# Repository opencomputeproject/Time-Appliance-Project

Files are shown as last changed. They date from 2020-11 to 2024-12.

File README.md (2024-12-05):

To save spec as PDF - select text below (including images) -> right click -> Print -> Save as PDF
# Time Card
#### Spec revision № 1.0
Time Card is the heart of the [Open Time Server](http://www.opentimeserver.com) Project.

You can find the [IEEE publication](https://ieeexplore.ieee.org/document/9918379) for it.

In addition to the ongoing IEEE PAR (P3335: Standard for Architecture and Interfaces for Time Card) on this [link](https://standards.ieee.org/ieee/3335/11127/)

This spec can be accessed using http://www.timingcard.com or http://timecard.ch  

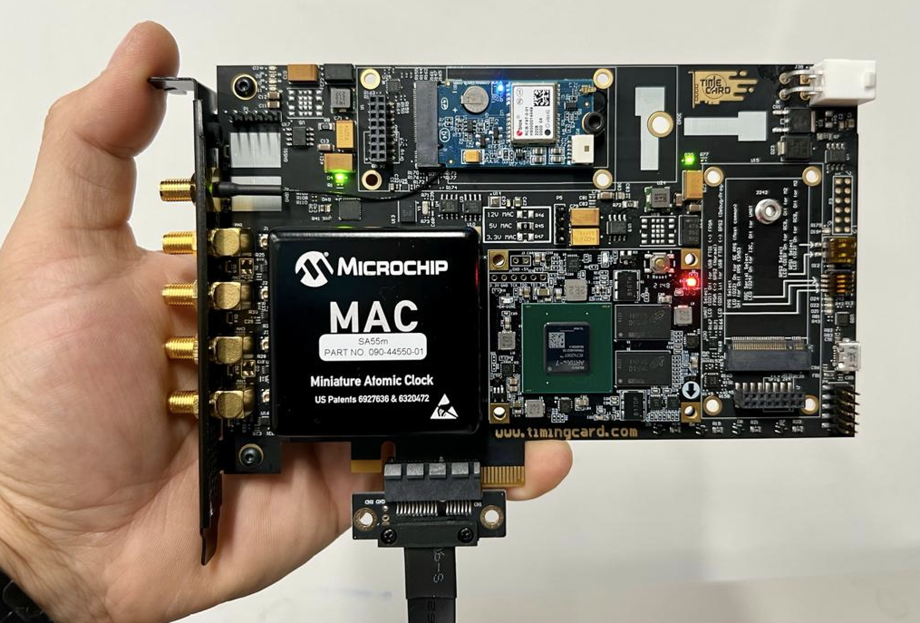
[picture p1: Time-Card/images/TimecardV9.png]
Time Card


## Table of Contents
1. [General](#General)
1. [Where can I get one](#Where-can-I-get-one)
1. [Form Factor](#Form-Factor)
1. [GNSS](#GNSS)
   1. [Receiver](#Receiver)
   1. [Security](#Security)
1. [Clock](#Clock)
1. [Bridge](#example)
   1. [Hardware Implementation](#Hardware-Implementation)
   1. [Software Implementation](#Software-Implementation)
1. [Interfaces](#Interfaces)
   1. [LED](#LED)
1. [Precision](#Precision)
1. [Repository content](#Repository-content)
1. [License](#License)

## List of images
List Of Images | Description
------------ | -------------
[Figure 1](#figure-1) | GNSS Receiver
[Figure 2](#figure-2) | Atomic Clock Example
[Figure 3](#figure-3) | Time Card Block Diagram
[Figure 4](#figure-4) | Bridge Block Diagram

## General

Time Server is a critical part of a PTP enabled network. It provides accurate time via GNSS while maintaining accuracy in case of GNSS failure via a high stability (and holdover) oscillator such as an atomic clock. Existing products in the market are often closed sourced and are far from having sufficient features. The Time Card project presents an open source solution via a PCIe card called Time Card which is called Open Time Server.

## Getting a Time Card

Here are 4 options to get your hands on this Time Card.

You can purchase the Time Card with the OCXO daughter card, the NEO-M9N RCB, fully programmed and assembled from Makerfabs. [Makerfabs Time Card](https://www.makerfabs.com/ocp-tap-time-card.html)

You have all necessary source code, BOM, Gerber files and binaries to build it yourself.
Follow these videos to Fabricate Time Cards with PCBWay, and purchase the accessories to assemble them.
* [Time Card PCBWay Fabrication and Assembly](https://www.youtube.com/watch?v=qPRaQU9TBTw)
* [Time Card Accessories](https://www.youtube.com/watch?v=4X3i5tge4S4)

The 3rd option is of course to source and produce the Time Card with the manufacturers you seek out yourself.

The 4th option is to purchase a Time Card available on the [OCP Marketplace](https://www.opencompute.org/products?refinementList%5Bhardware.categories.Cards%5D%5B0%5D=Time%20Cards) or other compatible Time Card from 3rd parties. Of course, this is the conveniet way to get your hands on a Time Card. Keep in mind, there is a cost associated with the vendors manufacturing the card and providing you all kinds of support in addition to their profit margins. It is good to know how much you are paying for parts and how much you are paying for the covenience.

## What is the price for parts of a Time Card

There are various parts that can sit on the Time Card as options and can change the total price. 
Here we have a breakdown:
* Time Card's mainboard: PCB with Assembly (Parts soldered on the PCB) should be about $200.
* Alinx SOM (AC7100B) should be about $250.
* GNSS recevier: The u-blox RCB-F9T is about $300. Other GNSS modules may vary in price based on their performance and capabilities in range of $50 to $500.
* Atomic Clock: The SA-53 is about $1995 (from microchipdirect). You can use a TCXO or OCXO board as well which can be around $100 - $200
So, in conclusion:
* A Time Card with a RCB-F9T GNSS and a TCXO costs about $200 + $250 + $300 + $100 = $850 in parts.
* A Time Card with a RCB-F9T GNSS and a MAC (SA-53) costs about $200 + $250 + $300 + $1995 = $2695 in parts.

## Time Card Derivatives
These are Time Cards made by other companies that are developed with different hardware yet compatible with the architecure and the driver of the Time Card:
* [Safran ART2](https://safran-navigation-timing.com/about-the-atomic-reference-time-card-art-card/) (fully open sourced and available on this [link](https://github.com/Orolia2s/art-card-board))
* [ADVA OSA5400](https://urldefense.com/v3/__https://www.oscilloquartz.com/en/products-and-services/embedded-timing-solutions/osa-5400-timecard__;!!Bt8RZUm9aw!74Qc6wh6_yFfgOhGUCr-rX5q6hd1NxC9HwjI7CwVO24C2SXXuzDXk4W3NjlSOZtTBWtvV11UzSicxA$)

## Form Factor
* Standard PCIe Stand-up Card
* Single Slot - Passive Cooling Solution
 
## GNSS
### Receiver
The GNSS receiver can be a product from ublock or any other vendor as long as it provides PPS output and the TOD using any suitable format.

This is the recommended module:  **u-blox RCB-F9T GNSS time module**

<a id="Figure-1">GNSS Receiver</a>
   
<p align="center">Figure 1. GNSS Receiver</p>

### Security
There are 2 main attack vectors on GNSS receiver
### Jamming
Jamming is the simplest form of attack. In order to keep operations while under attack the most reliable approach is to perform a long run holdover.  
See more about holdover in the [clock](#Clock) section.

### Spoofing
GNSS authenticity is relevant today. A mechanism to protect against over-the-air spoofing incidents is desirable.
With special equipment it is possible to simulate a GNSS constellation and spoof the receiver. Basic principals to protect against such attack:
* Use high-quality GNSS receivers which verify packet signature
* Disciplining implementations see more in [bridge](#bridge) section should protect against sudden jumps in time and space. For the datacenter use cases jump in space could be completely forbidden.

## Clock
GNSS requires "clear sky" to function properly. Moreover there were several historical events of a short term time jumps by some GNSS constallations.
Because of reliability and in combination with the security concerns an additional holdover should be performed by [high quality](https://www.meinbergglobal.com/english/specs/gpsopt.htm) XO. An example could be AC, OCXO, TCXO etc.
In order to perform sustainable operation we recommend to use an AC with a holdover ± 1us or HQ OCXO with a holdover ± 22 µs.

Atomic clock examples:
* [SA5X](https://www.microsemi.com/product-directory/embedded-clocks-frequency-references/5570-miniature-atomic-clock-mac-sa5x)
* [LN CSAC](https://www.microsemi.com/product-directory/embedded-clocks-frequency-references/4518-low-noise-csac-ln-csac)
* [mRO-50](https://www.orolia.com/products/atomic-clocks-oscillators/mro-50)
* [SA.45s](https://www.microsemi.com/product-directory/embedded-clocks-frequency-references/5207-space-csac)
* [DTA-100](https://www.taitien.com/wp-content/uploads/2021/10/XO-0191-Low-Power-Atomic-Oscillator-DTA-100-Series.pdf)

<p align="center">
microchip-mac-sa5x
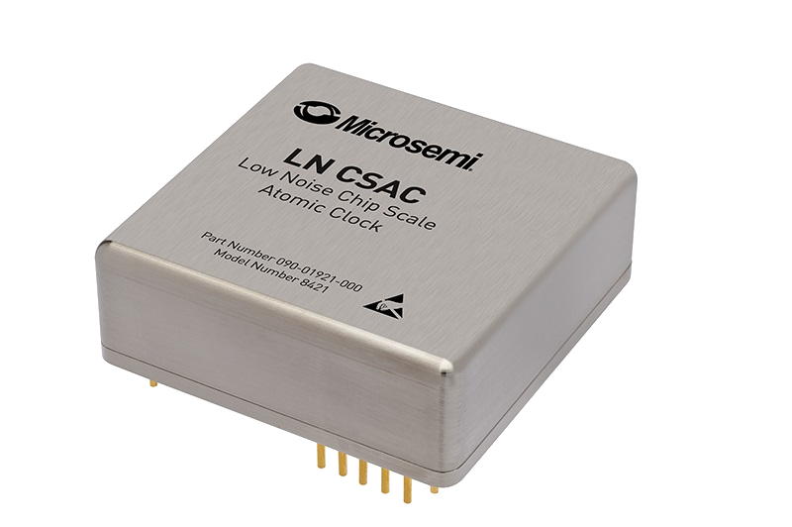
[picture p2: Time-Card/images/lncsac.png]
microchip-ln-csac

orolia-mro-50
microchip-mac-sa4x
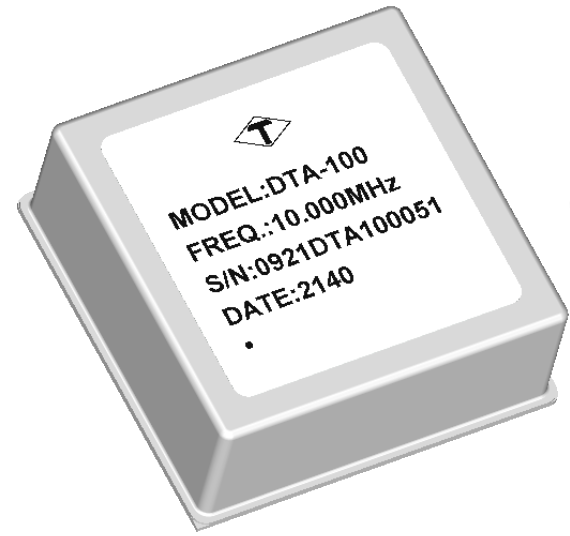
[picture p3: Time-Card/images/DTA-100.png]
taitien-dta-100

   
</p>

<p align="center">Figure 2. Atomic Clock Examples</p>

OCXO examples:
* [SiT5711](https://www.sitime.com/products/stratum-3e-ocxos/sit5711)
SiTime-SiT5711

* [DT-5151](https://www.taitien.com/ti-products/ultra-high-precision-disciplined-oscillator-dt-5151-series)
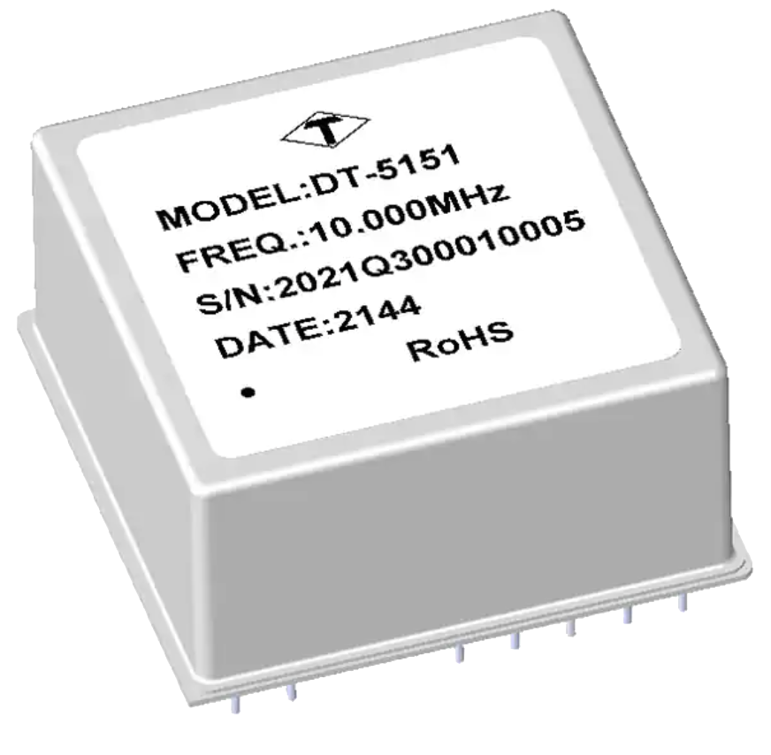
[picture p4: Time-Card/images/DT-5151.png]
taitien-dt-5151


* ROD2522S2 from Rakon, PPS disciplined oscillator

* Taitien PN: NJ-10M-075 , Stratum 3E oscillator footprint compatible with ROD2522S2

TCXO examples:
* [SiT5356](https://www.sitime.com/products/super-tcxo/sit5356)
SiT5356

* SiT5501 Super-TCXO

* Taitien PN: M0166-T-001-3 , footprint compatible with SiT5501 family

## Bridge

The bridge between the GNSS receiver and the Atomic clock can be implemented using software or hardware solutions. The hardware implementation is preferred and is our end goal.

### Hardware Implementation
Here is one of the examples of hardware implementations.
* FPGA is responsible for most of the functionality
* Exposed /dev/phc and /dev/pps are read by open source software such as ptp4l and chronyd

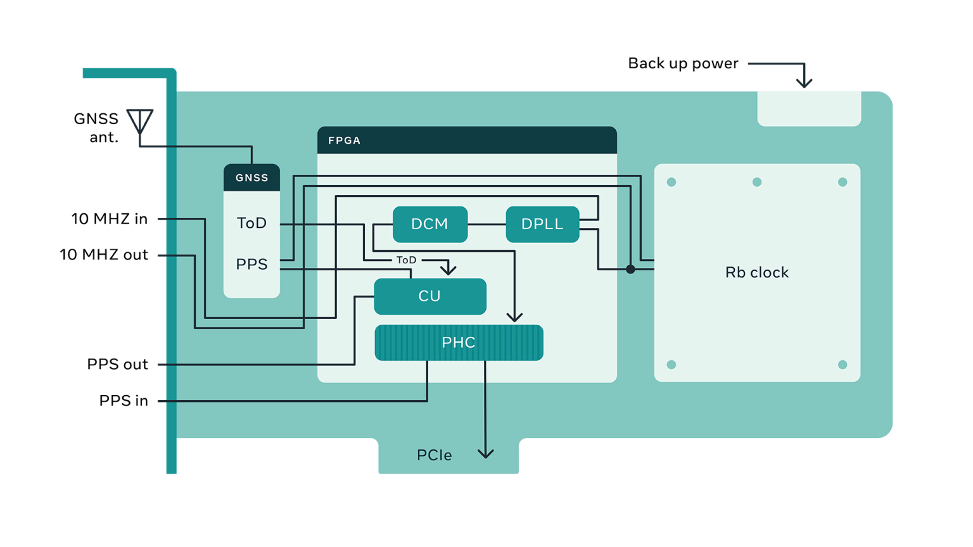
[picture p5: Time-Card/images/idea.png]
Time Card - Block Diagram


<p align="center">Figure 3. Time Card Block Diagram</p>

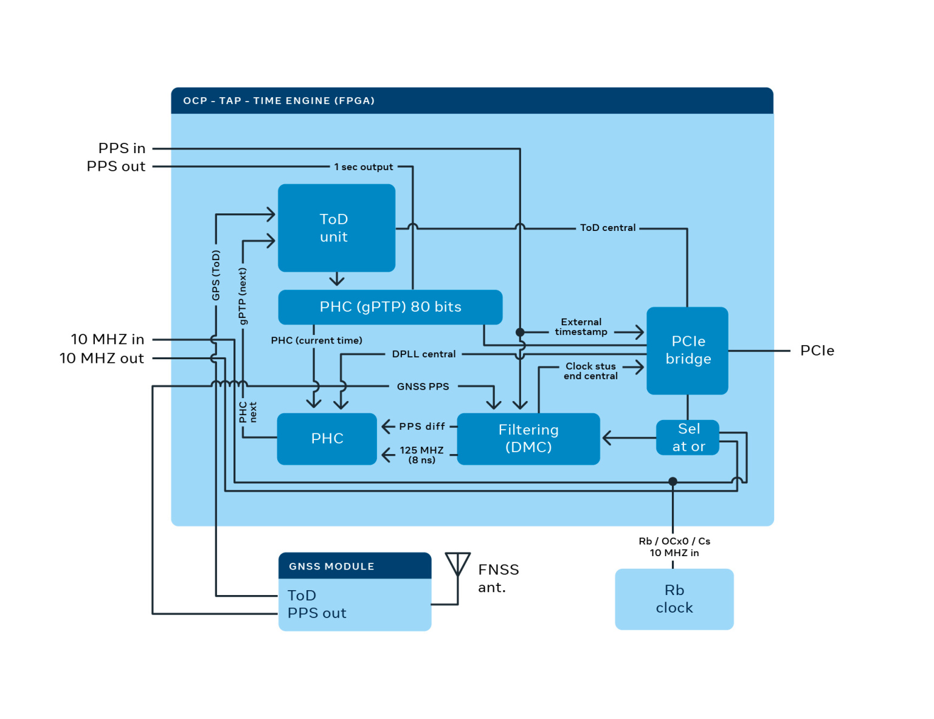
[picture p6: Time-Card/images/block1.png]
Bridge Block Diagram

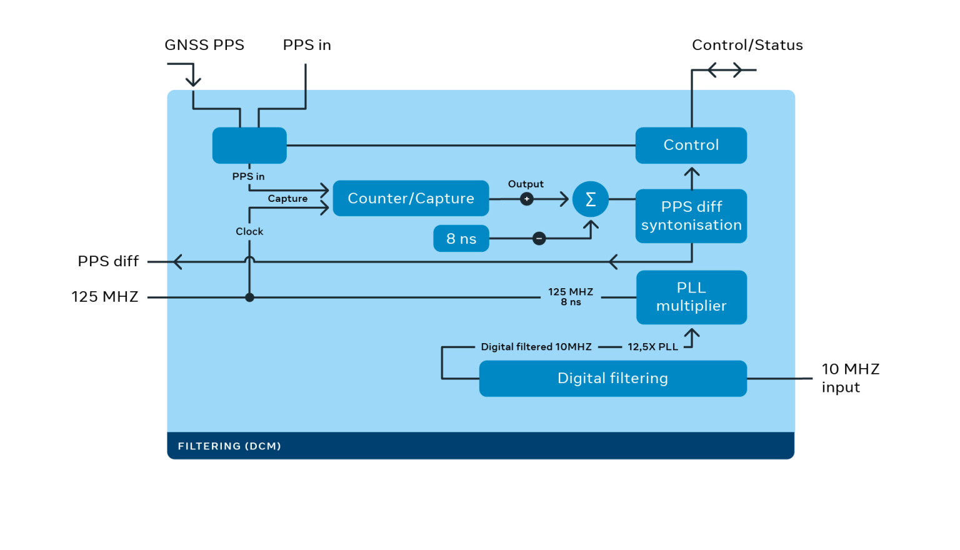
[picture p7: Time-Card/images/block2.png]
Bridge Block Diagram

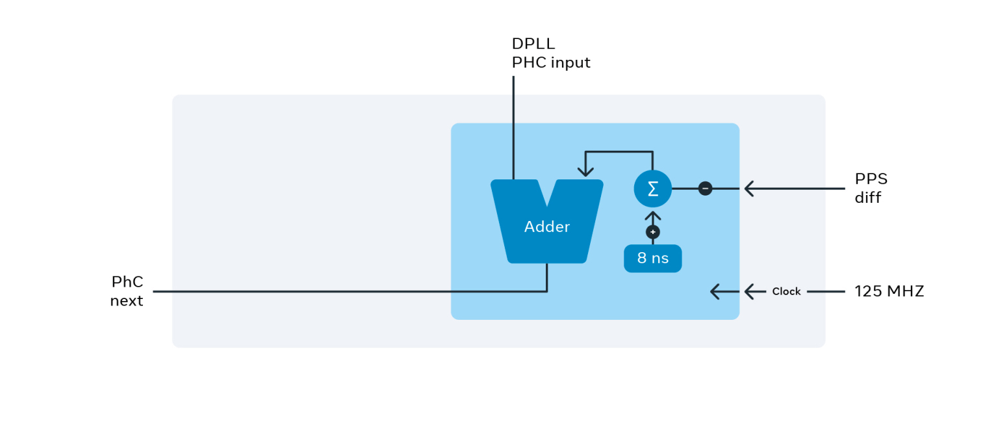
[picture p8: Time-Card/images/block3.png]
Bridge Block Diagram


<p align="center">Figure 4. Bridge Block Diagram</p>

### Software Implementation
Software implementation still requires most of the components, however the communication between components is done with user space software:
* GPSd exposing /dev/ppsY and provides TOD via SHM
* FPGA board reads 1 PPS from different sources
* Host daemon monitors the offset and steers oscillator
* phc2sys can copy data between clocks, including between GPSd and Atomic and then Atomic to PHC on the NIC

## Interfaces
* PCIe
    * PCIe x1 (18 pins) generation 1.0 or above on a x4 form-factor
    * Generic, supporting multiple OS versions
    * Exposes PHC device in Linux (/dev/ptpX) as well as PPS (/dev/ppsY)
    * Exposes leap second indicator to a shared memory segment read by chrony/ptp4l
* 1PPS / 10MHz SMA output
* 1PPS / 10MHz SMA input
* IRIG-B input output
* DCF77 input output
* GNSS Antenna SMA input

### LED

An LED should be used to provide externally visible status information of the time card. 

For example:
* Off - card is not powered or not properly fitted
* Solid green - card is powered, GNSS ok, 1PPS/10MHz output ok
* Flashing green - card is in warm-up, acquiring satellites
* Solid red - alarm / malfunction

# Precision
Time card got 4 SMA connectors that can be configured as outputs and outputs for various things such as 10Mhz, PHC, MAC, GNSS, GNSS2, IRIG, DCF for output and 10Mhz, PPS1, PPS2, TS1, TS2, IRIG, DCF for input.  
Using a Calnex Sentinel device are comparing various things. Here we are comparing the 1PPS output (Channel A) and the 10Mhz output (Channel B) from the MAC (SA.53).  
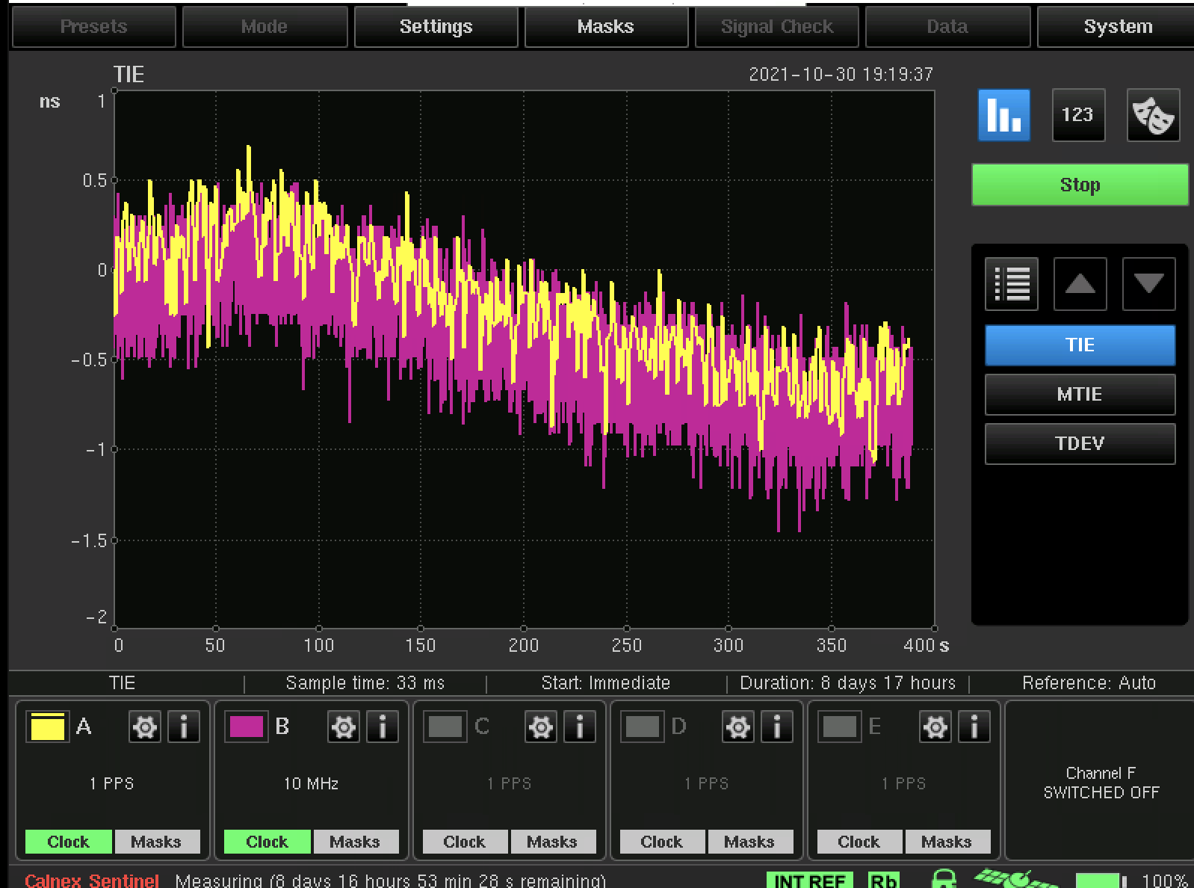
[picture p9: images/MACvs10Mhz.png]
Initial design


# Repository content

* Bill of Materials (parts from Digikey)
* Schematic and PCB of the time card
* Driver (Kernel Module) CentOS 8
* CAD files for the custom PCIe bracket 

# Credits
Hereby we would like to thank these individuals who helped with the initiative, archirecture, design, software development, hardware issue maintanance and upgrades.
Individual | Main Contribution
---------------- | -------------
[Mike Lambeta](https://github.com/AlphaBetaPhi)     | Layout and Schematic Design
[Oleg Obleukhov](https://github.com/leoleovich)   | Open Time Server Software
[Jonathan Lemon](https://github.com/jlemon)   | Inital Linux Driver
[Thomas Schaub](https://github.com/thschaub)    | FPGA Design and Code
Joyce Hsu        | Logo Design
[Armando Pinales](https://github.com/armando-jp)  | RCB Boards
[Julian St.James](https://github.com/julianstj1)  | Hardware Upgrade
[Vadim Fedorenko](https://github.com/vvfedorenko)  | Driver Upgrade
[Spencer Burns](https://github.com/spencerburns)    | PCIe Bracket Design
Collin Richardson| Placement Optimization
[Nhan Hoang](https://github.com/nhanhoang83)       | PCIe Bracket Upgrade
[Ahmad Byagowi](https://github.com/ahmadexp)    | Initial Idea and Architecture

# License
Contributions to this Specification are made under the terms and conditions set forth in Open Web Foundation Contributor License Agreement (“OWF CLA 1.0”) (“Contribution License”) by: 
 
 Facebook

You can review the signed copies of the applicable Contributor License(s) for this Specification on the OCP website at http://www.opencompute.org/products/specsanddesign 
Usage of this Specification is governed by the terms and conditions set forth in Open Web Foundation Final Specification Agreement (“OWFa 1.0”) (“Specification License”).   
 
You can review the applicable Specification License(s) executed by the above referenced contributors to this Specification on the OCP website at http://www.opencompute.org/participate/legal-documents/
 Notes: 
 
1)     The following clarifications, which distinguish technology licensed in the Contribution License and/or Specification License from those technologies merely referenced (but not licensed), were accepted by the Incubation Committee of the OCP:  
 
None

NOTWITHSTANDING THE FOREGOING LICENSES, THIS SPECIFICATION IS PROVIDED BY OCP "AS IS" AND OCP EXPRESSLY DISCLAIMS ANY WARRANTIES (EXPRESS, IMPLIED, OR OTHERWISE), INCLUDING IMPLIED WARRANTIES OF MERCHANTABILITY, NON-INFRINGEMENT, FITNESS FOR A PARTICULAR PURPOSE, OR TITLE, RELATED TO THE SPECIFICATION. NOTICE IS HEREBY GIVEN, THAT OTHER RIGHTS NOT GRANTED AS SET FORTH ABOVE, INCLUDING WITHOUT LIMITATION, RIGHTS OF THIRD PARTIES WHO DID NOT EXECUTE THE ABOVE LICENSES, MAY BE IMPLICATED BY THE IMPLEMENTATION OF OR COMPLIANCE WITH THIS SPECIFICATION. OCP IS NOT RESPONSIBLE FOR IDENTIFYING RIGHTS FOR WHICH A LICENSE MAY BE REQUIRED IN ORDER TO IMPLEMENT THIS SPECIFICATION.  THE ENTIRE RISK AS TO IMPLEMENTING OR OTHERWISE USING THE SPECIFICATION IS ASSUMED BY YOU. IN NO EVENT WILL OCP BE LIABLE TO YOU FOR ANY MONETARY DAMAGES WITH RESPECT TO ANY CLAIMS RELATED TO, OR ARISING OUT OF YOUR USE OF THIS SPECIFICATION, INCLUDING BUT NOT LIMITED TO ANY LIABILITY FOR LOST PROFITS OR ANY CONSEQUENTIAL, INCIDENTAL, INDIRECT, SPECIAL OR PUNITIVE DAMAGES OF ANY CHARACTER FROM ANY CAUSES OF ACTION OF ANY KIND WITH RESPECT TO THIS SPECIFICATION, WHETHER BASED ON BREACH OF CONTRACT, TORT (INCLUDING NEGLIGENCE), OR OTHERWISE, AND EVEN IF OCP HAS BEEN ADVISED OF THE POSSIBILITY OF SUCH DAMAGE.

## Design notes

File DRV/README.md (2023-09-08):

# Driver

Driver is based on a kernel module for CentOS and Ubunutu. 
Kernel 5.12+ is recommended

## Instruction
Make sure vt-d option is enabled in BIOS.   
Run the remake followed by modprobe ptp_ocp

## Outcome
```
$ ls -g /sys/class/timecard/ocp0/
total 0
-r--r--r--. 1 root 4096 Sep  8 18:20 available_clock_sources
-r--r--r--. 1 root 4096 Sep  8 18:20 available_sma_inputs
-r--r--r--. 1 root 4096 Sep  8 18:20 available_sma_outputs
-rw-r--r--. 1 root 4096 Sep  8 18:20 clock_source
lrwxrwxrwx. 1 root    0 Sep  8 18:20 device -> ../../../0000:02:00.0
-rw-r--r--. 1 root 4096 Sep  8 18:20 external_pps_cable_delay
-r--r--r--. 1 root 4096 Sep  8 18:20 gnss_sync
-rw-r--r--. 1 root 4096 Sep  8 18:20 internal_pps_cable_delay
-rw-r--r--. 1 root 4096 Sep  8 18:20 irig_b_mode
-rw-r--r--. 1 root 4096 Sep  8 18:20 pci_delay
drwxr-xr-x. 2 root    0 Sep  8 18:20 power
lrwxrwxrwx. 1 root    0 Sep  8 18:20 ptp -> ../../ptp/ptp4
-r--r--r--. 1 root 4096 Sep  8 18:20 serialnum
-rw-r--r--. 1 root 4096 Sep  8 18:20 sma1_in
-rw-r--r--. 1 root 4096 Sep  8 18:20 sma2_in
-rw-r--r--. 1 root 4096 Sep  8 21:04 sma3_out
-rw-r--r--. 1 root 4096 Sep  8 21:04 sma4_out
lrwxrwxrwx. 1 root    0 Sep  8 18:20 subsystem -> ../../../../../../class/timecard
lrwxrwxrwx. 1 root    0 Sep  8 18:20 ttyGNSS -> ../../tty/ttyS5
lrwxrwxrwx. 1 root    0 Sep  8 18:20 ttyMAC -> ../../tty/ttyS6
lrwxrwxrwx. 1 root    0 Sep  8 18:20 ttyNMEA -> ../../tty/ttyS7
-rw-r--r--. 1 root 4096 Sep  8 18:20 uevent
-rw-r--r--. 1 root 4096 Sep  8 18:20 utc_tai_offset
```

The main resource directory is accessed through the /sys/class/timecard/ocpN directory, which provides links to the various TimeCard resources.  The device links can easily be used in scripts:

```
  tty=$(basename $(readlink /sys/class/timecard/ocp0/ttyGNSS))
  ptp=$(basename $(readlink /sys/class/timecard/ocp0/ptp))

  echo "/dev/$tty"
  echo "/dev/$ptp"
```

After successfully loading the driver, one will see:
* PTP POSIX clock, linking to the physical hardware clock (PHC) on the Time Card (`/dev/ptp4`) 
* GNSS serial `/dev/ttyS5` 
* Atomic clock serial `/dev/ttyS6`
* NMEA Master serial `/dev/ttyS7`
* i2c (`/dev/i2c-*`) device

Now, one can use standard `linuxptp` tools such as `phc2sys` or `ts2phc` to copy, sync, tune, etc... See more in [software](/Software) section

## Driver is included in the mainstream Linux Kernel
* Initial primitive version ([5.2](https://git.kernel.org/pub/scm/linux/kernel/git/netdev/net-next.git/commit/?id=a7e1abad13f3f0366ee625831fecda2b603cdc17))
* Exposing all devices version ([5.15](https://git.kernel.org/pub/scm/linux/kernel/git/torvalds/linux.git/commit/?id=773bda96492153e11d21eb63ac814669b51fc701))

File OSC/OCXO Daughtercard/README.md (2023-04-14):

# OCXO Daughter Card
A daughter card compatible with the LOFF atomic clock footprint of the Time Card to support various OCXOs from different vendors.

Developed by Christopher Robles, David Griffin, Julian St. James, Ahmad Byagowi, Mike Lambeta for Time Card usage.

Current oscillators supported:
1. Abracon AOCJYR
2. Rakon ROD2552S2
3. SiTime SiT5711 / SiT5721
4. SiTime SiT5501
5. Rakon RFP045

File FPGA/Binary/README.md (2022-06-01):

# FPGA Binary Sources
The FPGA design based on NetTimeLogic Cores is available as binary-only (bitstream) specifically for the Timecard, which however can be used free of charge without restrictions.

The binaries are for two different hardware versions available:

- **Production** 

- **SOM** (System On Module)

More details can be found in the subfolders.

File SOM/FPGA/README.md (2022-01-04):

# System on Module

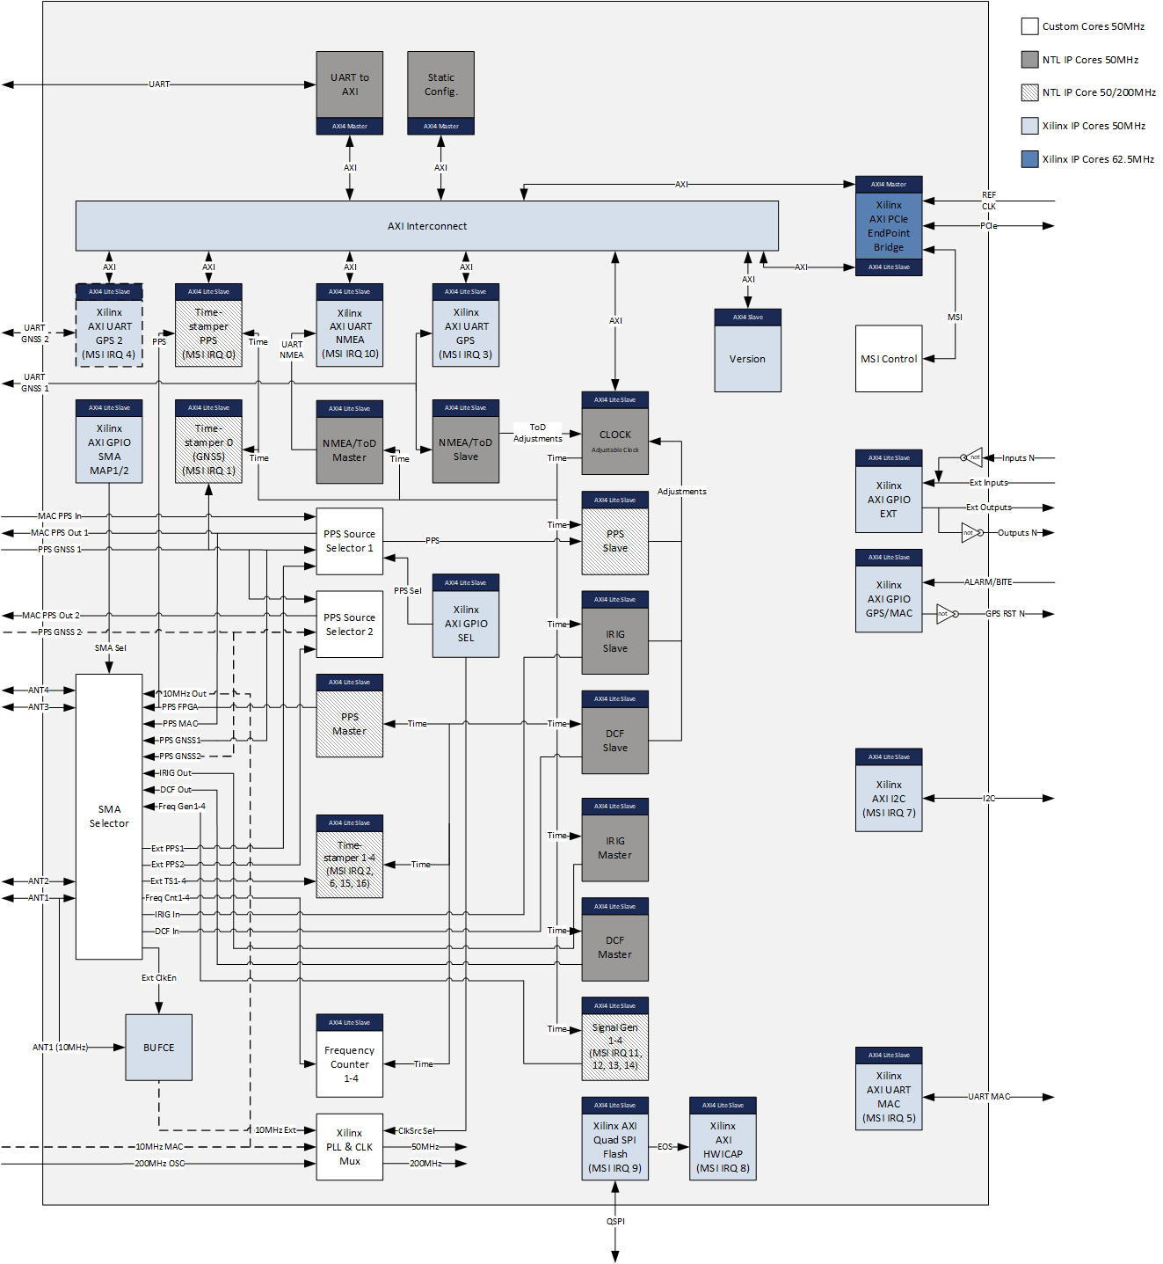
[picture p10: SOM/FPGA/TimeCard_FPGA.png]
Time Card FPGA


The FPGA bitstream can be configured to various options. Currently it is based on the [NetTimeLogic clock module](https://www.nettimelogic.com/clock-products.php).  <br />

Check the [Readme.pdf](https://github.com/opencomputeproject/Time-Appliance-Project/blob/master/Time-Card/SOM/FPGA/Readme.pdf) for more details about the implementation.  <br />

In the [Doc folder](https://github.com/opencomputeproject/Time-Appliance-Project/tree/master/Time-Card/SOM/FPGA/Doc) are all relevant documents about the integrated IP Cores (e.g. register description). <br />

## The FPGA starts with a static configuration with following settings: ##
* PPS (including TOD) is used as correction input for the clock  
* PPS Slave Pulse detection on rising edge
* PPS Slave cable delay 0
* TOD Slave UART Baudrate is 115200
* TOD Slave UART polarity default
* TOD Slave in UBX Mode, all GNSS and no messages disabled
* PPS Master polarity rising edge
* PPS Master cable delay 0
* PPS Master pulse width 100 ms
* Clock, PPS Slave, TOD Slave and PPS Master are enabled
* All Timestampers are disabled
* IRIG Slave/Master are disabled
* DCF Slave/Master are disabled
* TOD/NMEA Master is disabled

## In the Binaries folder are the bitstreams for the SOM Module. ## 
* TimeCard.bit to flash the FPGA (volatile)
* Factory_TimeCard.bin to load the SPI flash via JTAG (Golden Image + Update Image)
* TimeCard.bin to updated the SPI flash via SPI starting @ 0x00400000 (Update Image only)
    
The version for AX7103 will be not longer maintained. 

## Firmware upgrade
```
$ dmesg | grep ptp_ocp | head -1
[   21.527678] ptp_ocp 0000:11:00.0: enabling device (0140 -> 0142)
$ cp TimeCard.bin /lib/firmware
$ devlink dev flash pci/0000:11:00.0 file TimeCard.bin
```

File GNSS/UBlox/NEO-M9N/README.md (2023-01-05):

# UBX NEO-M9N GNSS module
 Module has not been tested with Time Card.

## Programming the GNSS module

To program the GNSS module you can either use the UBX provided hardware or a simple FTDI-TTL3v3 cable (please note, you have to use the 3v3 version oppose to the 5v). Here is a simple wiring digram to program the GNSS module.

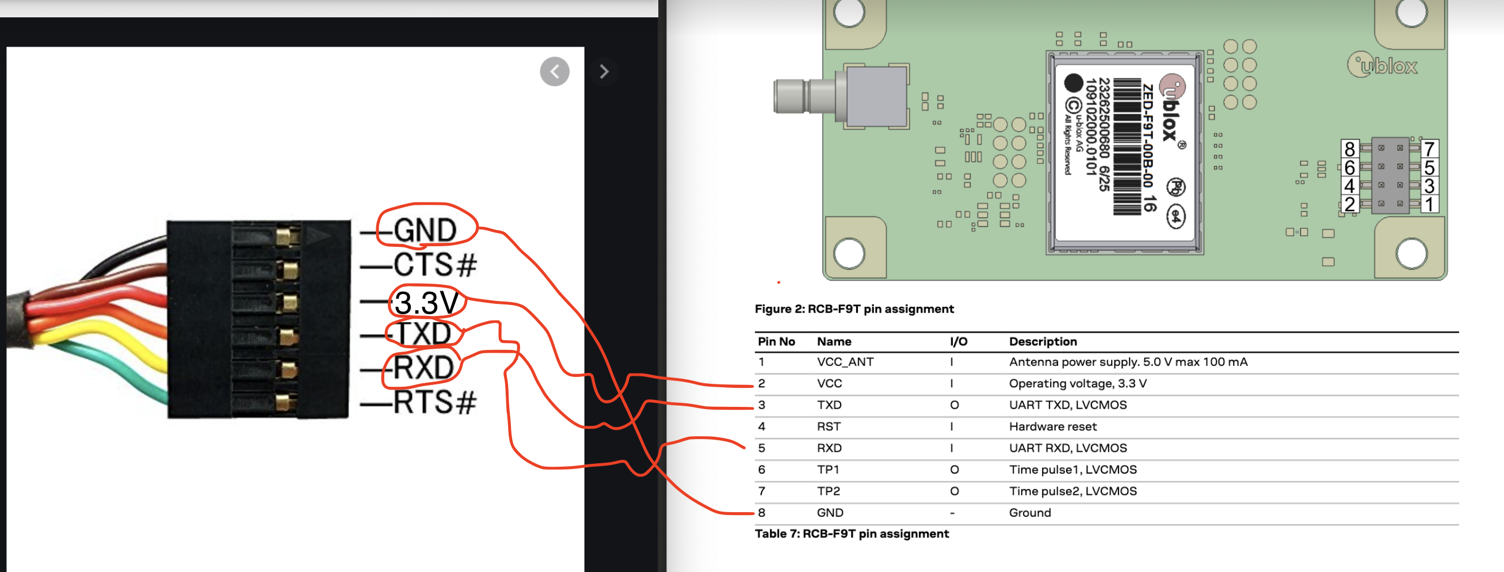
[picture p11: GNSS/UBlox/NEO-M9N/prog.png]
UBX GNSS simple programmer


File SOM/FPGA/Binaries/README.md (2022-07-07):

# SOM Module Binaries
- **200T** TimeCard FPGA binaries for the SOM with the Artix7 200T FPGA (AC7200)
- **AX7103_Baseboard** TimeCard FPGA binaries for the AX7103 base board (not maintained anymore)
- **Debug** TimeCard FPGA binaries for special debug use cases (not maintained anymore)
- **FirmwareUpdateTest** TimeCard FPGA binaries for firmware update tests

## In this folder are the bitstreams for the SOM Module. ## 
* TimeCard.bit to flash the FPGA (volatile)
* Factory_TimeCard.bin to load the SPI flash via JTAG (Golden Image + Update Image)
* TimeCard.bin to updated the SPI flash via SPI starting @ 0x00400000 (Update Image only)
* TimeCard_Gotham.bin is basically the same as TimeCard.bin but the file has additional header information ([See tft tool](https://github.com/opencomputeproject/Time-Appliance-Project/tree/master/Software/tft))
    
The version for AX7103 will be not longer maintained. 

## Firmware upgrade
```
$ dmesg | grep ptp_ocp | head -1
[   21.527678] ptp_ocp 0000:11:00.0: enabling device (0140 -> 0142)
$ cp TimeCard.bin /lib/firmware
$ devlink dev flash pci/0000:11:00.0 file TimeCard.bin
```

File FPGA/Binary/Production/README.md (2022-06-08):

***!! Important !!***

This version is **NOT** compatible with the SOM Module (e.g. AC7100B).
The binaries for the Time Card with the **System On Module (SOM)** can be found here:
[SOM Version](../../../SOM)

# FPGA for the production version of the Time Card
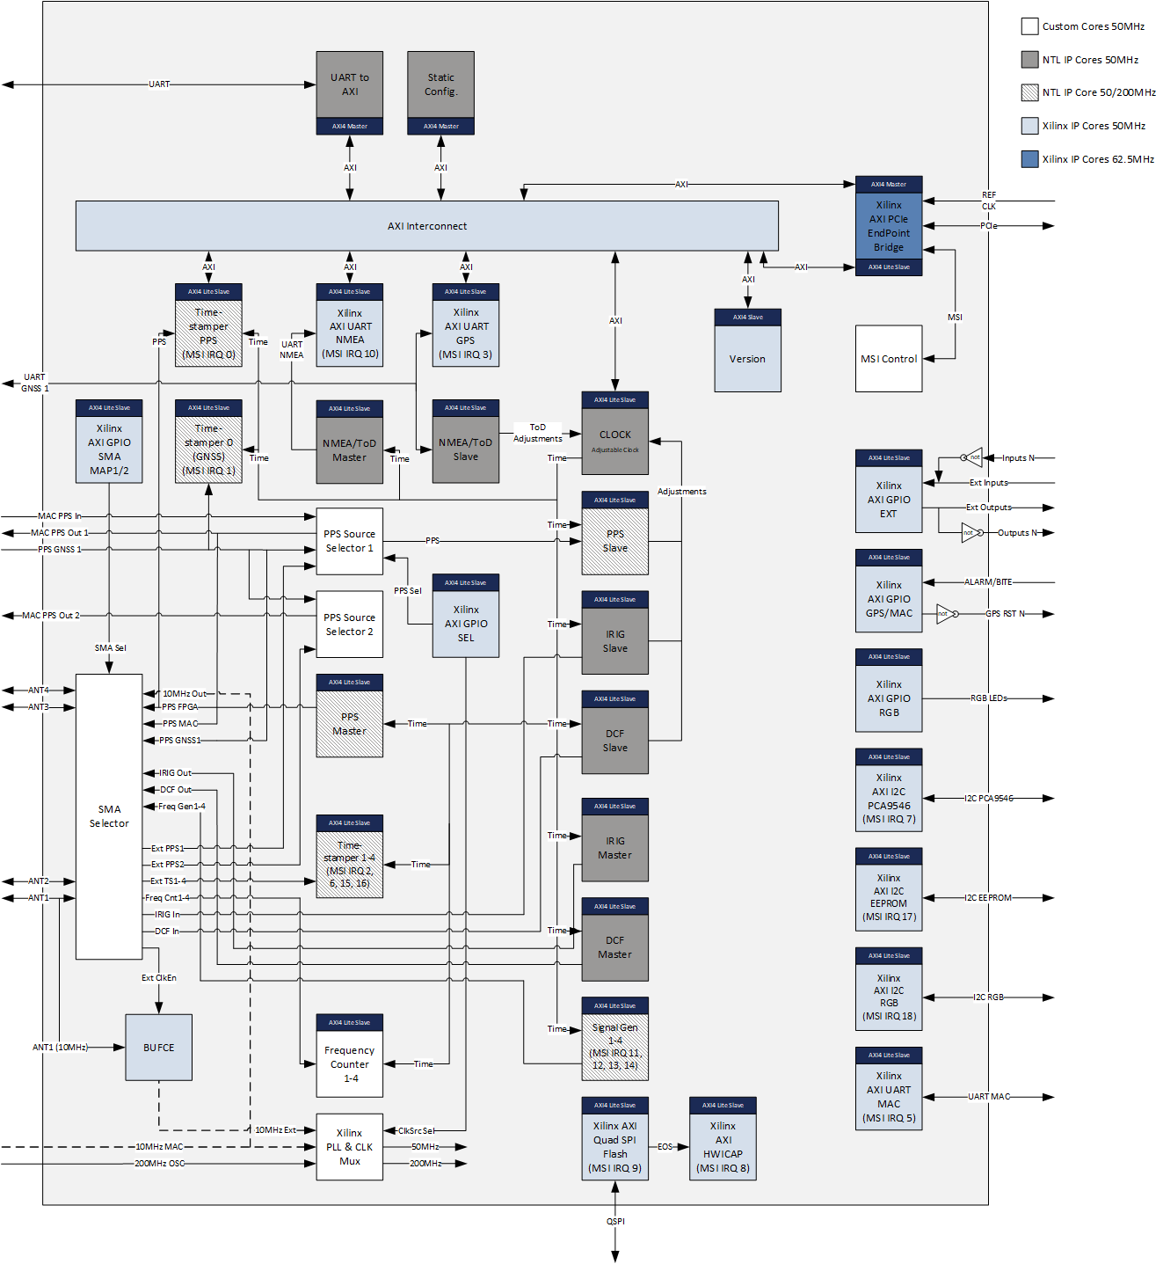
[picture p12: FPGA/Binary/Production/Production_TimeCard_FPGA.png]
Production Time Card FPGA


The FPGA bitstream can be configured to various options. Currently it is based on the [NetTimeLogic clock module](https://www.nettimelogic.com/clock-products.php). <br />

Check the [Readme_Production.pdf](Readme_Production.pdf) for more details about the implementation. <br />

In the [Doc folder](../../../SOM/FPGA/Doc) are all relevant documents about the integrated IP Cores (e.g. register description). <br />

## The FPGA starts with a static configuration with following settings: ##
* PPS (including TOD) is used as correction input for the clock  
* PPS Slave Pulse detection on rising edge
* PPS Slave cable delay 0
* TOD Slave UART Baudrate is 115200
* TOD Slave UART polarity default
* TOD Slave in UBX Mode, all GNSS and no messages disabled
* PPS Master polarity rising edge
* PPS Master cable delay 0
* PPS Master pulse width 100 ms
* Clock, PPS Slave, TOD Slave and PPS Master are enabled
* All Timestampers are disabled
* IRIG Slave/Master are disabled
* DCF Slave/Master are disabled
* TOD/NMEA Master is disabled

## In the Binaries folder are the bitstreams for the FPGA. ## 
* TimeCardProduction.bit to flash the FPGA (volatile)
* Factory_TimeCardProduction.bin to load the SPI flash via JTAG (Golden Image + Update Image)
* TimeCardProduction.bin to updated the SPI flash via SPI starting @ 0x00400000 (Update Image only)
    
## Firmware upgrade
```
$ dmesg | grep ptp_ocp | head -1
[   21.342167] ptp_ocp 0000:11:00.0: enabling device (0140 -> 0142)
$ cp TimeCardProduction.bin /lib/firmware
$ devlink dev flash pci/0000:11:00.0 file TimeCardProduction.bin
```

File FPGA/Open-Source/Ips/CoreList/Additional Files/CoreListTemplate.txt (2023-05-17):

// Core Type Nr:
// Invalid/End                          0x0
// TC Core List Core Type               0x1
// TC Adjustable Clock Core Type        0x2
// TC Signal Generator Core Type        0x3
// TC Signal Timestamper Core Type      0x4
// TC PPS Generator Core Type           0x5
// TC Frequency Counter                 0x6
// TC Clock Detector Core Type          0x7
// TC SMA Selector Core Type            0x8
// TC PPS Source Selector Core Type     0x9
// TC FPGA Version Core Type            0xA
// TC PPS Slave Core Type               0xB
// TC TOD Slave Core Type               0xC
// TC Dummy Axi Slave Core Type         0xD
// Xilinx AXI PCIe Core Type            0x10000
// Xilinx AXI GPIO Core Type            0x10001
// Xilinx AXI IIC Core Type             0x10002
// Xilinx AXI UART Core Type            0x10003
// Xilinx AXI HWICAP Core Type          0x10004
// Xilinx AXI QUAD SPI FLASH Core Type  0x10005

// Core Inst Nr range: [0 - (N-1)], where N is the number of instantiations of the core in the design

// Version Nr has the format 0xMMmmBBBB, where MM is the Major version (8 bits), mm is the Minor version (8 bits), BBBB is the Built version (16 bits)

// AddressRangeLow is the offset address of the core's AXI slave, 0xFFFFFFFF when the core does not have AXI slave

// AddressRangeHigh is the highest address of the core's AXI slave

// Interrupt Nr range: [0x0-0x1F], 0xFFFFFFFF when the core does not have Interrupt

// Interrupt Sensitivity: bit0: 0=Edge/1=Level bit1: 0=ActiveLow/1=ActiveHigh

// Magic Word: Core in ascii chars (maximum "TextWidth_Con" number of ascii chars)

// CoreTypeNr CoreInstNr VersionNr AddressRangeLow AddressRangeHigh InterruptNr Sensitivity MagicWord
00000001 00000000 00010000 01300000 0130FFFF FFFFFFFF FFFFFFFF TC Core List
00000002 00000000 00010000 01000000 0100FFFF FFFFFFFF FFFFFFFF TC Adj Clock
00000003 00000000 00010000 010D0000 010DFFFF 0000000B 00000002 TC Sig Generator 1
00000003 00000001 00010000 010E0000 010EFFFF 0000000C 00000002 TC Sig Generator 2
00000003 00000002 00010000 010F0000 010FFFFF 0000000D 00000002 TC Sig Generator 3
00000003 00000003 00010000 01100000 0110FFFF 0000000E 00000002 TC Sig Generator 4
00000004 00000000 00010000 01010000 0101FFFF 00000001 00000002 TC Sig Timestamper GNSS PPS
00000004 00000001 00010000 01020000 0102FFFF 00000002 00000002 TC Sig Timestamper 1
00000004 00000002 00010000 01060000 0106FFFF 00000006 00000002 TC Sig Timestamper 2
00000004 00000003 00010000 010C0000 010CFFFF 00000000 00000002 TC Sig Timestamper FPGA PPS
00000004 00000004 00010000 01110000 0111FFFF 0000000F 00000002 TC Sig Timestamper 3
00000004 00000005 00010000 01120000 0112FFFF 00000010 00000002 TC Sig Timestamper 4
00000005 00000000 00010000 01030000 0103FFFF FFFFFFFF FFFFFFFF TC PPS Generator
00000006 00000000 00010000 01200000 0120FFFF FFFFFFFF FFFFFFFF TC Freq Counter 1
00000006 00000001 00010000 01210000 0121FFFF FFFFFFFF FFFFFFFF TC Freq Counter 2
00000006 00000002 00010000 01220000 0122FFFF FFFFFFFF FFFFFFFF TC Freq Counter 3
00000006 00000003 00010000 01230000 0123FFFF FFFFFFFF FFFFFFFF TC Freq Counter 4
00000007 00000000 00010000 00130000 0013FFFF FFFFFFFF FFFFFFFF TC Clock Detector
00000008 00000000 00010000 00140000 0014FFFF FFFFFFFF FFFFFFFF TC SMA Selector Inst0 Slave1
00000008 00000000 00010000 00220000 0022FFFF FFFFFFFF FFFFFFFF TC SMA Selector Inst0 Slave2
00000009 00000000 00010000 FFFFFFFF FFFFFFFF FFFFFFFF FFFFFFFF TC PPS Source Selector 0
00000009 00000001 00010000 FFFFFFFF FFFFFFFF FFFFFFFF FFFFFFFF TC PPS Source Selector 1
0000000A 00000000 00010000 00020000 00020FFF FFFFFFFF FFFFFFFF TC FPGA Version
0000000B 00000000 00010000 01040000 0104FFFF FFFFFFFF FFFFFFFF TC PPS Slave
0000000C 00000000 00010000 01050000 0105FFFF FFFFFFFF FFFFFFFF TC TOD Slave
00010000 00000000 02090000 00010000 00010FFF FFFFFFFF FFFFFFFF Xilinx AXI PCIe
00010001 00000000 02000000 00100000 0010FFFF FFFFFFFF FFFFFFFF Xilinx AXI GPIO ext
00010001 00000001 02000000 00110000 0011FFFF FFFFFFFF FFFFFFFF Xilinx AXI GPIO GNSS MAC
00010002 00000000 02000000 00150000 0015FFFF 00000007 00000003 Xilinx AXI IIC
00010003 00000000 02000000 00160000 0016FFFF 00000003 00000003 Xilinx AXI UART GNSS 1
00010003 00000001 02000000 00170000 0017FFFF 00000004 00000003 Xilinx AXI UART GNSS 2
00010003 00000002 02000000 00180000 0018FFFF 00000005 00000003 Xilinx AXI UART MAC
00010003 00000003 02000000 00190000 0019FFFF 0000000A 00000003 Xilinx AXI UART reserved
00010003 00000004 02000000 001A0000 001AFFFF 00000013 00000003 Xilinx AXI UART ext
00010004 00000000 03000000 00300000 0030FFFF 00000008 00000003 Xilinx AXI HWICAP
00010005 00000000 03020000 00310000 0031FFFF 00000009 00000002 Xilinx AXI Quad SPI flash

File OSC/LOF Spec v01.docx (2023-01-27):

# OCP-TAP

# Large Oscillator Form-Factor

# (LOF)

Version 0.1

Hardware Specification

Author: OCP-TAP Group

Table of Contents

# 1. Overview

The Large Oscillator Form-Factor (LOF) module is a source of stable output frequency to the Time Card.

This stable frequency also provides Time Cards a holdover reference when GNSS is denied.

The OCP-TAP LOF standardizes the dimensions, layout and connectivity of modular LOF for OCP-TAP Time Cards.

A standard modular LOF allows Time Card customers to interchange and upgrade Oscillators with ease, and lets manufacturers an easier path to release new and improved holdover and stability mechanism compatible with OCP-TAP Time Cards.

The LOF can lead to a faster pace of innovation and development as manufacturers can focus on creating new components rather than iterating on the Time Servers, Time Cards and NICs for each new product or revision.

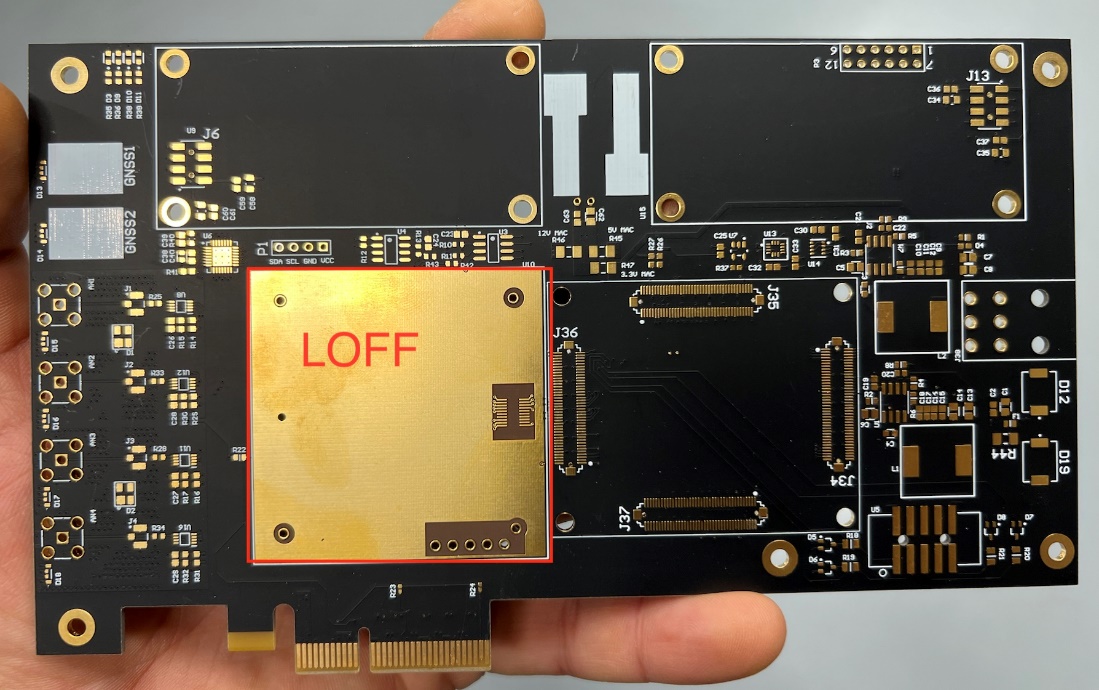
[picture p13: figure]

Figure 1 - Time-Card with LOF

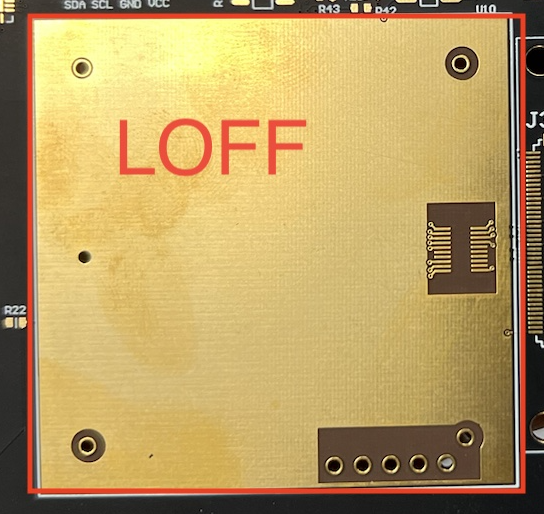
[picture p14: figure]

Figure 2 – Zoom-In View of LOF

## 1.1. Acronyms

Abbreviation | Definition
LOF | Large Oscillator Form-Factor
NIC | Network Interface Card
PPS | Pulse Per Second
PTP | Precision Time Protocol
RCB | Receiver Carrier Board
TAP | Time Appliance Project

# 1. Scope

This document defines the technical details for base specification for Large Oscillator Form-Factor (LOF).

Any supplier seeking OCP recognition for a hardware product based on this Specification must be 100% compliant with all features or requirements described

# 2. License

## 2.1. Open Web Foundation (OWF) CLA

Contributions to this Specification are made under the terms and conditions set forth in Open Web Foundation Modified Contributor License Agreement (“OWF CLA 1.0”) (“Contribution License”) by:

Meta, NVIDIA

Usage of this Specification is governed by the terms and conditions set forth in Open Web Foundation Modified Final Specification Agreement (“OWFa 1.0”) (“Specification License”).

You can review the applicable OWFa1.0 Specification License(s) referenced above by the contributors to this Specification on the OCP website at http://www.opencompute.org/participate/legal-documents/. For actual executed copies of either agreement, please contact OCP directly.

Notes:

1. The above license does not apply to the Appendix or Appendices. The information in the Appendix or Appendices is for reference only and non-normative in nature.

NOTWITHSTANDING THE FOREGOING LICENSES, THIS SPECIFICATION IS PROVIDED BY OCP "AS IS" AND OCP EXPRESSLY DISCLAIMS ANY WARRANTIES (EXPRESS, IMPLIED, OR OTHERWISE), INCLUDING IMPLIED WARRANTIES OF MERCHANTABILITY, NON-INFRINGEMENT, FITNESS FOR A PARTICULAR PURPOSE, OR TITLE, RELATED TO THE SPECIFICATION. NOTICE IS HEREBY GIVEN, THAT OTHER RIGHTS NOT GRANTED AS SET FORTH ABOVE, INCLUDING WITHOUT LIMITATION, RIGHTS OF THIRD PARTIES WHO DID NOT EXECUTE THE ABOVE LICENSES, MAY BE IMPLICATED BY THE IMPLEMENTATION OF OR COMPLIANCE WITH THIS SPECIFICATION. OCP IS NOT RESPONSIBLE FOR IDENTIFYING RIGHTS FOR WHICH A LICENSE MAY BE REQUIRED IN ORDER TO IMPLEMENT THIS SPECIFICATION. THE ENTIRE RISK AS TO IMPLEMENTING OR OTHERWISE USING THE SPECIFICATION IS ASSUMED BY YOU. IN NO EVENT WILL OCP BE LIABLE TO YOU FOR ANY MONETARY DAMAGES WITH RESPECT TO ANY CLAIMS RELATED TO, OR ARISING OUT OF YOUR USE OF THIS SPECIFICATION, INCLUDING BUT NOT LIMITED TO ANY LIABILITY FOR LOST PROFITS OR ANY CONSEQUENTIAL, INCIDENTAL, INDIRECT, SPECIAL OR PUNITIVE DAMAGES OF ANY CHARACTER FROM ANY CAUSES OF ACTION OF ANY KIND WITH RESPECT TO THIS SPECIFICATION, WHETHER BASED ON BREACH OF CONTRACT, TORT (INCLUDING NEGLIGENCE), OR OTHERWISE, AND EVEN IF OCP HAS BEEN ADVISED OF THE POSSIBILITY OF SUCH DAMAGE.

## 2.2. Acknowledgements

The OCP-TAP LOF specification is the outcome of a collaborative effort of OCP-TAP members and contributors.

OCP-TAP would like to acknowledge the following members and companies for their contributions

- Kory Stone, Taitien
- Ahmad Byagowi, Meta
- Armando Julies Pinales, Meta
- Julian St. James, Meta
- Elad Wind, NVIDIA

# 3. Compliance with OCP Tenets

The LOF complies to the following OCP (4 out of 5) tenets.

The ideals behind open sourcing stipulate that everyone benefits when we share and work together. Any open-source project is designed to promote sharing of design elements with peers and to help them understand and adopt those contributions.

## 3.1. Openness

The LOF takes a step into modularity of the OCP-TAP Time Card, by allowing a modular interchangeable Oscillators for holdover and precision to be easily provisioned into Time Cards.

This standard modular form-factor allows for more vendors to drive their innovation and make time-aware data centers ubiquitous

## 3.2. Efficiency

With this modularity Time-Cards functionality can be designed and qualified separately from the holdover and precision and allow for parallel technological cycles to happen simultaneously. Technical improvements in the LOF do not mandate a change in the Time Card.

## 3.3. Impact

The LOF improves the time-to-market advantage of Oscillator such as the ability to introduce atomic clocks and more.

## 3.4. Scale

With the interest generated around Time Card standard, we expect multiple vendors to design and obtain product recognition (OCP Accepted™ or OCP Inspired™) for a thriving marketplace of Time-Cards, RCBs and LOFs at scale.

# 4. Physical Specifications

LOF module footprint, I/O and mechanical requirements are defined for interoperability with the OCP-TAP Time Card specification.

The LOF consists of a 2 inch (50.8 mm) x 2 inch (50.8 mm) x 0.98 inch (25 mm) PCB.

## 4.1. Labeling

Labels will contain information about the part number and the serial number. The serial number indicates the initial time of manufacture.

## 4.2. I/O

The LOF contains the following I/O interfaces:

PPS connection is a calibrating and disciplining feature that helps correct frequency and phase drifts (aging rate) from the primary clock to an externally applied PPS reference signal.

Pin # | Name | Type | Description
1 | NC/Tune | Input | Not connected or used for analog steering (tune)
2 | GND | Power | Power Return
3 | RF OUT | Output | Clock output, usually 10Mhz
4 | GND | Power | Power Return
5 | VCC | Power | Power Supply, 3v3, 5v or 12v (important to check)
6 | Lock | Output | Indicator of lock, goes high on lock, LVCMOS
7 | TXD | Output | UART TXD, LVCMOS
8 | RXD | Input | UART RXD, LVCMOS
9 | PPS In | Input | OPTIONAL 3.3v
10 | PPS Out | Output | OPTIONAL 3.3v

## 4.3. Foot Print and Layout

The LOF baseplate consists of 10 (of which 2 are optional) pins

The screw holes (to be depicted) are optional as long as the locations are kept.

Apply grounded keep-out areas for the screw holes

## 4.3.1. Bottom View

23mm

40.64mm

40.64mm

6.07mmmmh

3.0mm x 4

1

2

3

4

5

10 9 8 7 6

50.8mm

50.8mm

## 4.3.2. Side View

25mm

# 5. Hardware Management

We intentionally leave the hardware management of the LOF for the vendors to define and implement. This will cover programming of the ICs, diagnostics, etc.

# 6. Version Table

Date | Version # | Author | Description
January 23, 2023 | 0.1 | OCP-TAP | First draft

# 7. References

[1] OCP-TAP Time Card specification and all other related OCP-TAP specs can be found here https://github.com/opencomputeproject/Time-Appliance-Project

# Appendix A - Checklist for IC approval of this Specification (to be completed by contributor(s) of this Spec)

Complete all the checklist items in the table with links to the section where it is described in this spec or an external document .

Item | Status or Details | Link to detailed explanation
Is this contribution entered into the OCP Contribution Portal? | Yes or No | If no, please state reason.
Was it approved in the OCP Contribution Portal? | Yes or No | If no, please state reason.
Is there a Supplier(s) that is building a product based on this Spec? (Supplier must be an OCP Solution Provider) | Yes or No | List Supplier Name(s)
Will Supplier(s) have the product available for GENERAL AVAILABILITY within 120 days? | Yes or No | If more time is required, please state the timeline and reason for extension request. Please have each Supplier fill out Appendix B.

# Appendix B-__ <supplier name> - OCP Supplier Information and Hardware Product Recognition Checklist

(to be provided by each supplier seeking OCP recognition for a Hardware Product based on this specification)

Company:

Contact Info:

Product Name:

Product SKU#:

Link to Product Landing Page:

The following is needed for OCP hardware product recognition:

For OCP Inspired™

- All Suppliers must be a Silver, Gold or Platinum Member.
- Declare product is 100% compliant with specification
- Complete the OCP (https://docs.google.com/spreadsheets/d/1p7g_bPWzgXDDTkxbOEOkLrbvfKmqVWspKOi7J20yJcE/copy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)Inspired™ (https://docs.google.com/spreadsheets/d/1p7g_bPWzgXDDTkxbOEOkLrbvfKmqVWspKOi7J20yJcE/copy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) Product Recognition Checklist (https://docs.google.com/spreadsheets/d/1p7g_bPWzgXDDTkxbOEOkLrbvfKmqVWspKOi7J20yJcE/copy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), which includes hardware management conformance checks and security profile.

For OCP Accepted™

- All Suppliers must be an OCP Member. All corporate membership levels are eligible.
- Complete the OCP Accepted™ Product Recognition Checklist (https://docs.google.com/spreadsheets/d/1SNqQYCta4CVsZsZcRRVR5A779YyCHxA2gLSINlFtnTs/copy), which includes hardware management conformance checks, security profile and open system firmware conformance checks.
- Submit a design package meeting OCP Hardware Design Guideline Contribution Checklist (https://docs.google.com/document/u/0/d/1SdLlXxn_jz__t8I33ATraYvHDYX3go3w_rR4LJ1PNTE/edit) (if not already submitted by the contributor). If already submitted, declare the product is 100% compliant with the design package.
- Submit a firmware package including a firmware image, build scripts, documentation, test results and a tool that verifies modifications

Please complete the OCP Inspired™ Product Recognition Submission Checklist or OCP Accepted™ Product Recognition Checklist and the following table.

Item | Details | Links
Which product recognition? | OCP Accepted™ or OCP Inspired™ | Provide link for the appropriate Product Checklist
If OCP Accepted™, who provided the Design Package? | | Link to OCP Contribution Database
Where can a potential adopter purchase the product? | | Link to OCP Marketplace

# Appendix C - Contribution Process FAQs

As a contributor to a hardware specification, here are some questions that often come up.

Q1. What type of hardware specification am I contributing to OCP? Is it any of the below?
  a. base specification for a de-facto standard (new standard with no hardware product on the horizon)
  b. base specification for an intended physical <hardware product type> (product may be coming but within the next 1-2 years)
  c. modification of an existing specification (state which existing spec is being modified)
    i. either a complete revision update or
    ii. a minor version update
  d. design spec (based on an existing base specification) with more refined design details (product coming in 12-15months)
  e. a detailed specification for a <hardware product type> for a very specific product being available in 3-6months of approval of this Spec
  f. If none of the above, please contact OCP Staff for better direction.
Q2. How do I know if what I am contributing will be accepted by OCP?
  a. Before contributing any specifications, please contact either OCP Staff (Archna Haylock or Michael Schill) or the Project Lead for the Project that best represents your contribution. For example, if you are contributing a Server Specification, please contact one of the Server Project Leads. You can see all the Projects here (https://www.opencompute.org/projects).
  b. They will help you with your contribution and help you navigate the process.
Q3. What is the contribution process for my hardware spec?
  a. Follow the flow for your spec type here (https://docs.google.com/presentation/d/1PlXGLhCdgVEGWQ0hLYdAQEH5qCScwYij/edit).
  b. This flow is subject to change so please check with the OCP Staff for more information or any questions.
Q4. What if my spec is not developed yet and I want to collaborate with other companies?
  a. Please contact either OCP Staff (Archna Haylock or Michael Schill) or the Project Lead for the Project that best represents your contribution.
  b. They will help you find other collaborators and help you with the contribution process for a multi-party contribution.
Q5. I have a question on the Contribution License Agreement.
  a. Please contact OCP Staff and we can help you with questions.
Q6. Do I need to have a product in order to contribute a spec?
  a. Please see Q1. Some types of specs do not require an immediate product. Some do. Please work with the OCP Staff on better direction on your specification type.

Date: January 2023 Page 2

Open Compute Project • TAP Large Oscillator Form-Factor (LOF)

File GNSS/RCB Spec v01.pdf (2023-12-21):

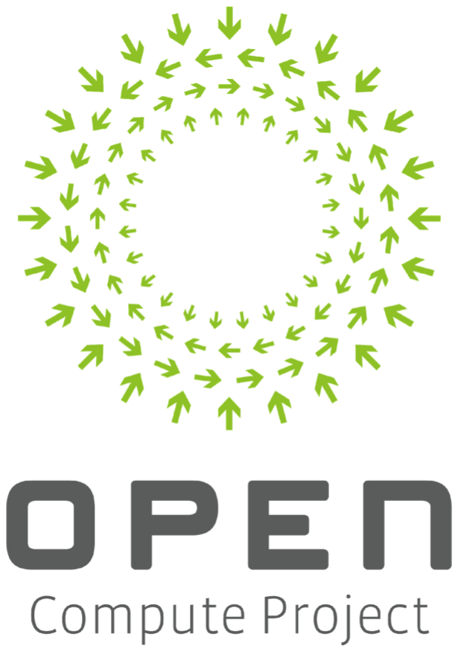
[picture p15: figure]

# OCP-TAP

# Receiver Carrier Board (RCB)

# Form-Factor

Version 0.1

Hardware Specification

Author: OCP-TAP Group

Open Compute Project • TAP Receiver Carrier Board (RCB)

Date: January 2023 | Page 2

Table of Contents

Appendix A - Checklist for IC approval of this Specification (to be completed by contributor(s)

Appendix B-__ <supplier name> - OCP Supplier Information and Hardware Product

Open Compute Project • TAP Receiver Carrier Board (RCB)

## 1. Overview

The Receiver Carrier Board (RCB) is a GNSS receiver module that provides PPS output and the TOD to the Time Card.

The OCP-TAP RCB form factor standardizes the dimensions, layout and connectivity of modular GNSS receivers for OCP-TAP Time Cards.

A standard modular RCB Form Factor allows Time Card customers to interchange and upgrade GNSS receivers with ease, and lets manufacturers an easier path to release new and improved GNSS receiver that are compatible with OCP-TAP Time Cards.

The RCB Form Factor can lead to a faster pace of innovation and development as manufacturers can focus on creating new components rather than iterating on the Time Servers, Time Cards and NICs for each new product or revision.

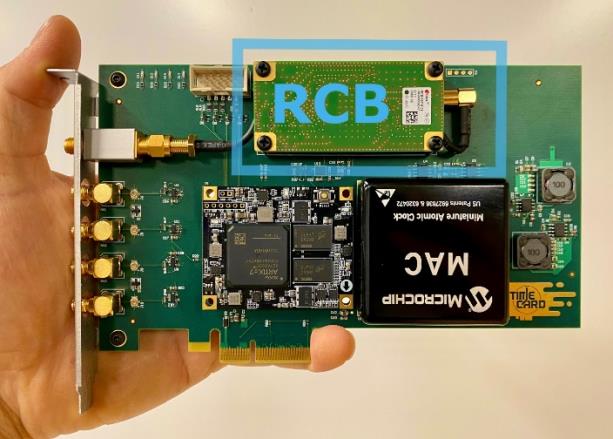
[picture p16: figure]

Figure 1 - Time-Card with RCB

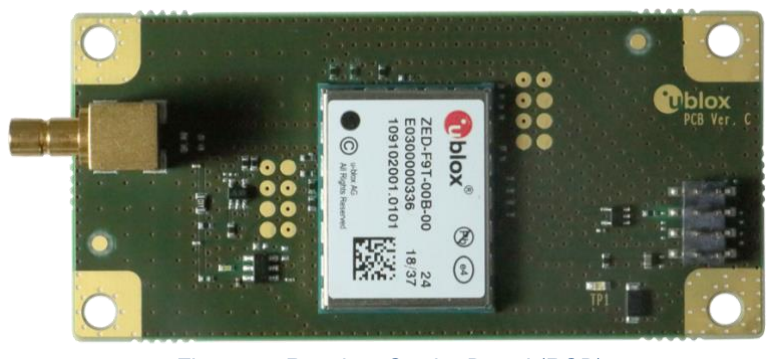
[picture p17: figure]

Figure 2 - Receiver Carrier Board (RCB)

Open Compute Project • TAP Receiver Carrier Board (RCB)

1.1.Acronyms

Abbreviation | Definition
GNSS | Global Navigation Satellite System
RCB | Receiver Carrier Board
TAP | Time Appliance Project
PPS | Pulse Per Second
ToD | Time of Day
NIC | Network Interface Card
PTP | Precision Time Protocol

## 2. Scope

This document defines the technical details for base specification for Receiver Carrier Board (RCB).
Any supplier seeking OCP recognition for a hardware product based on this Specification must be 100% compliant with all features or requirements described

## 3. License

3.1.Open Web Foundation (OWF) CLA

Contributions to this Specification are made under the terms and conditions set forth in Open Web Foundation Modified Contributor License Agreement (“OWF CLA 1.0”) (“Contribution License”) by:
Meta, NVIDIA

Usage of this Specification is governed by the terms and conditions set forth in Open Web Foundation Modified Final Specification Agreement (“OWFa 1.0”) (“Specification License”).

You can review the applicable OWFa1.0 Specification License(s) referenced above by the contributors to this Specification on the OCP website at http://www.opencompute.org/participate/legal-documents/. For actual executed copies of either agreement, please contact OCP directly.

Notes:

1. The above license does not apply to the Appendix or Appendices. The information in the Appendix or Appendices is for reference only and non-normative in nature.

NOTWITHSTANDING THE FOREGOING LICENSES, THIS SPECIFICATION IS PROVIDED BY OCP "AS IS" AND OCP EXPRESSLY DISCLAIMS ANY WARRANTIES (EXPRESS, IMPLIED, OR OTHERWISE), INCLUDING IMPLIED WARRANTIES OF MERCHANTABILITY, NON-INFRINGEMENT, FITNESS FOR A PARTICULAR PURPOSE, OR TITLE, RELATED TO THE SPECIFICATION. NOTICE IS HEREBY GIVEN, THAT OTHER RIGHTS NOT GRANTED

Open Compute Project • TAP Receiver Carrier Board (RCB)

AS SET FORTH ABOVE, INCLUDING WITHOUT LIMITATION, RIGHTS OF THIRD PARTIES WHO DID NOT EXECUTE THE ABOVE LICENSES, MAY BE IMPLICATED BY THE IMPLEMENTATION OF OR COMPLIANCE WITH THIS SPECIFICATION. OCP IS NOT RESPONSIBLE FOR IDENTIFYING RIGHTS FOR WHICH A LICENSE MAY BE REQUIRED IN ORDER TO IMPLEMENT THIS SPECIFICATION. THE ENTIRE RISK AS TO IMPLEMENTING OR OTHERWISE USING THE SPECIFICATION IS ASSUMED BY YOU. IN NO EVENT WILL OCP BE LIABLE TO YOU FOR ANY MONETARY DAMAGES WITH RESPECT TO ANY CLAIMS RELATED TO, OR ARISING OUT OF YOUR USE OF THIS SPECIFICATION, INCLUDING BUT NOT LIMITED TO ANY LIABILITY FOR LOST PROFITS OR ANY CONSEQUENTIAL, INCIDENTAL, INDIRECT, SPECIAL OR PUNITIVE DAMAGES OF ANY CHARACTER FROM ANY CAUSES OF ACTION OF ANY KIND WITH RESPECT TO THIS SPECIFICATION, WHETHER BASED ON BREACH OF CONTRACT, TORT (INCLUDING NEGLIGENCE), OR OTHERWISE, AND EVEN IF OCP HAS BEEN ADVISED OF THE POSSIBILITY OF SUCH DAMAGE.

3.2.Acknowledgements

The OCP-TAP RCB specification is the outcome of a collaborative effort of OCP-TAP members and contributors.

OCP-TAP would like to acknowledge the following members and companies for their contributions

- Charlie Ferreira, Furuno Electric
- Tomasz Widomski, Elproma
- Wim Rouwet, NXP
- Jos Prakash Arakkaparambil Vacko, u-blox
- Samuli Pietilä, u-blox
- Nobuyasu Shiga, Individual Contributor
- Ahmad Byagowi, Meta
- Armando Julies Pinales, Meta
- Julian St. James, Meta
- Elad Wind, NVIDIA

Open Compute Project • TAP Receiver Carrier Board (RCB)

## 4. Compliance with OCP Tenets

The RCB Form Factor complies to the following OCP (4 out of 5) tenets.
The ideals behind open sourcing stipulate that everyone benefits when we share and work together. Any open-source project is designed to promote sharing of design elements with peers and to help them understand and adopt those contributions.

4.1.Openness

The RCB takes one step into modularity of the OCP-TAP Time-Card, by allowing a modular interchangeable GNSS receivers to be easily provisioned into Time Cards.
This standard modular form factor allows for more vendors to drive their innovation and make time-aware data centers ubiquitous

4.2.Efficiency

With this modularity Time-Cards functionality such as hold-over and precision can be designed and qualified separately from the GNSS receiver, and allow for parallel technological cycles to happen simultaneously. Technical improvements in the RCB do not mandate a change in the Time Card.

4.3.Impact

The RCB improves the time-to-market advantage of GNSS innovations, such as the ability to add support for new constellations, for dual-band constellation receivers, and more.

4.4.Scale

With the interest generated around Time Card standard, we expect multiple vendors to design and obtain product recognition (OCP Accepted™ or OCP Inspired™) for a thriving marketplace of Time-Cards and RCBs at scale.

Open Compute Project • TAP Receiver Carrier Board (RCB)

### 5. Physical Specifications

The RCB module footprint, I/O and mechanical requirements are defined for interoperability with the OCP-TAP Time-Card specification.

The RCB consists of a 67.25 mm x 31.75 mm PCB.

5.1.Labeling

Labels will contain information about the part number and the serial number. The serial number indicates the initial time of manufacture.

5.2.I/O

The RCB contains the following I/O interfaces:
1. Time-Card Board Connector
2. Antenna Coax SMA or SMB Connector
3. LED indicators are optional and per vendor’s implementation

5.3.Board Connector – Pinout

The Time-Card Board Connector is a standard 8-pin header which holds the main functions of the RCB
1. UART – ToD from the GNSS communication
2. PPS Out
Pin # | Name | Type | Description
1 | VCC_ANT | Power | Antenna Power Supply, 3v3 to 5v with Max 100mA
2 | VCC | Power | Receiver Power, 3v3 with Max 200mA
3 | TXD | Output | UART TDX, LVCMOS
4 | RST | Input | Hardware Reset
5 | RXD | Input | UART RXD, LVCMOS
6 | TP1 | Output | Time Pulse (1-PPS recommended), LVCMOS
7 | TP2 | Output / Input | Time Pulse (output, input, unused or specific), LVCMOS
8 | GND | Power | Power Return, Ground

5.4.Foot Print and Layout

This defines the mechanical form factor and layout of the RCB. Specifically, we call out the placement of
1. Antenna connector [ ]
2. Time-Card Board Connector [J1]
3. Time-Card mounting holes

We call out 4 screw holes, their locations and dimensions are mandatory. Apply grounded keep-out areas for the screw holes

Open Compute Project • TAP Receiver Carrier Board (RCB)

### 5.4.1. Bottom View

he grayed (to be sketched) zone defines a height-limit that shall not exceed TBD mm, and is meant to allow usability of the real estate on the mating Time Card

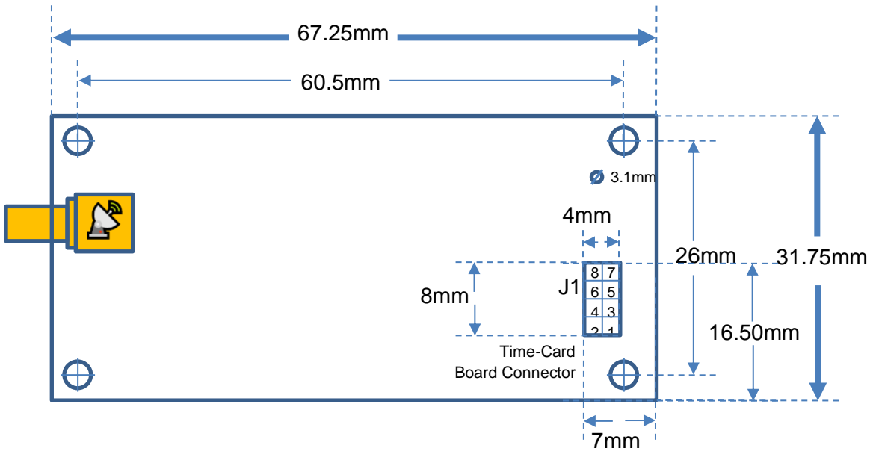
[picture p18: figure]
Time-Card Board Connector

### 5.4.2. Side View

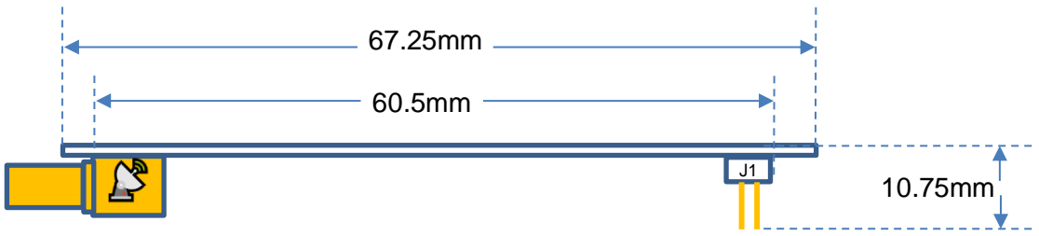
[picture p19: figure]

### 6. Hardware Management

We intentionally leave the hardware management of the RCB for the vendors to define and implement. This will cover programming of the ICs, diagnostics, etc.

### 7. Version Table

Open Compute Project • TAP Receiver Carrier Board (RCB)

Date | Version # | Author | Description
January 23, 2023 | 0.1 | OCP-TAP | First draft

### 8. References

[1] OCP-TAP Time Card specification and all other related OCP-TAP specs can be found here https://github.com/opencomputeproject/Time-Appliance-Project

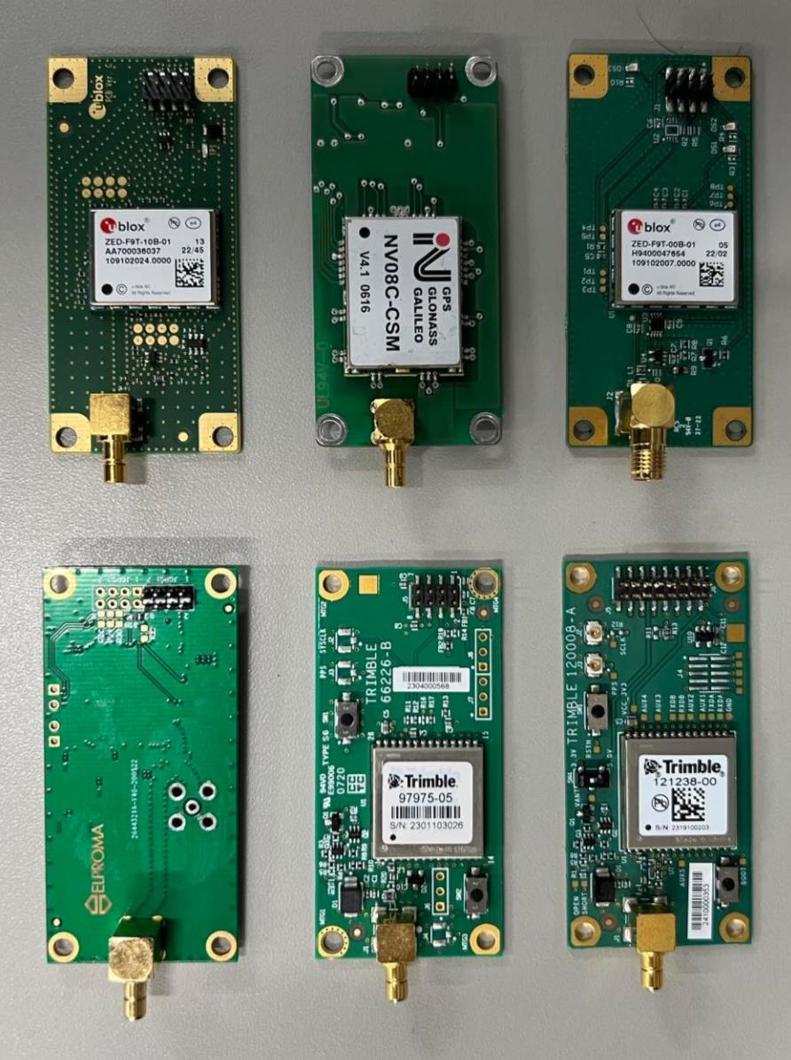
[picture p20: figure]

[2] Assortments of RCBs

Open Compute Project • TAP Receiver Carrier Board (RCB)

Open Compute Project • TAP Receiver Carrier Board (RCB)

## Appendix A - Checklist for IC approval of this Specification (to be completed by contributor(s) of this Spec)

Complete all the checklist items in the table with links to the section where it is described in this spec or an external document .

Item | Status or Details | Link to detailed explanation
Is this contribution entered into the OCP Contribution Portal? | Yes or No | If no, please state reason.
Was it approved in the OCP Contribution Portal? | Yes or No | If no, please state reason.
Is there a Supplier(s) that is building a product based on this Spec? (Supplier must be an OCP Solution Provider) | Yes or No | List Supplier Name(s)
Will Supplier(s) have the product available for GENERAL AVAILABILITY within 120 days? | Yes or No | If more time is required, please state the timeline and reason for extension request. Please have each Supplier fill out Appendix B.

Open Compute Project • TAP Receiver Carrier Board (RCB)

## Appendix B-__ <supplier name> - OCP Supplier Information and Hardware Product Recognition Checklist

(to be provided by each supplier seeking OCP recognition for a Hardware Product based on this specification)

Company:
Contact Info:

Product Name:
Product SKU#:
Link to Product Landing Page:

The following is needed for OCP hardware product recognition:

For OCP Inspired™
- All Suppliers must be a Silver, Gold or Platinum Member.
- Declare product is 100% compliant with specification
- Complete the OCP I (https://docs.google.com/spreadsheets/d/1p7g_bPWzgXDDTkxbOEOkLrbvfKmqVWspKOi7J20yJcE/copy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)nspired™ (https://docs.google.com/spreadsheets/d/1p7g_bPWzgXDDTkxbOEOkLrbvfKmqVWspKOi7J20yJcE/copy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) Product Recognition Checklist, (https://docs.google.com/spreadsheets/d/1p7g_bPWzgXDDTkxbOEOkLrbvfKmqVWspKOi7J20yJcE/copy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) which includes hardware management conformance checks and security profile.

For OCP Accepted™
- All Suppliers must be an OCP Member. All corporate membership levels are eligible.
- Complete the OCP Accepted™ Product Recognition Checklist, (https://docs.google.com/spreadsheets/d/1SNqQYCta4CVsZsZcRRVR5A779YyCHxA2gLSINlFtnTs/copy) which includes hardware management conformance checks, security profile and open system firmware conformance checks.
- Submit a design package meeting OCP Hardware Design Guideline Contribution Checklist (https://docs.google.com/document/u/0/d/1SdLlXxn_jz__t8I33ATraYvHDYX3go3w_rR4LJ1PNTE/edit) (if not already submitted by the contributor). If already submitted, declare the product is 100% compliant with the design package.
- Submit a firmware package including a firmware image, build scripts, documentation, test results and a tool that verifies modifications
- Submit the BMC source code, if applicable to product type

Please complete the OCP Inspired™ Product Recognition Submission Checklist or OCP Accepted™ Product Recognition Checklist and the following table.

Item | Details | Links
Which product recognition? | OCP Accepted™ or OCP Inspired™ | Provide link for the appropriate Product Checklist

Open Compute Project • TAP Receiver Carrier Board (RCB)

If OCP Accepted™, who provided the Design Package? | Link to OCP Contribution Database
Where can a potential adopter purchase the product? | Link to OCP Marketplace

Open Compute Project • TAP Receiver Carrier Board (RCB)

## Appendix C - Contribution Process FAQs

As a contributor to a hardware specification, here are some questions that often come up.

Q1. What type of hardware specification am I contributing to OCP? Is it any of the below?
a. base specification for a de-facto standard (new standard with no hardware product on the horizon)
b. base specification for an intended physical <hardware product type> (product may be coming but within the next 1-2 years)
c. modification of an existing specification (state which existing spec is being modified)
i. either a complete revision update or
ii. a minor version update
d. design spec (based on an existing base specification) with more refined design details (product coming in 12-15months)
e. a detailed specification for a <hardware product type> for a very specific product being available in 3-6months of approval of this Spec
f. If none of the above, please contact OCP Staff for better direction.
Q2. How do I know if what I am contributing will be accepted by OCP?
a. Before contributing any specifications, please contact either OCP Staff (Archna Haylock or Michael Schill) or the Project Lead for the Project that best represents your contribution. For example, if you are contributing a Server Specification, please contact one of the Server Project Leads. You can see all the Projects here. (https://www.opencompute.org/projects)
b. They will help you with your contribution and help you navigate the process. Q3. What is the contribution process for my hardware spec?
a. Follow the flow for your spec type here. (https://docs.google.com/presentation/d/1PlXGLhCdgVEGWQ0hLYdAQEH5qCScwYij/edit)
b. This flow is subject to change so please check with the OCP Staff for more information or any questions.
Q4.What if my spec is not developed yet and I want to collaborate with other companies?
a. Please contact either OCP Staff (Archna Haylock or Michael Schill) or the Project Lead for the Project that best represents your contribution.
b. They will help you find other collaborators and help you with the contribution process for a multi-party contribution.
Q5.I have a question on the Contribution License Agreement.
a. Please contact OCP Staff and we can help you with questions.
Q6.Do I need to have a product in order to contribute a spec?
a. Please see Q1. Some types of specs do not require an immediate product. Some do. Please work with the OCP Staff on better direction on your specification type.

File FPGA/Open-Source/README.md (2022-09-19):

# FPGA Open Source Time Card structure

The FPGA Open Source TimeCard repository is structured as shown below

```bash
    │
    │   Readme.md
    │   
    ├───Implementation
    │   └───Xilinx
    │       └───TimeCard
    │           │   CoreListFile.txt
    │           │   DefaultConfigFile.txt
    │           │   CreateBinaries.tcl
    │           │   CreateBinariesAll.tcl
    │           │   CreateBinariesGolden.tcl
    │           │   CreateProject.tcl
    │           │   Readme.md
    │           │   
    │           ├───Additional Files
    │           │       
    │           ├───Bd
    │           │       
    │           ├───Binaries
    │           │
    │           ├───Constraints
    │           │
    │           ├───(TimeCard)
    │           │
    │           └───Top
    │                   
    ├───Ips
    │   │   TC_ClockAdjustment.xml
    │   │   TC_ClockAdjustment_rtl.xml
    │   │   TC_Servo.xml
    │   │   TC_Servo_rtl.xml
    │   │   TC_Time.xml
    │   │   TC_Time_rtl.xml
    │   │   
    │   ├───AdjustableClock
    │   │               
    │   ├───ClockDetector
    │   │               
    │   ├───ConfMaster
    │   │               
    │   ├───CoreList
    │   │               
    │   ├───DummyAxiSlave
    │   │               
    │   ├───FPGA Version
    │   │               
    │   ├───FrequencyCounter
    │   │               
    │   ├───MsiIrq
    │   │               
    │   ├───PpsGenerator
    │   │               
    │   ├───PpsSlave
    │   │               
    │   ├───PpsSourceSelector
    │   │               
    │   ├───SignalGenerator
    │   │               
    │   ├───SignalTimestamper
    │   │               
    │   ├───SmaSelector
    │   │               
    │   └───TodSlave
    │                   
    ├───Modules
    │   └───BufgMux
    │           
    └───Package
```

## Implementation
The FPGA implementations of the TimeCard are separated depending on the vendor/version. Currently, only a Xilinx implementation of the Open Source Timecard is available. 
The top folder of the project is under the name [*/[YOUR_PATH]/Implementation/Xilinx/TimeCard*](implementation/Xilinx/TimeCard/).

Under this folder there are the vendor and implementation dependent files:
- File **Readme.md** describes the design of the implementation and instructs how to create/implement the project and generate the binaries.
- File **DefaultConfigFile.txt** is the default configuration of the FPGA cores
- File **CoreListFile.txt** lists the configurable cores of the FPGA
- 4 **.tcl** files for creating/implementing the project and generating the binaries
- Folder **Additional Files** contains files (e.g. images) for the documentation of the project 
- Folder **Bd** contains the **.tcl** files for the project's Block Design creation (called by the CreateProject.tcl)
- Folder **Binaries** contains the generated binaries of the project after each implementation run 
- Folder **Constraints** contains all the constraint files of the project 
- Folder **TimeCard**  contains the project files generated during creation, synthesis and implementation of the project. 
The folder is created when the **CreateProject.tcl** is executed. The folder is not added to the repository and it shall be deleted, in order to call successfully the CreateProject.tcl
- Folder **Top** contains the top .vhd file of the project

## Ips
The [**Ips** folder](Ips) contains all the user-defined open source IP cores. Each folder of an IP core has similar structure 
- File **Readme.md** describes the FPGA core (design overview, register set description, etc.)     
- File(s) **.vhd** of the core
- Folder **Xilinx** contains the vendor specific IPI files to integrate the cores in the Vivado tool
- Folder **Additional Files** contains files (e.g. images) for the documentation of the core

Additionally, the **Ips** folder contains .xml files of the custom type definitions for the IP core interfaces.

## Modules
The [**Modules**  folder](Modules) contains all the user-defined open source .vhd files which are not instantiated as IPI.
## Package
The [**Package** folder ](Package) contains the library file of the project which contains different constants and common used procedures.

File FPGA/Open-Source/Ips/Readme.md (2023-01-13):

# FPGA Open Source Time Card IP Cores

The folder contains the files for the custom IP cores which are used at the Time Card project. 

```bash
   │
   │   Readme.md
   │
   │   TC_ClockAdjustment.xml
   │   TC_ClockAdjustment_rtl.xml
   │   TC_Servo.xml
   │   TC_Servo_rtl.xml
   │   TC_Time.xml
   │   TC_Time_rtl.xml
   │   
   ├───AdjustableClock
   │               
   ├───ClockDetector
   │               
   ├───CommunicationSelecor
   │               
   ├───ConfMaster
   │               
   ├───CoreList
   │               
   ├───DummyAxiSlave
   │               
   ├───FPGA Version
   │               
   ├───FrequencyCounter
   │               
   ├───MsiIrq
   │               
   ├───PpsGenerator
   │               
   ├───PpsSlave
   │               
   ├───PpsSourceSelector
   │               
   ├───SignalGenerator
   │               
   ├───SignalTimestamper
   │               
   ├───SmaSelector
   │               
   └───TodSlave
```

## Readme.md
The current file.

## User-defined interfaces
The .xml files in the folder define user-defined interfaces which are used by the IP cores of the project. 
Currently, there are 3 user-defined interfaces.

| Interface Name | Interface Description |
|---|---|
| [Time](TC_Time_rtl.xml) | It contains the actual time counter in seconds and nanoseconds and also a validity bit and a flag that notifies a hard time-set. |
| [ClockAdjustment](TC_ClockAdjustment_rtl.xml) | It contains the time adjustment in terms of seconds, nanoseconds, direction, interval over which the adjustment should be applied and validity |
| [Servo](TC_Servo_rtl.xml) | It contains the coefficients of a PI servo loop |

## IP cores
Each user-defined open source IP cores is defined in a seperate folder. Each IP folder has similar structure 
- The **Readme.md** file which describes the FPGA core (context overview, register set description, design description, etc.)     
- The **.vhd** files of the core
- The **Xilinx** folder contains the vendor specific IPI files to integrate the cores in the Vivado tool
- The **Additional Files** folder contains files (e.g. images) for the documentation of the core and -for some cores- file templates

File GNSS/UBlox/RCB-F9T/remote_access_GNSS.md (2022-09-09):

# Accessing the GNSS TTY port remotely

Time Card driver (ptp_ocp) exposes direct access to the GNSS module using the TTY port in the Linux system. Unfortunately, U-Blox only provides its u-center software for Windows. As a result, there is no direct way to monitor or reconfigure the module "on-the-fly".

To enable u-center control, the ser2net package can be used to expose the TTY port over the ethernet. This guide will describe basic steps to enable that use case and enable rover configuration on the ZED-F9T module.

# Installing and configuring ser2net

Ser2net package is available in most of the distribution via standard package. For RH-based distribution, run

```bash
sudo dnf install ser2net
```

For debian-based distibutions

```bash
sudo apt-get ser2net
```

This will install the ser2net package and create necessary config files. 

## Finding GNSS TTY port

To find the port that's associated with the GNSS port run:

```bash
dmesg | grep ocp
```

> ```
> [    4.627215] ptp_ocp 0000:02:00.0: enabling device (0100 -> 0102)
> [    4.628143] ptp_ocp 0000:02:00.0: irq 16 out of range, skipping ts4
> [    4.631062] ptp_ocp 0000:02:00.0: Version 1.2.0, clock PPS, device ptp0
> [    4.631078] ptp_ocp 0000:02:00.0: Time: 1659170219.993081800, UNSYNCED
> [    4.631081] ptp_ocp 0000:02:00.0: version 8
> [    4.631083] ptp_ocp 0000:02:00.0: regular image, version 8
> [    4.631084] ptp_ocp 0000:02:00.0:  GNSS: /dev/ttyS5  @ 115200
> [    4.631087] ptp_ocp 0000:02:00.0: GNSS2: /dev/ttyS6  @ 115200
> [    4.631089] ptp_ocp 0000:02:00.0:   MAC: /dev/ttyS7  @  57600
> [    4.631094] ptp_ocp 0000:02:00.0:  NMEA: /dev/ttyS8  @     -1
> ```

Alternatively,

```bash
ls -ls /sys/class/timecard/ocp*/ttyGNSS
```

> ```
> 0 lrwxrwxrwx. 1 root root 0 Jul 30 11:07 /sys/class/timecard/ocp0/ttyGNSS -> ../../tty/ttyS5
> ```

In both cases `/dev/ttyS5` is our device. Now we can expose it over the ethernet.

## Configuring  ser2net

Now, we need to edit the config file and expose Time Card's GNSS serial port. The default config file for ser2net tries to expose a lot of ports by default, so we we backup it and create the new one with just the port we try to expose.

```bash
sudo mv /etc/ser2net.conf /etc/ser2net.conf.bak
sudo sh -c "echo -e 2006:raw:5:/dev/ttyS5:115200 > /etc/ser2net.conf"
```

Now we can run the ser2net

```bash
ser2net
```

And open port on the firewall

```
sudo firewall-cmd --add-port=2006/tcp
```

Now we can connect to the GNSS module directly using the u-center network connection feature.

## U-center network connection

To access the GNSS remotely use the built-in Network connection feature in the u-center, select New... option and enter the remote platform address: `tcp://192.168.1.20:2006`



The u-center should connect to the remote module and enable you to configure it, read module status and use the RTK rover feature.

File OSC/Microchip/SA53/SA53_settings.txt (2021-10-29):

Minimum necessary instructions
Default baudrate is 57600

\{set,Disciplining,1}
\{set,PpsWidth,80000000}
\{set,TauPps0,10000}
\{set,PpsOffset,-30}
\{set,DisciplineThresholdPps0,20}
\{store}

A handful of other commands

\{get,PpsOffset}

\{set,PpsOffset,0}

\{get,DisciplineLocked}

\{set,PpsWidth,80000000}

\{get,Locked}

\{get,Disciplining}

\{set,Disciplining,1}

\{get,Disciplining}

\{get,Phase}

\{set,TauPps0,10000}

\{set,TauPps0,1000}

\{set,TauPps0,500}

\{set,TauPps0,100}

\{set,TauPps0,10}

\{get,TauPps0}

\{get,DigitalTuning}

\{get,JamSyncing}

\{get,PhaseLimit}

\{set,PhaseLimit,1000}

\{get,DisciplineThresholdPps0}

\{get,PpsInDetected}

\{get,LockProgress}

\{get,PpsSource}

\{get,LastCorrection}

\{get,DisciplineLocked}

\{get,Locked}

\{set,PpsOffset,-10}

\{store}

For more info refer to the SA53 datasheet
http://ww1.microchip.com/downloads/en/DeviceDoc/Miniature-Atomic-Clock-MAC-SA5X-Users-Guide-DS50002938A.pdf

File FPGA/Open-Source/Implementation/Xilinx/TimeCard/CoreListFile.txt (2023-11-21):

// Core Type Nr:
// Invalid/End                          0x0
// TC Core List Core Type               0x1
// TC Adjustable Clock Core Type        0x2
// TC Signal Generator Core Type        0x3
// TC Signal Timestamper Core Type      0x4
// TC PPS Generator Core Type           0x5
// TC Frequency Counter                 0x6
// TC Clock Detector Core Type          0x7
// TC SMA Selector Core Type            0x8
// TC PPS Source Selector Core Type     0x9
// TC FPGA Version Core Type            0xA
// TC PPS Slave Core Type               0xB
// TC ToD Slave Core Type               0xC
// TC Dummy Axi Slave Core Type         0xD
// Xilinx AXI PCIe Core Type            0x10000
// Xilinx AXI GPIO Core Type            0x10001
// Xilinx AXI IIC Core Type             0x10002
// Xilinx AXI UART Core Type            0x10003
// Xilinx AXI HWICAP Core Type          0x10004
// Xilinx AXI QUAD SPI FLASH Core Type  0x10005

// Core Inst Nr range: [0 - (N-1)], where N is the number of instantiations of the core in the design

// Version Nr has the format 0xMMmmBBBB, where MM is the Major version (8 bits), mm is the Minor version (8 bits), BBBB is the Built version (16 bits)

// AddressRangeLow is the offset address of the core's AXI slave, 0xFFFFFFFF when the core does not have AXI slave

// AddressRangeHigh is the highest address of the core's AXI slave

// Interrupt Nr range: [0x0-0x1F], 0xFFFFFFFF when the core does not have Interrupt

// Interrupt Sensitivity: bit0: 0=Edge/1=Level bit1: 0=ActiveLow/1=ActiveHigh

// Magic Word: Core in ascii chars (maximum "TextWidth_Con" number of ascii chars)

// CoreTypeNr CoreInstNr VersionNr AddressRangeLow AddressRangeHigh InterruptNr Sensitivity MagicWord
00000001 00000000 00010000 01300000 0130FFFF FFFFFFFF FFFFFFFF TC Core List
00000002 00000000 00010000 01000000 0100FFFF FFFFFFFF FFFFFFFF TC Adj Clock
00000003 00000000 00010000 010D0000 010DFFFF 0000000B 00000002 TC Sig Generator 1
00000003 00000001 00010000 010E0000 010EFFFF 0000000C 00000002 TC Sig Generator 2
00000003 00000002 00010000 010F0000 010FFFFF 0000000D 00000002 TC Sig Generator 3
00000003 00000003 00010000 01100000 0110FFFF 0000000E 00000002 TC Sig Generator 4
00000004 00000000 00010000 01010000 0101FFFF 00000001 00000002 TC Sig Timestamper GNSS PPS
00000004 00000001 00010000 01020000 0102FFFF 00000002 00000002 TC Sig Timestamper 1
00000004 00000002 00010000 01060000 0106FFFF 00000006 00000002 TC Sig Timestamper 2
00000004 00000003 00010000 010C0000 010CFFFF 00000000 00000002 TC Sig Timestamper FPGA PPS
00000004 00000004 00010000 01110000 0111FFFF 0000000F 00000002 TC Sig Timestamper 3
00000004 00000005 00010000 01120000 0112FFFF 00000010 00000002 TC Sig Timestamper 4
00000005 00000000 00010000 01030000 0103FFFF FFFFFFFF FFFFFFFF TC PPS Generator
00000006 00000000 00010000 01200000 0120FFFF FFFFFFFF FFFFFFFF TC Freq Counter 1
00000006 00000001 00010000 01210000 0121FFFF FFFFFFFF FFFFFFFF TC Freq Counter 2
00000006 00000002 00010000 01220000 0122FFFF FFFFFFFF FFFFFFFF TC Freq Counter 3
00000006 00000003 00010000 01230000 0123FFFF FFFFFFFF FFFFFFFF TC Freq Counter 4
00000007 00000000 00010000 00130000 00130FFF FFFFFFFF FFFFFFFF TC Clock Detector
00000008 00000000 00010000 00140000 00143FFF FFFFFFFF FFFFFFFF TC SMA Selector Inst0 Slave1
00000008 00000000 00010000 00220000 00223FFF FFFFFFFF FFFFFFFF TC SMA Selector Inst0 Slave2
00000009 00000000 00010000 FFFFFFFF FFFFFFFF FFFFFFFF FFFFFFFF TC PPS Source Selector 0
00000009 00000001 00010000 FFFFFFFF FFFFFFFF FFFFFFFF FFFFFFFF TC PPS Source Selector 1
0000000A 00000000 00010000 00020000 00020FFF FFFFFFFF FFFFFFFF TC FPGA Version
0000000B 00000000 00010000 01040000 0104FFFF FFFFFFFF FFFFFFFF TC PPS Slave
0000000C 00000000 00020003 01050000 0105FFFF FFFFFFFF FFFFFFFF TC ToD Slave
0000000D 00000000 00010000 01070000 0107FFFF FFFFFFFF FFFFFFFF TC Dummy Axi Slave 0 (placeholder)
0000000D 00000001 00010000 01080000 0108FFFF FFFFFFFF FFFFFFFF TC Dummy Axi Slave 1 (placeholder)
0000000D 00000002 00010000 01090000 0109FFFF FFFFFFFF FFFFFFFF TC Dummy Axi Slave 2 (placeholder)
0000000D 00000003 00010000 010A0000 010AFFFF FFFFFFFF FFFFFFFF TC Dummy Axi Slave 3 (placeholder)
0000000D 00000004 00010000 010B0000 010BFFFF FFFFFFFF FFFFFFFF TC Dummy Axi Slave 4 (placeholder)
00010000 00000000 02090000 00010000 00010FFF FFFFFFFF FFFFFFFF Xilinx AXI PCIe
00010001 00000000 02000000 00100000 00100FFF FFFFFFFF FFFFFFFF Xilinx AXI GPIO ext
00010001 00000001 02000000 00110000 00110FFF FFFFFFFF FFFFFFFF Xilinx AXI GPIO GNSS MAC
00010002 00000000 02000000 00150000 0015FFFF 00000007 00000003 Xilinx AXI IIC
00010002 00000001 02000000 00200000 00200FFF 00000005 00000003 Xilinx AXI IIC CLOCK
00010003 00000000 02000000 00160000 0016FFFF 00000003 00000003 Xilinx AXI UART GNSS 1
00010003 00000001 02000000 00170000 0017FFFF 00000004 00000003 Xilinx AXI UART GNSS 2
00010003 00000002 02000000 00180000 0018FFFF 00000005 00000003 Xilinx AXI UART MAC
00010003 00000003 02000000 00190000 0019FFFF 0000000A 00000003 Xilinx AXI UART reserved
00010003 00000004 02000000 001A0000 001AFFFF 00000013 00000003 Xilinx AXI UART ext
00010004 00000000 03000000 00300000 0030FFFF 00000008 00000003 Xilinx AXI HWICAP
00010005 00000000 03020000 00310000 0031FFFF 00000009 00000002 Xilinx AXI Quad SPI flash

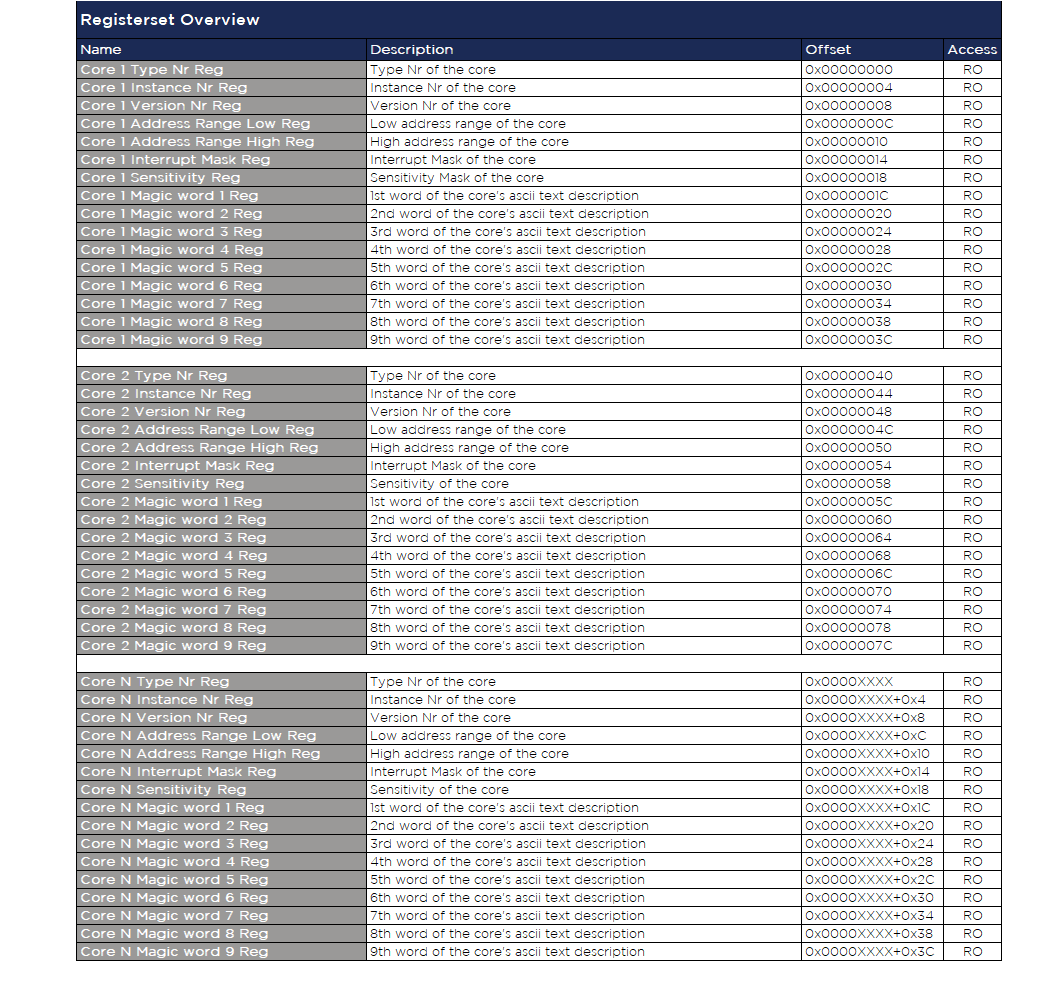
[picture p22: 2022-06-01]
FPGA/Open-Source/Ips/CoreList/Additional Files/CoreListRegsetOverview.png

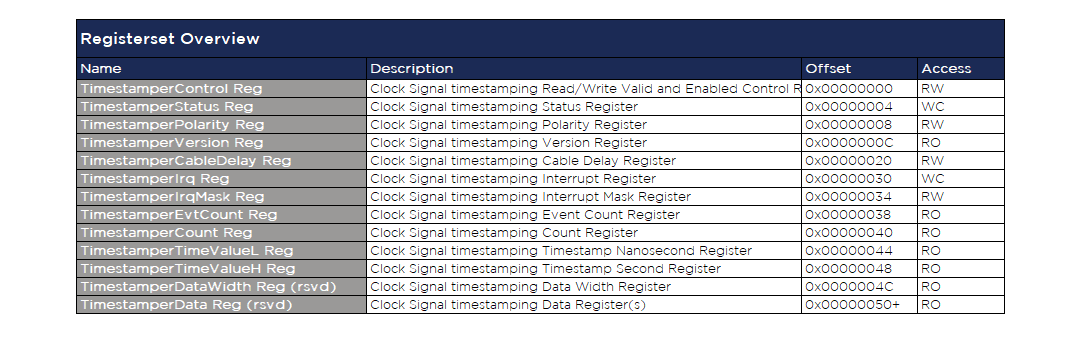
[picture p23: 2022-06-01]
FPGA/Open-Source/Ips/SignalTimestamper/Additional Files/RegsetOverview.png

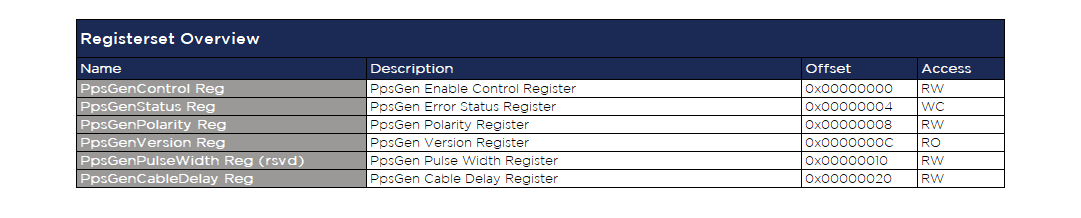
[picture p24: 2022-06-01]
FPGA/Open-Source/Ips/PpsGenerator/Additional Files/RegsetOverview.png

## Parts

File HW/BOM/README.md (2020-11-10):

# Bill of Materials for Time Card

The BOM is based on a digikey cart
https://www.digikey.com/short/zddqh4

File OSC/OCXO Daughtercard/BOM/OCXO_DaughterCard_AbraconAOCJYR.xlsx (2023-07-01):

Comment | Description | Designator | Footprint | LibRef | Quantity
0_1%_0402 |  | R11, R12, R17, R18, R19, R24, R25, R26, R30, R32 | RESC1005X40X25NL05T10 | CMP-1011-00001-2 | 10
0_5%_0603 | Chip Resistor, 0 Ohm, +/- 5%, 0.1 W, -55 to 155 degC, 0603 (1608 Metric), RoHS, Tape and Reel | R16, R23 | RESC1608X55X25ML10T15 | CMP-2100-03667-1 | 2
4.7K_1%_0402 | Chip Resistor, 4.7 KOhm, +/- 1%, 0.1 W, -55 to 155 degC, 0402 (1005 Metric), RoHS, Tape and Reel | R27, R28, R35, R36 | RESC1005X40X25LL05T05 | CMP-2002-01154-4 | 4
4871 | Round Standoff Threaded #2-56 Steel 0.063" (1.60mm) 1/16" | P13, P14, P15, P16 | Keystone_4871 | Keystone_4871 | 4
Abracon_AOCJYR-10.000MHZ-M5625LF | OSC, OCXO, 10.000MHZ, 25PPB STAB, LVCMOS, 3.3V, 9.7X7.5X4.3MM, SMT | Y3 | OSC004_600_970x750x410_AOCJYR | COR-CMP-00013-2 | 1
Kemet_T491B476K010AT | CAP TANT 47UF 10% 10V 1411 | C5, C15, C16 | CAPMP3528X210N_T520 | CAP-CMP-00042-1 | 3
LMS1587IS-3.3/NOPB | 3A Low Dropout Fast Response Regulators, 3-pin TO-263, Pb-Free | U1 | KTT0003B_L | CMP-0062-00189-5 | 1
Microchip_AT24MAC602-XHM-B | IC, EEPROM, AT24MAC602, 2K-BIT (256 X 8), 1MHZ, I2C, 1.7V - 5.5V, TSSOP-8 | U2 | TSSOP65P640X120-8N | MEM-CMP-00010-1 | 1
Mill-Max_8600-0-05-80-00-00-03-0 | CONN, PC PIN, PRESS-FIT, 10.16MM LENGTH, TIN, TH | P1, P2, P3, P4, P5, P6, P7, P8, P11, P12 | TH001V_109DIA_000mt_8600-0 | CON-CMP-00162-1 | 10
Molex_539160208 | CONN, B2B/FPC, HEADER, 20-POS, 0.5MM PITCH, 4.0MM H, VERT, GOLD, SMT | P10 | SM020V_50_730x310x337_000mt_53916 | CON-CMP-00163-2 | 1
Murata_GRM21BR61A226ME51L | CAP, CER, X5R, 22UF, 20%, 10V, 0805, 1.40MM T | C2, C3, C4 | CAPC2013X140N | CAP-CMP-00519-3 | 3
Murata_GRM188D71A106MA73D | CAP, CER, X7T, 10UF, 20%, 10V, 0603, 1.00MM T | C8, C10, C18, C20 | CAPC1608X100N | CAP-CMP-00449-3 | 4
Murata_GRM188R61A106ME69D | CAP, CER, X5R, 10UF, 20%, 10V, 0603, 0.80MM T | C22 | CAPC1608X090N | CMP-CAP-00380-1 | 1
NXP_PCT2075TP,147 | SENSOR DIGITAL -55C-125C 8HWSON | U5 | SON50P300X200X80-HS-9N_EP160x160_IPC | SNS-CMP-00004-1 | 1
Panasonic_ERJ-2RKF1003X | RES, 100K OHM, 1%, 1/10W, 100PPM/C, 0402 | R4 | RESC1005X040N | RES-CMP-00289-3 | 1
Samsung Electro-Mechanics_CL05B104JO5NNNC | CAP, CER, X7R, 0.1UF, 5%, 16V, 0402, 0.55MM T | C1, C6, C7, C9, C11, C13, C17, C19, C21, C23 | CAPC1005X055N | CAP-CMP-00271-3, CMP-CAP-00082-2 | 10
Samtec_HTSW-102-07-T-S | CONN, PIN, HEADER, 2POS, 2.54MM PITCH, 8.38MM H, VERT, TIN, TH | P9 | TH002_254_508x254x838_000mt_HTSW | CON-CMP-00061-3 | 1
Stackpole Electronics, Inc._HCJ0402ZT0R00 | RES, 0.0 OHM, 1/8W, 6.5A, 0402 | R6, R7, R8 | RESC1005X045N | RES-CMP-00382-3 | 3
Stackpole Electronics, Inc._RMCF1210ZT0R00 | RES, 0.0 OHM, 3A, 1/2W, 1210 | R1 | RESC3225X070N | RES-CMP-00829-3 | 1
TDK_MPZ1608S601ATA00 | FERRITE BEAD, 600 OHM @100MHZ, 25%, 1A, 0.150 OHM DCR, 0603, 0.95MM T | FL1, FL2 | INDC1608X095N | FER-CMP-00057-5 | 2
TI_DS90LV027AQMA/NOPB | IC, DRIVER, DS90LV027AQ, DUAL, DIFF, LVDS, 600MBPS, SOIC-8 | U3 | SOP127P600X175_8N | INT-CMP-00018-2 | 1
TI_DS90LV028AQMA/NOPB | IC, RVCR, DS90LV028AQ-Q1, DUAL, DIFF, LVDS, 400MBPS, SOIC-8 | U4 | SOP127P600X175_8N | INT-CMP-00017-4 | 1
Wurth_9774040243R | STANDOFF, ROUND, M2X0.4 STEEL 4MM, 9774040243R | J1, J2 | TH000V_300DIAx400_001mt_9774040243R | CON-CMP-00164-1 | 2
Yageo_CC0402KRX7R7BB103 | CAP, CER, X7R, 0.01UF, 10%, 16V, 0402, 0.55MM T | C12, C14 | CAPC1005X055N | CAP-CMP-00257-3 | 2
Yageo_RC0201FR-0710KL | RES, 10K OHM, 1%, 1/20W, 200PPM/C, 0201 | R34 | RESC0603X026N | CMP-RES-00602-1 | 1
Yageo_RC0201JR-070RL | RES, 0.0 OHM, 0.5A, 1/20W, 0201 | R33 | RESC0603X026N | CMP-RES-00843-1 | 1
Yageo_RC0402FR-07100RL | RES SMD 100 OHM 1% 1/16W 0402 | R5 | RESC1005X040N | RES-CMP-00538-3 | 1

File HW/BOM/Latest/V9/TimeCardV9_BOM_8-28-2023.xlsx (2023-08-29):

Line # | DNP | Name | Description | Designator | Revision ID | Revision State | Revision Status | Quantity | Manufacturer 1 | Manufacturer Part Number 1 | Manufacturer Lifecycle 1 | Supplier 1 | Supplier Part Number 1 | Supplier Unit Price 1 | Supplier Subtotal 1
 |  | 39-30-0040 | CONN HEADER R/A 4POS 4.2MM | J38 | CMP-2000-05600-2 | New From Design | Up to date | 1 | Molex | 39-30-0040 | Volume Production | Newark | 26AC7279 | 0.906 | 0.906
 |  | 219-2LPST | Surface Mount DIP Switch Auto Placeable, -55 to 85 degC, 4-Pin SMD, RoHS, Tube | SW2 | CMP-2000-05532-1 | Released | Up to date | 1 | CTS | 219-2LPST | Volume Production | Future Electronics | 2400042 | 0.395 | 0.395
 |  | 0332-0-43-80-18-27-10-0 | Solder socket for pin headers | SKT1, SKT2, SKT3, SKT4, SKT5, SKT6, SKT7, SKT8, SKT9, SKT10 |  | Not managed |  | 10
 |  | 901-143-6RFX | Coaxial connector, 50 Ohm, -65 to 165 degC, 5-Pin THD, RoHS, Bulk | AN1, AN2, AN3, AN4 | CMP-2000-05705-1 | Released | Up to date | 4 | Adam Equipment | RF2-49B-T-00-50-G-HDW | Unknown | Arrow Electronics | RF2-49B-T-00-50-G-HDW | 2.5 | 9.99
 |  | 04023C104KAT2A | General Purpose Ceramic Capacitor, 0402, 100nF, 10%, X7R, 15%, 25V | C18, C26, C27, C28, C29, C33, C69, C70, C74, C83, C89, C92, C93, C94, C95, C96, C97, C98, C99, C100, C101, C102, C103, C104, C105, C106, C107, C108, C109, C110, C112, C113, C115 | CMP-2008-02519-2 | Released | Up to date | 33 | Kyocera AVX | 04023C104KAT2A | Volume Production | Newark | 95W1317 | 0.007 | 0.231
 |  | 04023D104KAT2A |  | C19, C21, C66, C67, C84 | CMP-1034-02072-2 | Released | Up to date | 5 | Kyocera AVX | 04023C104KAT2A | Volume Production | Newark | 95W1317 | 0.007 | 0.035
 |  | 47589-0001 | Right Angle Female Type AB Micro USB Connector, 30 V, 1.8 A, -30 to 85 degC, RoHS, Tape and Reel | J43 | CMP-2000-05610-1 | Released | Up to date | 1 | Molex | 47589-0001 | Volume Production | Newark | 40P3749 | 0.323 | 0.323
 |  | 155124M173200 | LED (Multiple) | D13, D14, D15, D16, D17, D18 |  | Not managed |  | 6 | Wurth Electronics | 155124M173200 | Unknown | Digi-Key | 732-11414-1-ND | 0.53 | 3.18
 |  | 1571983-4 | SWITCH SLIDE DIP SPST 25MA 24V | SW1 | CMP-03400-000014-1 | New From Design | Up to date | 1 | TE Connectivity | 1571983-4 | Volume Production | Future Electronics | 9787847 | 1.15 | 1.15
 |  | 1909763-1 | Ultra Miniature Coaxial Connector Jack, 60 V, 50 Ohm, -40 to 90 degC, RoHS, Tape and Reel | J1, J2, J3, J4 | CMP-2000-07505-1 | Released | Out of date | 4 | TE Connectivity AMP | 1909763-1 | Volume Production | Newark | 24AC1644 | 0.256 | 1.02
 |  | 2199119-3 | CONN M.2 FEMALE 67POS 0.020 GOLD | J44, J45 | CMP-03365-000004-1 | New From Design | Up to date | 2 | TE Connectivity | 2199119-3 | Volume Production | Newark | 28AC8045 | 1.03 | 2.06
 |  | 8240136 | TVS Diode WE-TVS-HS, VRWM=3.3V | D1, D2 | CMP-1486-00002-1 | Released | Out of date | 2 | Wurth Electronics | 8240136 | Volume Production | Digi-Key | 732-4472-1-ND | 1.28 | 2.56
 |  | 61300411121 | THT Vertical Pin Header WR-PHD, Pitch 2.54 mm, Single Row, 4 pins | P5 | CMP-1502-01064-1 | Released | Out of date | 1 | Wurth Electronics | 61300411121 | Volume Production | Digi-Key | 732-5317-ND | 0.19 | 0.19
 |  | ABS07-32.768KHZ-T | Crystal 32.768kHz ±20ppm (Tol) 12.5pF FUND 70kΩ 2-Pin CSMD T/R | Y1 | CMP-0447-00001-4 | Released | Up to date | 1 | Abracon | ABS07-32.768KHZ-T | Volume Production | Mouser | 815-ABS07-32.768KHZT | 0.62 | 0.62
 |  | AT24MAC402-STUM-T | IC EEPROM 2K I2C 1MHZ SOT23-5 | U7 | CMP-06313-000011-1 | New From Design | Up to date | 1 | Microchip | AT24MAC402-STUM-T | Volume Production
 |  | BAT54SW | DIO, SCHOTTKY, BAT54S, DUAL SERIES, 30V, 200MA, SC-70 | D5, D6, D7, D8 |  | Not managed |  | 4 | Diodes | BAT54SWQ-7-F | Volume Production | Digi-Key | BAT54SWQ-7-FDICT-ND | 0.33 | 1.32
 |  | BLM18KG601SN1D | Chip Ferrite Bead, 0603, 600Ω @ 100MHz, 0.15Ω, 25%, 1.3A | FB1 | CMP-0686-00581-3 | Released | Up to date | 1 | Murata | BLM18KG601SN1D | Volume Production | Arrow Electronics | BLM18KG601SN1D | 0.0809 | 0.0809
 |  | BME280 | SENSOR PRESSURE HUMIDITY TEMP | U14 | CMP-2000-05073-3 | New From Design | Up to date | 1 | Bosch | BME280 | Volume Production | Future Electronics | 2053946 | 4.57 | 4.57
 |  | BNO055 | IMU ACCEL/GYRO/MAG I2C 28LGA | U13 | CMP-2000-05075-4 | New From Design | Up to date | 1 | Bosch | BNO055 | Volume Production
 |  | C0603C105K3PACTU | CAP CER 1UF 25V X5R 0603 | C38 | CMP-2006-02216-3 | Released | Up to date | 1 | KEMET | C0603C105K3PACTU | Volume Production | Newark | 93K5996 | 0.004 | 0.004
 |  | C0603X104K5RACAUTO |  | C2, C23, C24, C25, C30, C31, C36, C37, C40, C43, C54, C57, C59, C61, C63, C64 | CMP-2006-00003-1 | Released | Out of date | 16 | KEMET | C0603X104K5RACAUTO | Volume Production | Newark | 91Y8329 | 0.038 | 0.608
 |  | C1005X5R1C225K050BC | Multilayer Ceramic Capacitors 2.2μF ±10% 16V X5R SMD 0402 | C3, C5, C7, C9, C16, C81 | CMP-2000-05998-2 | Released | Up to date | 6 | TDK | C1005X5R1C225K050BC | Volume Production | Mouser | 810-C1005X5R1C225K | 0.119 | 1.19
 |  | C3216X5R1C476M160AB | Multilayer Ceramic Capacitors 47uF ±20% 16V X5R SMD 1206 | C13, C78 | CMP-2000-07442-2 | Released | Up to date | 2 | TDK | C3216X5R1C476M160AB | Volume Production | Newark | 12T1951 | 0.11 | 0.22
 |  | CAP_0402_0.1UF_50V | CAP, CER, 0.1UF, 50V, 10%, X7R, AEC-Q200, 0402 | C44, C45, C46, C47, C48, C49, C50, C51, C52, C53 |  | Not managed |  | 10 |  |  |  | Digi-Key | 445-6899-1-ND
 |  | CAP_0805_10UF_25V | CAP, CER, 10.UF, 25V, 10%, X5R, 0805 | C1, C62 |  | Not managed |  | 2 | Taiyo | TMK212BBJ106KG-T | Unknown | MOUSER | 963-TMK212BBJ106KG-T
 |  | CC0402JRNPO9BN220 | Chip Capacitor, 22 pF, +/- 5%, 50 V, -55 to 125 degC, 0402 (1005 Metric), RoHS, Tape and Reel | C39, C68 | CMP-2100-03590-1 | Released | Up to date | 2 | Yageo | CC0402JRNPO9BN220 | Volume Production | Newark | 69C9585 | 0.011 | 0.11
 |  | CC0402KRX7R9BB103 | CAP CER 10000PF 50V X7R 0402 | C86, C91 | CMP-2100-03592-2 | New From Design | Up to date | 2 | Yageo | CC0402KRX7R9BB103 | Volume Production | Newark | 69AH7183 | 0.003 | 0.006
 |  | CL05A475MO5NUNC | Cap Ceramic 4.7uF 16V X5R ±20% SMD 0402 +85°C Paper T/R | C90 | CMP-13271-001468-1 | New From Design | Up to date | 1 | Samsung | CL05A475MO5NUNC | Volume Production | Mouser | 187-CL05A475MO5NUNC | 0.41 | 0.41
 |  | CR0402-FX-1002GLF |  | R59, R60, R184, R185 | CMP-2002-04694-1 | Released | Up to date | 4 | Bourns | CR0402-FX-1002GLF | Volume Production | Arrow Electronics | CR0402-FX-1002GLF | 0.0044 | 0.044
 |  | CR0402-FX-4701GLF |  | R5, R14, R15, R16, R17, R29, R30, R31, R32, R70, R113, R114, R115, R116, R117, R118, R119, R120, R123, R124, R132, R133, R134, R135, R136, R137 | CMP-2002-05217-1 | Released | Up to date | 26 | Bourns | CR0402-FX-4701GLF | Volume Production | Newark | 34AK1324 | 0.001 | 0.026
 |  | CRCW040227R0FKED |  | R13, R42, R43, R76, R81, R84, R85, R86, R87, R90, R91, R92, R93, R94, R95, R111, R121, R126, R127, R128 | CMP-2002-08434-1 | Released | Up to date | 20 | Vishay | CRCW040227R0FKED | Volume Production | Newark | 72M6769 | 0.005 | 0.1
 |  | CRCW080533R0FKEA | RES, 33 OHM, 1%, 1/8W, TF, 0805 | R18, R19, R20, R21 |  | Not managed |  | 4 | Vishay | CRCW080533R0FKEA | Volume Production | Digi-Key | 541-33.0CCT-ND | 0.1 | 0.4
 |  | CRCW0402200RFKTD |  | R112, R122, R125, R178, R179 | CMP-2002-08352-1 | Released | Up to date | 5 | Vishay Dale | CRCW0402200RFKTD | Volume Production | Digi-Key | 541-CRCW0402200RFKTDCT-ND | 0.13 | 0.65
 |  | CRCW0603110RFKEA |  | R12 | CMP-2000-03854-1 | Released | Up to date | 1 | Vishay | CRCW0603110RFKEA | Volume Production | Newark | 52K8095 | 0.005 | 0.005
 |  | CRCW12060000Z0EAHP |  | R45 | CMP-2003-04873-1 | Released | Up to date | 1 | Vishay Dale | CRCW12060000Z0EAHP | Volume Production | Mouser | 71-CRCW12060000Z0EAH | 0.26 | 0.26
 |  | DS90LV027AQMA | Automotive LVDS Dual Differential Driver, 8-pin Narrow SOIC | U3 | CMP-0058-01000-2 | Released | Up to date | 1 | TI National Semiconductor | DS90LV027AQMA | Unknown
 |  | DS90LV028AQMA | Automotive LVDS Dual Differential Line Receiver, 8-pin Narrow SOIC | U4 | CMP-0058-01010-2 | Released | Up to date | 1 | TI National Semiconductor | DS90LV028AQMA | Volume Production
 |  | EMK105BJ105KV-F | None | C17, C32, C82, C111, C114 | CMP-14477-000104-2 | New From Design | Up to date | 5 | Taiyo Yuden | EMK105BJ105KV-F | Volume Production | Newark | 84R9109 | 0.006 | 0.03
 |  | EMK105BJ105MV-F | None | C65 | CMP-14477-003537-2 | New From Design | Up to date | 1 | Taiyo Yuden | EMK105BJ105MV-F | Volume Production | Newark | 02AH5329 | 0.006 | 0.006
 |  | EMK107BBJ106MA-T | Multilayer Ceramic Capacitor 10uF 16V X5R 20% SMD 0603 T/R | C6, C8, C15, C20, C22, C80, C85 | CMP-2000-06226-4 | Released | Up to date | 7 | Taiyo Yuden | EMK107BBJ106MA-T | Volume Production | Mouser | 963-EMK107BBJ106MA-T | 0.151 | 1.51
 |  | ERA-2AED122X |  | R26 | CMP-2002-05839-1 | Released | Up to date | 1 | Panasonic | ERA-2AED122X | Volume Production | Arrow Electronics | ERA-2AED122X | 0.0889 | 0.0889
 |  | ERA-2AED222X |  | R61 | CMP-2002-05848-1 | Released | Up to date | 1 | Panasonic | ERA-2AED222X | Volume Production | Digi-Key | P2.2KDECT-ND | 0.19 | 0.19
 |  | ERJ2GE0R00X | Chip Resistor, 0 Ohm, 0.1 W, -55 to 155 degC, 0402 (1005 Metric), RoHS, Tape and Reel | R3, R4, R54, R62, R64, R65, R66, R69, R79, R80, R138, R139 | CMP-2000-07451-1 | Released | Up to date | 12 | Panasonic | ERJ-2GE0R00X | Volume Production | Newark | 63W0591 | 0.005 | 0.06
 |  | ERJ-2GE0R00X | RES, 0. OHM, 1%, 1/16W, TF, AEC-Q200, 0402 | R23, R24 |  | Not managed |  | 2 | Panasonic | ERJ-2GE0R00X | Volume Production | Digi-Key | P0.0JCT-ND | 0.1 | 0.2
 |  | ERJ-2GEJ103X |  | R49, R180, R181, R182 | CMP-2002-00433-1 | Released | Up to date | 4 | Panasonic | ERJ-2GEJ103X | Volume Production | Newark | 12AC0920 | 0.004 | 0.016
 |  | ERJ-2RKF1502X | RES SMD 15K OHM 1% 1/10W 0402 | R83 | CMP-2002-00694-4 | New From Design | Up to date | 1 | Panasonic | ERJ-2RKF1502X | Volume Production | Newark | 64R5259 | 0.007 | 0.007
 |  | ERJ-2RKF2000X | RES SMD 200 OHM 1% 1/10W 0402 | R1, R77 | CMP-2002-00757-2 | Released | Up to date | 2 | Panasonic | ERJ-2RKF2000X | Volume Production | Newark | 73T6485 | 0.004 | 0.008
 |  | ERJ-2RKF4701X | Chip Resistor, 4.7 KOhm, +/- 1%, 0.1 W, -55 to 155 degC, 0402 (1005 Metric), RoHS, Tape and Reel | R50, R51, R52, R53, R55, R57, R58, R108, R109 | CMP-2002-01154-4 | Released | Up to date | 9 | Panasonic | ERJ-2RKF4701X | Volume Production | Newark | 85Y8345 | 0.004 | 0.036
 |  | ERJ-3EKF2000V |  | R35, R36, R38, R39 | CMP-2000-00316-1 | Released | Out of date | 4 | Panasonic | ERJ-3EKF2000V | Volume Production | Newark | 63W0785 | 0.006 | 0.06
 |  | ERJ-3EKF4701V | Precision Thick Film Chip Resistor, 4.7 KOhm, +/- 1%, -55 to 155 degC, 0603 (1608 Metric), RoHS, Tape and Reel | R41 | CMP-1012-00586-3 | Released | Up to date | 1 | Yageo | RC0603FR-074K7L | Volume Production | Newark | 75X0151 | 0.003 | 0.003
 |  | ERJ-3EKF4701V | RES, 4.7K, 1%, 1/10W, TF, 0603 | R22 |  | Not managed |  | 1 | Panasonic | ERJ-3EKF4701V | Volume Production | Digi-Key | P4.70KHCT-ND | 0.1 | 0.1
 | DNP | EXT GPIO | Header, 6-Pin, Dual row | P3 |  | Not managed |  | 1
 |  | FT234XD-R | IC USB SERIAL BASIC UART 12DFN | U20 | CMP-0248-00027-3 | New From Design | Up to date | 1 | FTDI | FT234XD-R | Volume Production | Arrow Electronics | FT234XD-R | 2.21 | 2.21
 |  | FUSE_0603_5.00A | FUSE SLOW 5.00A 32V M 0603 | F1 |  | Not managed |  | 1 | Bourns | SF-0603S500-2 | Volume Production | Digi-Key | SF-0603S500-2CT-ND | 0.6 | 0.6
 |  | GNSS Header 16-pin |  | J6, J13 |  | Not managed |  | 2 | Samtec | SQW-108-01-F-D-VS | Volume Production | Digi-Key | SAM11878-ND | 3.61 | 7.22
 |  | GNSS Standoff |  | J5, J7, J8, J9, J10, J11, J12, J14 |  | Not managed |  | 8 | Keystone Electronics | 24393 | Volume Production | Digi-Key | 36-24393-ND | 0.72 | 5.76
 |  | GRM31CR71H475KA12L | Chip Multilayer Ceramic Capacitors for General Purpose, 1206, 4.7uF, X7R, 15%, 10%, 50V | C11, C12, C76, C77 | CMP-1037-04923-3 | New From Design | Up to date | 4 | Murata | GRM31CR71H475KA12L | Volume Production | Newark | 08AC2721 | 0.102 | 0.408
 |  | GRM1555C1H470JA01D |  | C87, C88 | CMP-2008-04368-1 | Released | Up to date | 2 | Murata | GRM1555C1H470JA01D | Not Recommended for New Design | Mouser | 81-GRM1555C1H470JA1D | 0.018 | 0.18
 |  | INA219BIDR | IC MONITOR PWR/CURR BIDIR 8-SOIC | U2, U17, U19 | CMP-0704-00005-3 | Released | Up to date | 3 | Texas Instruments | INA219BIDR | Volume Production | Arrow Electronics | INA219BIDR | 1.77 | 5.32
 |  | IS32FL3207 |  | U6 |  | Not managed |  | 1 | ISSI | IS32FL3207-QWLA3-TR | Unknown | Digi-Key | 2521-IS32FL3207-QWLA3-TRCT-ND | 2.09 | 2.09
 |  | LTST-C191KGKT | LED GREEN CLEAR SMD | D3, D4, D9, D10, D11, D12, D19, D20, D21, D22, D24 | CMP-2000-05198-2 | New From Design | Up to date | 11 | Vishay Lite-On | LTST-C191KGKT | Volume Production | Mouser | 859-LTST-C191KGKT | 0.142 | 1.56
 |  | M3 screw |  | J15, J16, J17, J18, J19, J20, J21, J22, J23, J24, J25, J26, J27, J28, J29, J30, J32, J33 |  | Not managed |  | 18 | APM Hexseal | RM3X6MM2701 | Volume Production | Digi-Key | 335-1156-ND | 0.46 | 8.28
 | DNP | MAC-SA5X | MOD, MAC, MAC-SA5X, ATOMIC CLOCK | U10 |  | Not managed |  | 1
 |  | MBRD10200CT-13 | No Description Available | CR1 |  | Not managed |  | 1
 |  | MC00625W0402120K |  | R6, R9, R129, R183 | CMP-2002-06039-1 | Released | Up to date | 4 | Multicomp | MC00625W0402120K | Volume Production
 |  | MUN12AD06-SM | No Description Available | U1, U24 |  | Not managed |  | 2
 |  | NC7WV125K8X | Integrated Circuit | U8, U11, U12, U16 |  | Not managed |  | 4 | ON Semiconductor / Fairchild | NC7WV125K8X | Volume Production | Farnell | 2824987 | 0.42948 | 1.72
 |  | NCP176AMX330TCG | IC REG LINEAR 3.3V 500MA 6XDFN | U25, U33 | CMP-07128-000022-1 | New From Design | Up to date | 2 | ON Semiconductor | NCP176AMX330TCG | Volume Production | Farnell | 2507589 | 0.36881 | 0.73763
 |  | PCA9546ARGVR | 4-Channel I2C and SMBus Multiplexer with Reset Functions, 2.3 to 5.5 V, -40 to 85 degC, 16-pin VQFN (RGV), Green (RoHS & no Sb/Br) | U27 | CMP-0314-00065-2 | Released | Up to date | 1 | Texas Instruments | PCA9546ARGVR | Volume Production | Arrow Electronics | PCA9546ARGVR | 1.1 | 1.1
 | DNP | PCIex4 | PCIE x4 Edge Connector,OrCAD Symbol,NC | P2 |  | Not managed |  | 1
 |  | PI3A412ZHE | No Description Available | U28, U29 |  | Not managed |  | 2
 |  | RC0402FR-0710KL |  | R78, R82, R88, R89, R140, R141, R186 | CMP-2002-07353-1 | Released | Up to date | 7 | Yageo | RC0402FR-0710KL | Volume Production
 |  | RC0402FR-0749R9L |  | R96, R97, R98, R99, R142, R143, R144, R145, R146, R147, R150, R152, R171, R175, R176, R177 | CMP-2002-07709-1 | Released | Up to date | 16 | Yageo | RC0402FR-0749R9L | Volume Production | Mouser | 603-RC0402FR-0749R9L | 0.009 | 0.144
 |  | RC0402FR-07147KL |  | R2 | CMP-2002-07394-1 | Released | Up to date | 1 | Yageo | RC0402FR-07147KL | Volume Production | Newark | 68AK6527 | 0.002 | 0.002
 |  | RC0603FR-074K7L | Chip Resistor, 4.7 KOhm, +/- 1%, 0.1 W, -55 to 155 degC, 0603 (1608 Metric), RoHS, Tape and Reel | R10, R11 | CMP-2000-06942-1 | Released | Up to date | 2 | Yageo | RC0603FR-074K7L | Volume Production | Newark | 75X0151 | 0.003 | 0.006
 |  | RC0603FR-0749R9L | General Purpose Chip Resistor, 49.9 Ohm, +/- 1%, -55 to 155 degC, 0603 (1608 Metric), RoHS, Tape and Reel | R25, R28, R33, R34 | CMP-1659-00036-1 | Released | Up to date | 4 | Yageo | RC0603FR-0749R9L | Volume Production | Mouser | 603-RC0603FR-0749R9L | 0.011 | 0.11
 | DNP | RCB-F9T | MOD, GPS | U9 |  | Not managed |  | 1 |  |  |  | Digi-Key | 672-RCB-F9T-ND
 | DNP | RCB-F9T-1 | MOD, GPS | U15 |  | Not managed |  | 1 |  |  |  | Digi-Key | 672-RCB-F9T-ND
 |  | RG1005R-220-D-T10 | Automotive Metal Thin Film Chip Resistor, 0402, 22Ω, 0.5%, 100ppm/°C, 0.0625W, 75V | R63 | CMP-2002-01415-2 | Released | Up to date | 1 | Susumu | RG1005R-220-D-T10 | Volume Production | Mouser | 754-RG1005R-220DT10 | 0.14 | 0.14
 |  | RMCF0603FT10K0 | Chip Resistor, 10 KOhm, +/- 1%, 0.1 W, -55 to 155 degC, 0603 (1608 Metric), RoHS, Tape and Reel | R37 | CMP-2000-06990-1 | Released | Out of date | 1 | Stackpole Electronics | RMCF0603FT10K0 | Volume Production | Digi-Key | RMCF0603FT10K0CT-ND | 0.1 | 0.1
 |  | RT0402DRD072KL |  | R68 | CMP-2002-02670-1 | Released | Up to date | 1 | Yageo | RT0402DRD072KL | Volume Production | Arrow Electronics | RT0402DRD072KL | 0.1579 | 0.1579
 |  | RT0402DRE0788K7L | RES SMD 88.7K OHM 0.5% 1/16W | R67 | CMP-2002-03021-2 | New From Design | Up to date | 1 | Yageo | RT0402DRE0788K7L | Volume Production | Digi-Key | 311-2330-1-ND | 0.17 | 0.17
 |  | RT0402DRE07160RL | RES SMD 160 OHM 0.5% 1/16W 0402 | R27 | CMP-03412-035461-1 | New From Design | Up to date | 1 | Yageo | RT0402DRE07160RL | Volume Production
 |  | SA53 Screw |  | J39, J40, J41, J42 |  | Not managed |  | 4 | B&F Fastener | PMSSS2560025PH | Volume Production | Digi-Key | H700-ND
 |  | SA53_Header |  | J31 |  | Not managed |  | 1 | Molex | 52991-0208 | Volume Production | Digi-Key | WM24007CT-ND | 1.46 | 1.46
 |  | Single FPGA Conn |  | J34, J35, J36, J37 |  | Not managed |  | 4 | Panasonic | AXK680347YG | Volume Production | Digi-Key | 255-3246-1-ND | 2.99 | 11.96
 |  | SMDJ12A | TVS DIODE 12V 19.9V DO214AB | D23 | CMP-08607-000111-1 | New From Design | Up to date | 1 | Littelfuse | SMDJ12A | Not Recommended for New Design | Arrow Electronics | SMDJ12A | 0.5402 | 0.5402
 |  | T495D107K016ATE125 | CAP TANT 100UF 10% 16V 2917 | C10, C14, C75, C79 | CMP-2000-07207-2 | Released | Up to date | 4 | KEMET | T495D107K016ATE125 | Volume Production | Newark | 95W0168 | 1.34 | 5.36
 |  | T521X476M035ATE030 | CAP TANT POLY 47UF 35V 2917 | C72, C73 | CMP-03016-000019-1 | New From Design | Up to date | 2 | KEMET | T521X476M035ATE030 | Volume Production | Avnet | 96Y7534 | 3.62 | 7.24
 |  | TAJE477K010RNJ | 470uF 10V ±10% 500mΩ 2917 SMD Tantalum Capacitor | C4, C71 | CMP-04424-000243-1 | New From Design | Up to date | 2 | Kyocera AVX | TAJE477K010RNJ | Volume Production | Arrow Electronics | TAJE477K010RNJ | 1.29 | 2.57
 |  | TMK212BBJ106KG-T | None | C34, C35, C41, C42, C55, C56, C58, C60 | CMP-14477-000079-2 | New From Design | Out of date | 8 | Taiyo Yuden | TMK212BBJ106KG-T | Volume Production | Newark | 79T3103 | 0.018 | 0.144
 |  | TMUX1072RUTR | IC SWITCH SPDT DUAL 12UQFN | U21, U22, U23, U26, U30, U31 | CMP-04892-000114-1 | New From Design | Up to date | 6 | Texas Instruments | TMUX1072RUTR | Volume Production | Arrow Electronics | TMUX1072RUTR | 0.8256 | 4.95
 |  | TPS2116DRLR | 1.6-V to 5.5-V, 40-mΩ, 2.5-A, low-IQ, priority power multiplexer 8-SOT-5X3 -40 to 125 | U32, U34 |  | Not managed |  | 2 | Texas Instruments | TPS2116DRLR | Volume Production | LCSC | C3235557 | 0.7096 | 1.42
 |  | TSM-105-01-L-DV | 0.025" SQ Post Header, Surface Mount, Vertical, -55 to 125 degC, 2.54 mm Pitch, 10-Pin, Male, RoHS | P4 | CMP-1024-00233-1 | Released | Up to date | 1 | Samtec | TSM-105-01-L-DV | Volume Production | Avnet | TSM-105-01-L-DV | 1.69 | 1.69
 |  | TSW-105-05-L-S | 0.025" SQ Post Header, Through-hole, Vertical, -55 to 125 degC, 2.54 mm Pitch, 5-Pin, Male, RoHS | P1 | CMP-1024-00366-1 | Released | Up to date | 1 | Samtec | TSW-105-05-L-S | Volume Production | Newark | 12P1441 | 0.827 | 0.827
 |  | WSL12062L000FEA18 |  | R7, R8, R72 | CMP-2003-04334-1 | Released | Up to date | 3 | Vishay Dale | WSL12062L000FEA18 | Volume Production | Digi-Key | 541-9996-1-ND | 0.76 | 2.28

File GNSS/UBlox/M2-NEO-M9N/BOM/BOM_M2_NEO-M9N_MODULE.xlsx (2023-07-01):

Comment | Description | Designator | Footprint | LibRef | Quantity | Digi-Key_Part_Number_1 | Digi-Key_Part_Number_2 | Digi-Key_Part_Number_3 | Manufacturer Part Number | Manufacturer Part Number 1 | Manufacturer_Part_Number
1uF 6V3 0402 | 0402 1 uF 6.3 V ±10% Tolerance X7R Multilayer Ceramic Capacitor | C1 | c0402 | CAP CER 1UF 6.3V X7R 0402 | 1 |  |  |  | GRM155R70J105KA12J
100nF 10V 0402 | CL05 Series 0.1 uF 10 V ±10 % Tolerance X7R SMT Multilayer Ceramic Capacitor | C2 | c0402 | CAP CER 0.1UF 10V X7R 0402 | 1 |  |  |  | CL05B104KP5NNNC
10nF 50V 0402 | CAP CER 10000PF 50V X7R 0402 | C3, C5 | c0402 | CAP CER 10000PF 50V X7R 0402 | 2 |  |  |  | GCM155R71H103KA55D
47pF 50V 0402 | 0402 47 pF 50 V ±5 % Tolerance NP0 SMT Multilayer Ceramic Capacitor | C4 | c0402 | CAP CER 47PF 50V C0G/NPO 0402 | 1 |  |  |  | CC0402JRNPO9BN470
47uF_6.3V_1206 | Chip Multilayer Ceramic Capacitors for General Purpose, 1206, 47uF, X5R, 15%, 20%, 6.3V | C6, C7 | FP-GRM31C-0_2-e0_3_0_8-IPC_C | CMP-2000-06344-2 | 2
U.FL-R-SMT-1(10) | CONN U.FL RCPT STR 50 OHM SMD | J2 | FP-U_FL-R-SMT-1_10-MFG | CMP-2000-05152-3 | 1
27nH 350mA 0.46ohm 0402 | Multilayer type RF Inductor 27nH ±5% 0.46Ω 350mA 0402 | L1 | FP-LQG15HH_02-IPC_C | CMP-2000-06578-2 | 1 |  |  |  | LQG15HS27NJ02D
Green | LED High-Power Uni-Color Green 574nm 2-Pin Chip LED T/R | LED1, LED2 | led0603 | LED GREEN CLEAR CHIP SMD | 2 |  |  |  | LTST-C190KGKT
DMG2302UKQ-7 | N-Channel 20 V 2.8A (Ta) 660mW (Ta) Surface Mount SOT-23-3 | Q1 | SOT23 | DMG2302UKQ-7 | 1 | 31-DMG2302UKQ-7TR-ND | 31-DMG2302UKQ-7CT-ND | 31-DMG2302UKQ-7DKR-ND | DMG2302UKQ-7 |  | DMG2302UKQ-7
2N7002W | MOSFET N-CH 60V 115MA SOT-323 | Q2 | FP-419AB-01-IPC_C | CMP-07173-000098-1 | 1
0 ohm 0402 | RES SMD 0 OHM JUMPER 1/16W 0402 | R1, R5, R7, R8 | r0402 | RES 0 OHM JUMPER 1/16W 0402 | 4 |  |  |  | RC0402JR-070RL
10K_5%_0402 |  | R2, R11 | RESC1005X40X25LL05T10 | CMP-2002-07353-1 | 2
1K_1%_0402 | Chip Resistor, 1 KOhm, +/- 1%, 100 mW, -55 to 155 degC, 0402 (1005 Metric), RoHS, Tape and Reel | R3, R16 | RESC1005X40X25NL05T05 | CMP-1011-00510-4 | 2
10 OHM 1/4W 0603 | Res Surge Chip Thick Film 0603 10 Ohm 1% 1/4W ±200ppm/°C Molded Paper T/R | R4 | r0603 | RES SMD 10 OHM 1% 1/4W 0603 | 1 |  |  |  | SR0603FR-7T10RL
0_5%_0402 |  | R12, R13, R15 | RESC1005X40X25NL05T10 | CMP-2002-06457-1 | 3
NEO-M9N-00B | GNSS module, Flash, TCXO, SAW, LNA, LCC, 12x16 mm Professional Grade | U1 | IC_NEO-M9N | IC NEO-M9N-00B | 1 |  |  |  | NEO-M9N-00B

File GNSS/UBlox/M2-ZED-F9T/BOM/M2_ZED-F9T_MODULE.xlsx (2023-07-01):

Comment | Description | Designator | Footprint | LibRef | Quantity | Digi-Key_Part_Number_1 | Digi-Key_Part_Number_2 | Digi-Key_Part_Number_3 | Manufacturer Part Number | Manufacturer Part Number 1 | Manufacturer_Part_Number
1uF_25V_0402 | Cap Ceramic 1uF 25V X5R ±10% SMD 0402 +85°C Paper T/R | C1, C2, C3, C4, C5 | FP-CL542-IPC_C | CMP-13271-001051-1 | 5
47uF_6.3V_1206 | Chip Multilayer Ceramic Capacitors for General Purpose, 1206, 47uF, X5R, 15%, 20%, 6.3V | C6, C7 | FP-GRM31C-0_2-e0_3_0_8-IPC_C | CMP-2000-06344-2 | 2
100nF | None | C9, C10, C11 | FP-0402-L_1_0_0_05-W_0_5-IPC_B | CMP-14477-000330-2 | 3
10nF | Chip Multilayer Ceramic Capacitors for General Purpose, 0201, 10000pF, X7R, 15%, 10%, 16V | C12 | FP-GRM033-0_03-IPC_B | CMP-06035-000448-1 | 1
PESD0402-140 | TVS DIODE 14V 40V 0402 | D1 | FP-PESD0402-MFG | CMP-08607-000011-1 | 1 |  |  |  | PESD0402-140
LTST-C191KGKT | LED GREEN CLEAR SMD | D2, D3 | FP-LTST-C191KGKT-MFG | CMP-2000-05198-2 | 2
47nH 300mA | Multilayer type RF Inductor 47nH ±5% 0.72Ω 300mA 0402 | L1 | FP-LQG15HH_02-IPC_B | CMP-06042-015783-1 | 1
U.FL-R-SMT-1(01) | Ultra Small Coaxial Connector, 6 GHz, -40 to 90 degC, 3-Pin SMD, RoHS, Bulk | P1 | HRS-U.FL-R-SMT-3_V | CMP-2000-05153-1 | 1
NTR2101PT1G | Small Signal MOSFET, -8 V, -3.7 A, Single P-Channel, 3-Pin SOT-23, Pb-Free, Tape and Reel | Q1 | ONSC-SOT-23-3-318-08_V | CMP-1058-00758-1 | 1
1k | 1kΩ ±1% 0.063W 0402 Thick Film Chip Resistor AEC-Q200 compliant | R1, R4, R7, R10, R17, R18 | FP-RMCF0402-MFG | CMP-26527-000026-1 | 6
0_5%_0402 |  | R2, R3, R12, R13, R15 | RESC1005X40X25NL05T10 | CMP-2002-06457-1 | 5
100k | 100kΩ ±1% 0.063W 0402 Thick Film Chip Resistor AEC-Q200 compliant | R9, R11 | FP-RMCF0402-IPC_C | CMP-2000-06984-2 | 2
22_1%_1218 1.5W | RES Thick Film, 22.6Ω, 1%, 1.5W, 100ppm/°C, 1218 | R16 | FP-CRCW1218-HPe3-MFG | CMP-02407-011337-1 | 1
ZED-F9T-00B | Multi-band GNSS Receiver with Nanosecond-level Timing Accuracy | U1 | GPS_ZED-F9T | GPS_ZED-F9T | 1 |  |  |  | ZED-F9T-00B
SN74LVC3G07DCUR | Triple Buffer/Driver With Open-Drain Output, DCU0008A, LARGE T&R | U3 | DCU0008A_N | CMP-0859-00615-3 | 1
LPV511MGX/NOPB | micropower Rail-to-Rail Input and Output Operational Amplifier, 5-pin SC-70, Pb-Free | U4 | DCK0005A_N | CMP-0055-01065-3 | 1

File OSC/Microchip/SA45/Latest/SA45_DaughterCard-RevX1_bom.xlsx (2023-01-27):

Designator | Description | Comment | Footprint | Quantity | Manufacturer | Fitted | Manufacturer Part Number
C1 | CAP, CER, X5R, 1UF, 10%, 35V, 0402, 0.55MM T | Murata_GRM155R6YA105KE11D | CAPC1005X061N | 1 | Murata | Fitted | GRM155R6YA105KE11D
C2, C3, C6, C12 | CAP, CER, X5R, 0.10UF, 10%, 50V, 0402, 0.55MM T | Murata_GRM155R61H104KE14D | CAPC1005X055N | 4 | Murata | Fitted | GRM155R61H104KE14D
C4 | CAP, CER, NP0, 33PF, 5%, 25V, 0201, 0.33MM T | Murata_GRM0335C1E330JA01D | CAPC0603X033N | 1 | Murata | Fitted | GRM0335C1E330JA01D
C5, C7 | CAP, CER, X5R, 10UF, 10%, 35V, 0805, 1.45MM T | Murata_GRM21BR6YA106KE43L | CAPC2013X145N | 2 | Murata | Fitted | GRM21BR6YA106KE43L
C8, C10, C11 | CAP, CER, X5R, 22UF, 20%, 10V, 0805, 1.40MM T | Murata_GRM21BR61A226ME51L | CAPC2013X140N | 3 | Murata | Fitted | GRM21BR61A226ME51L
C9 | CAP, CER, X5R, 3300PF, 10%, 10V, 0201, 0.33MM T | Murata_GRM033R61A332KA01D | CAPC0603X033N | 0 | Murata | Not Fitted | GRM033R61A332KA01D
J1, J2 | STANDOFF, ROUND, M2X0.4 STEEL 4MM, 9774040243R | Wurth_9774040243R | TH000V_300DIAx400_001mt_9774040243R | 2 | Wurth Elektronik | Fitted | 9774040243R
J3, J4, J5, J6 |  | Keystone_4871 | Keystone_4871 | 4 | Keystone Electronics | Fitted | 4871
L1 |  | 4.7uH | Eaton_HCM0703-4R7-R | 1 | Eaton | Fitted | HCM0703-4R7-R
P1, P2, P3, P4, P5, P6, P7, P8, P9, P10 | CONN, PC PIN, PRESS-FIT, 10.16MM LENGTH, TIN, TH | Mill-Max_8600-0-05-80-00-00-03-0 | TH001V_109DIA_000mt_8600-0 | 10 | Mill-Max Manufacturing Corp. | Fitted | 8600-0-05-80-00-00-03-0
R1 |  | ERJ-3EKF1003V | RESC1608X55X30ML15T15 | 0 | Panasonic | Not Fitted | ERJ-3EKF1003V
R2 | RES SMD 91K OHM 1% 1/16W 0402 | Yageo_RC0402FR-0791KL | RESC1005X040N | 1 | Yageo | Fitted | RC0402FR-0791KL
R3 | RES, 0 OHM, 2A, 1/4W, 1206 | Yageo_RC1206JR-070RL | RESC3216X070N | 1 | Yageo | Fitted | RC1206JR-070RL
R4 | RES SMD 30K OHM 1% 1/16W 0402 | Yageo_RC0402FR-0730KL | RESC1005X040N | 1 | Yageo | Fitted | RC0402FR-0730KL
R5 | RES, 27K OHM, 1%, 1/10W, 100PPM/C, 0402 | Panasonic_ERJ-2RKF2702X | RESC1005X040N | 0 | Panasonic | Not Fitted | ERJ-2RKF2702X
R6 | RES, 0.0 OHM, 0.5A, 1/20W, 0201 | Yageo_RC0201JR-070RL | RESC0603X026N | 1 | Yageo | Fitted | RC0201JR-070RL
U1 |  | Microchip_SA45 | Microchip_SA45 | 1 | Microchip | Fitted | 090-02984-001
U2 |  | IQD_ICPT-1 | IQD_ICPT-1 | 0 | IQD | Not Fitted | IQD-ICPT-1
U3 |  | DiodesInc_AP63356QZV-7 | DiodesInc_AP63356QZV-7 | 1 | Diodes Incorporated | Fitted | AP63356QZV-7

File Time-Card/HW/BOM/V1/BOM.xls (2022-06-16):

Line # | Name | Description | Designator | Quantity | Manufacturer 1 | Manufacturer Part Number 1
DNP | AUX Sensor | Header, 4-Pin | P3 | 1
 | MAC-SA5X | MOD, MAC, MAC-SA5X, ATOMIC CLOCK | U10 | 1 | Microchip | MAC-SA5X
 | 901-143-6RFX | Coaxial connector, 50 Ohm, -65 to 165 degC, 5-Pin THD, RoHS, Bulk | AN1, AN2, AN3, AN4 | 4 | Amphenol RF | 901-143-6RFX
 | 1909763-1 | Ultra Miniature Coaxial Connector Jack, 60 V, 50 Ohm, -40 to 90 degC, RoHS, Tape and Reel | J5, J6, J9, J10 | 4 | TE Connectivity AMP | 1909763-1
 | 8240136 | TVS Diode WE-TVS-HS, VRWM=3.3V | D1, D2 | 2 | Wurth Electronics | 8240136
 | AT24MAC402-STUM-T | IC EEPROM 2K I2C 1MHZ SOT23-5 | U7 | 1 | Microchip | AT24MAC402-STUM-T
 | FPGA_CONN |  | P1,P2, P3, P4 | 4 | Panasonic | AXK680347YG
 | BAT54SW | DIO, SCHOTTKY, BAT54S, DUAL SERIES, 30V, 200MA, SC-70 | D5, D6, D7, D8 | 4 | Diodes | BAT54SWQ-7-F
 | BME280 | SENSOR PRESSURE HUMIDITY TEMP | U14 | 1 | Bosch | BME280
 | BMX160 | IMU ACCEL/GYRO/MAG | U13 | 1 | Bosch Sensortec | BMX160
 | CAP_0603_0.01UF_50V | CAP, CER, 0.01UF, 50V, 10%, X7R, 0603 | C3, C4 | 2 | KEMET | C0603C103K5RACTU
 | C0603X104K5RACAUTO |  | C2, C9, C10, C11, C12, C15, C16, C17, C18, C19, C21, C23, C24, C25, C26, C27, C28, C29, C30, C31, C32, C33, C59, C61, C63 | 25 | KEMET | C0603X104K5RACAUTO
 | CAP_0402_0.1UF_50V | CAP, CER, 0.1UF, 50V, 10%, X7R, AEC-Q200, 0402 | C44, C45, C46, C47, C48, C49, C50, C51, C52, C53 | 10 | TDK | CGA2B3X7R1H104K050BB
 | ERJ-3EKF4701V | Precision Thick Film Chip Resistor, 4.7 KOhm, +/- 1%, -55 to 155 degC, 0603 (1608 Metric), RoHS, Tape and Reel | R26, R27 | 2 | Vishay | CRCW06034K70FKEA
 | CRCW080533R0FKEA | RES, 33 OHM, 1%, 1/8W, TF, 0805 | R18, R19, R20, R21 | 4 | Vishay | CRCW080533R0FKEA
 | CRCW0603110RFKEA |  | R12 | 1 | Vishay | CRCW0603110RFKEA
 | DFLZ39-TP | DIO, ZENER, DFLZ39, 39V, 5%, 1W, SOD123FL | D3 | 1 | MCC | DFLZ39-TP
 | DS90LV027AQMA | Automotive LVDS Dual Differential Driver, 8-pin Narrow SOIC | U3 | 1 | TI National Semiconductor | DS90LV027AQMA
 | DS90LV028AQMA | Automotive LVDS Dual Differential Line Receiver, 8-pin Narrow SOIC | U4 | 1 | TI National Semiconductor | DS90LV028AQMA
 | ERJ-3EKF4702V | RES, 47K, 1%, 1/10W, TF, 0603 | R2, R3, R4 | 3 | Panasonic | ERJ3EKF4702V
 | ERJ-2GE0R00X | RES, 0. OHM, 1%, 1/16W, TF, AEC-Q200, 0402 | R23, R24 | 2 | Panasonic | ERJ-2GE0R00X
 | ERJ-3EKF1002V | RES, 10K, 1%, 1/10W, TF, 0603 | R6, R7 | 2 | Panasonic | ERJ-3EKF1002V
 | ERJ-3EKF2000V | RES, 200 OHM, 1%, 1/10W, TF, 0603 | R1, R16, R28, R29, R30 | 5 | Panasonic | ERJ-3EKF2000V
 | ERJ-3EKF2201V | RES, 2.2K, 1%, 1/10W, TF, 0603 | R8, R9 | 2 | Panasonic | ERJ-3EKF2201V
 | ERJ-3EKF2612V | RES, 26.1K, 1%, 1/10W, TF, 0603 | R5 | 1 | Panasonic | ERJ-3EKF2612V
 | ERJ-3EKF4701V | RES, 4.7K, 1%, 1/10W, TF, 0603 | R22 | 1 | Panasonic | ERJ-3EKF4701V
 | GCM188R71H333KA55D |  | C20, C22 | 2 | Murata | GCM188R71H333KA55D
 | HTST-105-01-L-DV-A | CONN, HDR, 2X5, VERT, 0.1IN SHROUDED, SMT, HTSH SERIES | U5 | 1 | Samtec | HTST-105-01-L-DV-A
 | MP1482DS-LF | IC, DC/DC, MP1482DS, >4.75VIN, 0.923-15V OUT, SOIC8 | U1, U2 | 2 | Monolithic Power Systems | MP1482DS-LF-Z
 | NC7SZ125M5 | IC BUF NON-INVERT 5.5V SOT23-5 | U6, U8, U11, U12 | 4 | ON Semiconductor / Fairchild | NC7SZ125M5
 | PM124SH-100M-RC | IND, PWR, 10.uH, 20%, 4A, 0.04DCR, 12.5X12.5MM, SHLD | L1, L2 | 2 | Bourns JW Miller | PM124SH-100M-RC
 | RC0603FR-074K7L | Chip Resistor, 4.7 KOhm, +/- 1%, 0.1 W, -55 to 155 degC, 0603 (1608 Metric), RoHS, Tape and Reel | R10, R11 | 2 | Yageo | RC0603FR-074K7L
 | RC0603FR-0749R9L | General Purpose Chip Resistor, 49.9 Ohm, +/- 1%, -55 to 155 degC, 0603 (1608 Metric), RoHS, Tape and Reel | R13, R14, R15, R17, R25 | 5 | Yageo | RC0603FR-0749R9L
 | RCB-F9T | MOD, GPS | U9 | 1 | u-blox | RCB-F9T
 | RMCF0603FT10K0 | Chip Resistor, 10 KOhm, +/- 1%, 0.1 W, -55 to 155 degC, 0603 (1608 Metric), RoHS, Tape and Reel | R37 | 1 | Stackpole Electronics | RMCF0603FT10K0
 | FUSE_0603_2.00A | FUSE SLOW 2.00A 32V M 0603 | F1 | 1 | Bourns | SF-0603S200-2
 | RED_LED | LED, RED, SML-LX0603, 635NM, 2V, 20MA, 0603 | D4, D11, D12, D13, D14 | 5 | Lumex | SML-LX0603IW-TR
 | CAP_0805_10UF_25V | CAP, CER, 10.UF, 25V, 10%, X5R, 0805 | C1, C5, C6, C7, C8, C13, C14, C58, C60, C62 | 10 | Taiyo Yuden | TMK212BBJ106KG-T

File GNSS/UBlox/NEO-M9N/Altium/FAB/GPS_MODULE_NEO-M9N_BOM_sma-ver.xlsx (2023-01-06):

Designator | Fitted | Quantity | Manufacturer | Manufacturer Part Number 1 | Supplier 1 | Supplier Part Number 1 | Footprint | Description | Comment
C4 | Fitted | 1 | Yageo | CC0402JRNPO9BN470 | Digi-Key | 311-1021-1-ND | c0402 | 0402 47 pF 50 V ±5 % Tolerance NP0 SMT Multilayer Ceramic Capacitor | 47pF 50V 0402
R1, R5, R7, R8 | Fitted | 4 | Yageo | RC0402JR-070RL | Digi-Key | 311-0.0JRCT-ND | r0402 | RES SMD 0 OHM JUMPER 1/16W 0402 | 0 ohm 0402
R4 | Fitted | 1 | Yageo | SR0603FR-7T10RL | Digi-Key | YAG5824CT-ND | r0603 | Res Surge Chip Thick Film 0603 10 Ohm 1% 1/4W ±200ppm/°C Molded Paper T/R | 10 OHM 1/4W 0603
R6, R9, R10 | Not Fitted | 0 | Yageo | RC0402JR-070RL | Digi-Key | 311-0.0JRCT-ND | r0402 | RES SMD 0 OHM JUMPER 1/16W 0402 | DNI 0 ohm 0402
LED1, LED2 | Fitted | 2 | Vishay Lite-On | LTST-C190KGKT | Digi-Key | 160-1435-1-ND | led0603 | LED High-Power Uni-Color Green 574nm 2-Pin Chip LED T/R | Green
U1 | Fitted | 1 | u-blox | NEO-M9N-00B | Digi-Key | 672-NEO-M9N-00BCT-ND | IC_NEO-M9N | GNSS module, Flash, TCXO, SAW, LNA, LCC, 12x16 mm Professional Grade | NEO-M9N-00B
R2, R3 | Fitted | 2 | TE Connectivity | CRGP0402F10K | Digi-Key | A130367CT-ND | r0402 | Res Thick Film 0402 10K Ohm 1% 0.125W(1/8W) ±100ppm/°C Pad SMD T/R | 10K 1/8W 0402
J1 | Fitted | 1 | Sullins | NRPN042MAMS-RC | Digi-Key | S6009-04-ND | CONN_NRPN042MAMS-RC | Dual Row 8 Position 2 mm Pitch Surface Mount Header | NRPN042MAMS-RC 2MM
C2 | Fitted | 1 | Samsung | CL05B104KP5NNNC | Digi-Key | 1276-1002-1-ND | c0402 | CL05 Series 0.1 uF 10 V ±10 % Tolerance X7R SMT Multilayer Ceramic Capacitor | 100nF 10V 0402
C1 | Fitted | 1 | Murata | GRM155R70J105KA12J | Digi-Key | 490-13339-1-ND | c0402 | 0402 1 uF 6.3 V ±10% Tolerance X7R Multilayer Ceramic Capacitor | 1uF 6V3 0402
C3, C5 | Fitted | 2 | Murata | GCM155R71H103KA55D | Digi-Key | 490-4762-1-ND | c0402 | CAP CER 10000PF 50V X7R 0402 | 10nF 50V 0402
L1 | Fitted | 1 | Murata | LQG15HS27NJ02D | Digi-Key | 490-2628-1-ND | L0402 | Inductor RF Chip Multi-Layer 27nH 5% 100MHz 8Q-Factor Air 300mA 460mOhm DCR 0402 Paper T/R | 27nH 300mA 460mohm 0402
Q1 | Fitted | 1 | Diodes | DMG2302UKQ-7 | Digi-Key | 31-DMG2302UKQ-7CT-ND | SOT23 | N-Channel 20 V 2.8A (Ta) 660mW (Ta) Surface Mount SOT-23-3 | DMG2302UKQ-7
J2 | Fitted | 1 | Bel Cinch | 142-0711-301 | Digi-Key | J717-ND | CONN_131-3711-301 | Rf Coaxial Board Mount Connector | SMA_142-0711-301

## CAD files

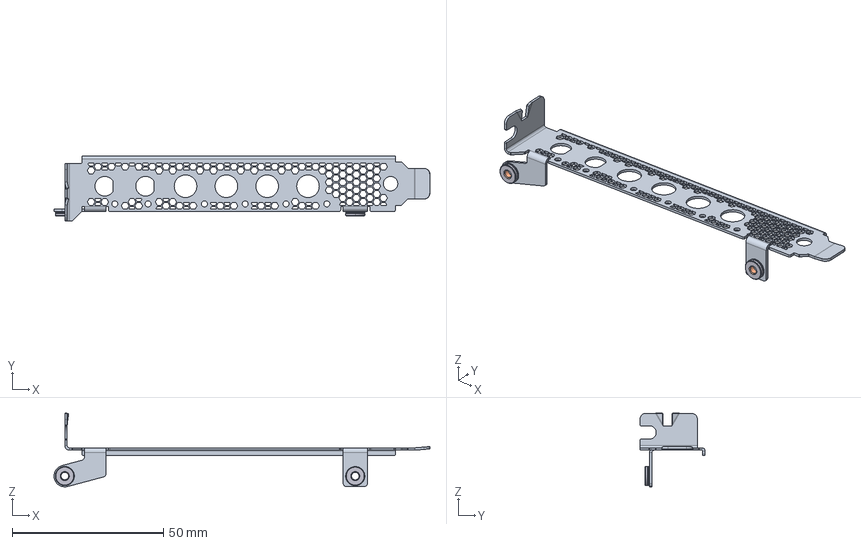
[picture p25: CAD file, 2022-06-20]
HW/MCAD/PCIE Bracket V4/time_card_bracket_v4_asm.stp
124.4 x 21.6 x 24.4 mm
TIME_CARD_BRACKET_V4
PENN_S-M3-0ZI x 2

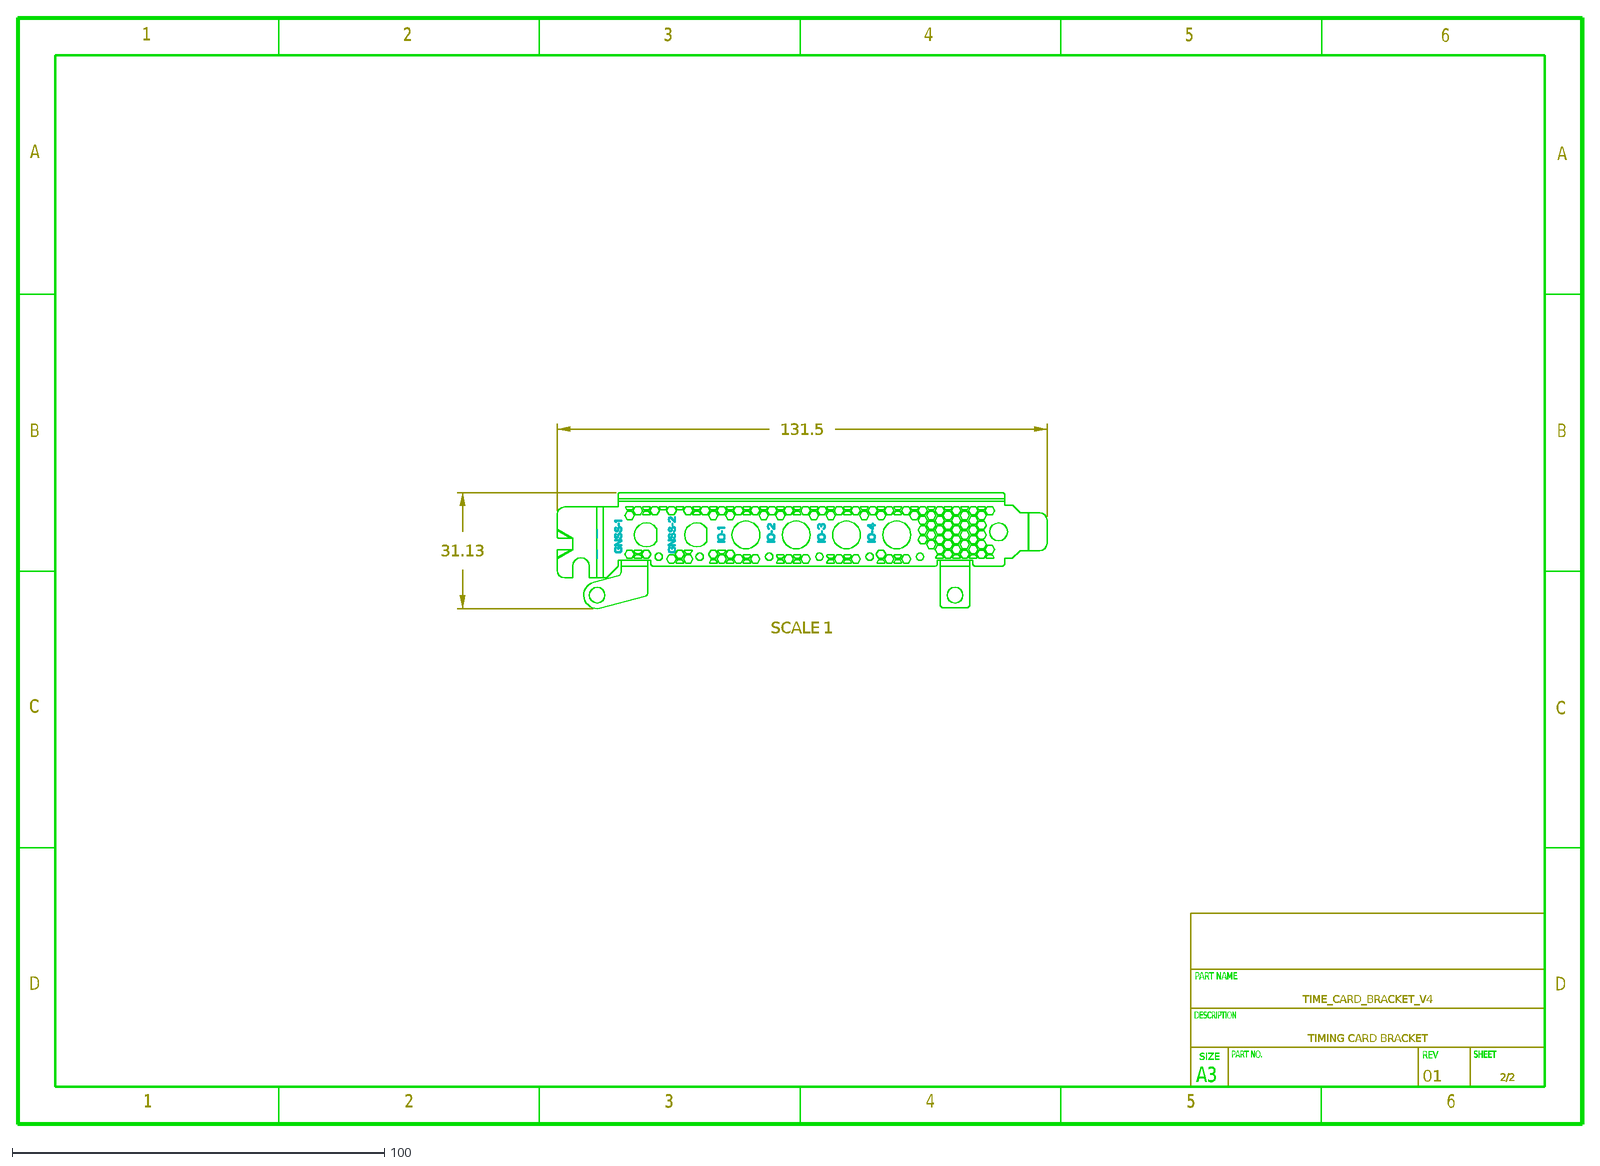
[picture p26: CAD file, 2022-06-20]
HW/MCAD/PCIE Bracket V4/timecard_bracket_v4_2.dxf
1
2
3
4
5
6
A
B
C
D
DESCRIPTION
PART NO.
PART NAME
SHEET
A3
REV
131.5
31.13
TIME_CARD_BRACKET_V4
TIMING CARD BRACKET
SIZE
/
01
SCALE

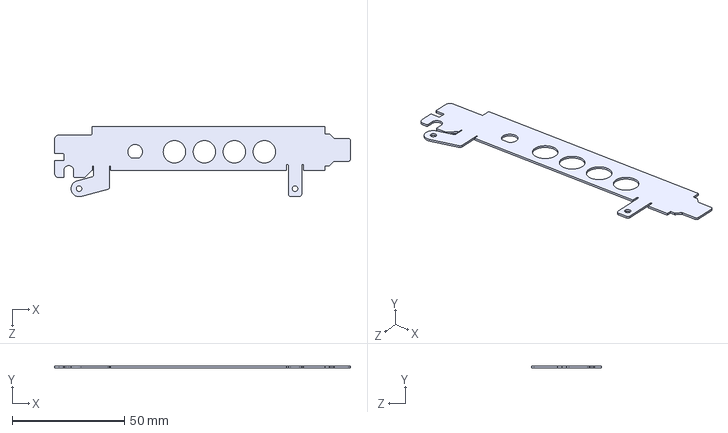
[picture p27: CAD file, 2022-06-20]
Time-Card/HW/MCAD/PCIe Bracket V3/PCIe Bracket for Timing Card V3 - Flattened.STEP
131.8 x 0.8 x 31.4 mm

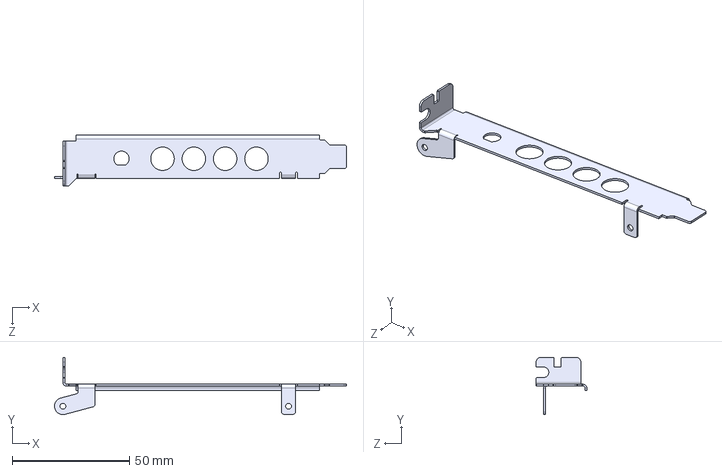
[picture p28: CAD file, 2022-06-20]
Time-Card/HW/MCAD/PCIe Bracket V3/PCIe Bracket for Timing Card V3.STEP
124.4 x 24.4 x 21.6 mm

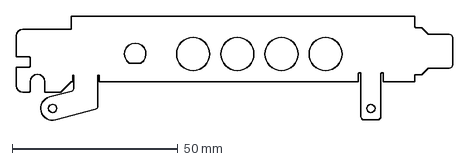
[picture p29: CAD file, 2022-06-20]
Time-Card/HW/MCAD/PCIe Bracket V3/PCIe Bracket for Timing Card V3 - Flat Pattern.DXF
131.8 x 31.8 mm

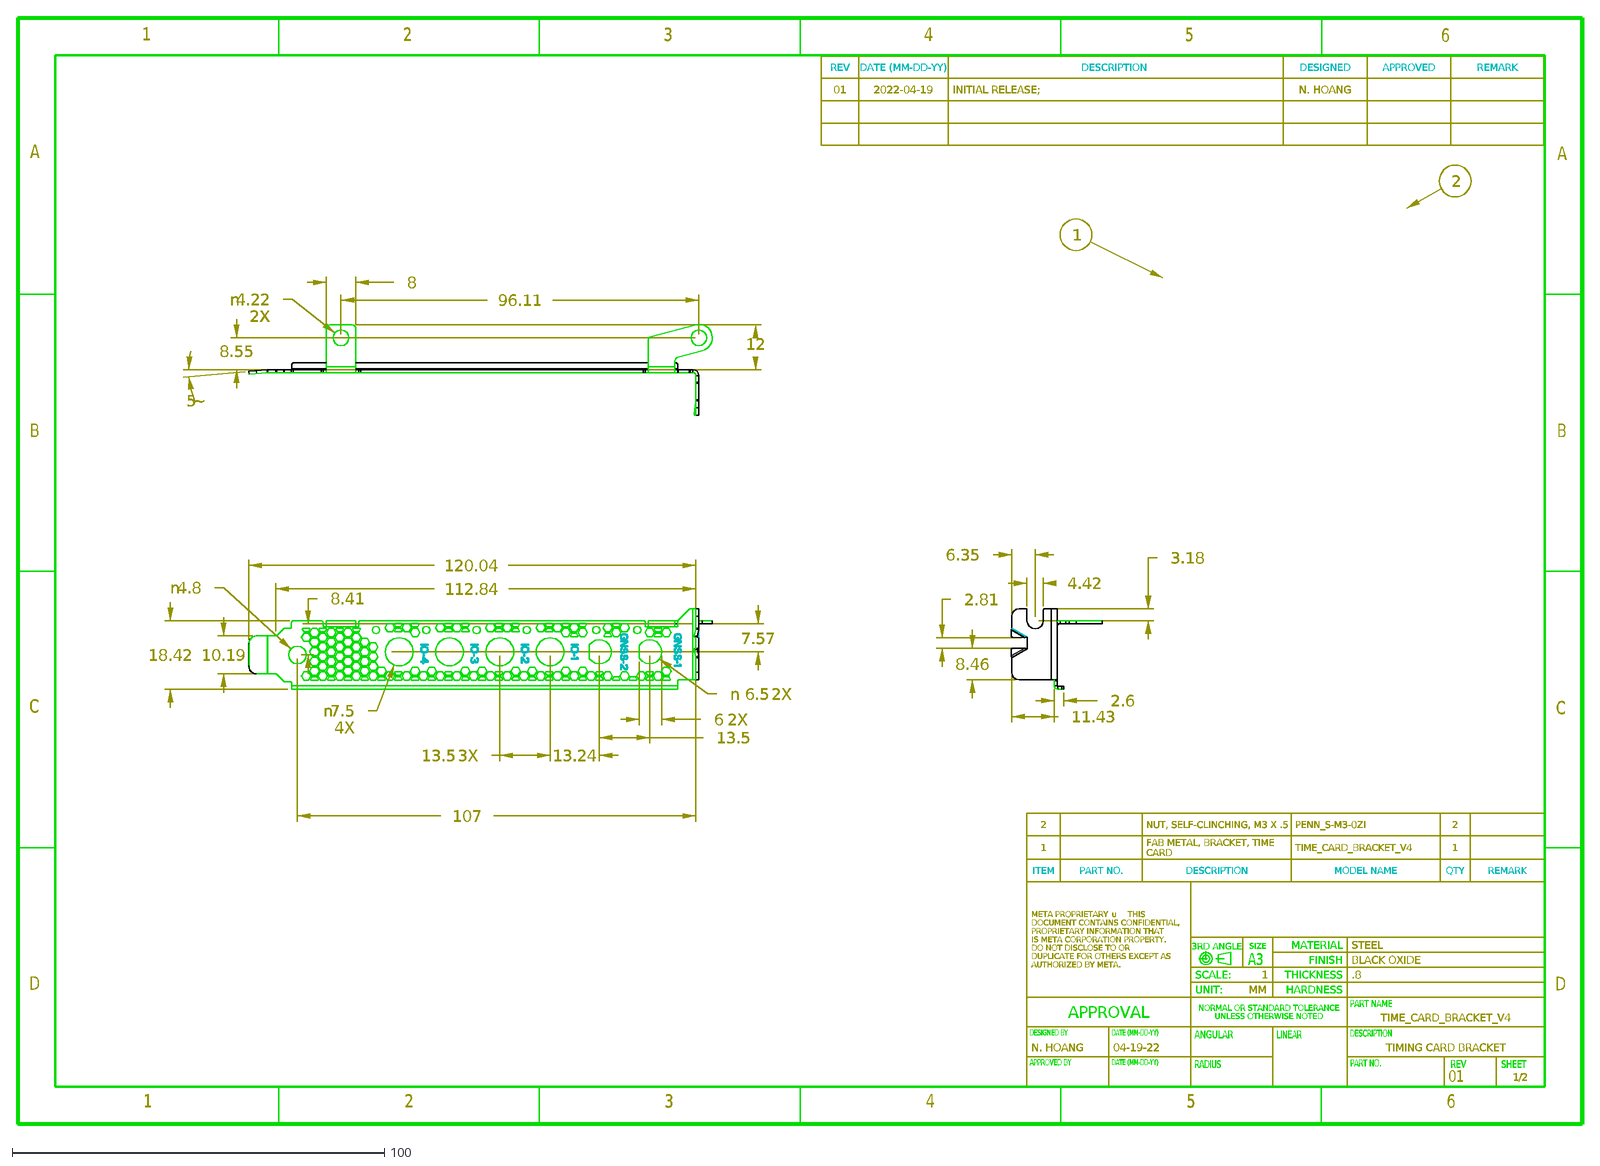
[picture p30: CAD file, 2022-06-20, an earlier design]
HW/MCAD/PCIE Bracket V4/timecard_bracket_v4_1.dxf
1
2
3
4
5
6
A
B
C
D
SHEET
PART NAME
PART NO.
DESCRIPTION
A3
ANGULAR
RADIUS
LINEAR
DESIGNED BY
APPROVED BY
DATE (MM-DD-YY)
REV
18.42
10.19
4.8
120.04
112.84
107
7.5
4X
13.5
3X
6.5
2X
7.57
13.24
8.41
4.22
96.11
8.55
12
8
11.43
8.46
2.81
4.42
3.18
6.35
2.6
/
TIMING CARD BRACKET
TIME_CARD_BRACKET_V4
NORMAL OR STANDARD TOLERANCE
UNLESS OTHERWISE NOTED
HARDNESS
MM
UNIT:
.8
THICKNESS
SCALE: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

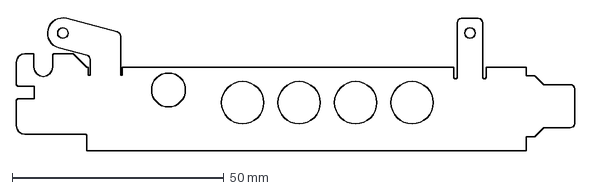
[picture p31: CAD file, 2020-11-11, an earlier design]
HW/MCAD/Archive/PCIe Bracket V2/PCIe Bracket for Timing Card V2 - Flat Pattern.DXF
131.8 x 31.8 mm

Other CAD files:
HW/MCAD/Archive/PCIe Bracket V2/PCIe Bracket for Timing Card V2.STEP
Time-Card/HW/MCAD/PCIe Bracket V2/PCIe Bracket for Timing Card V2.STEP
HW/MCAD/Archive/PCIe Bracket V2/PCIe Bracket for Timing Card V2 - Flattened.STEP
Time-Card/HW/MCAD/PCIe Bracket V2/PCIe Bracket for Timing Card V2 - Flattened.STEP
HW/MCAD/Archive/PCIe Bracket V2/PCIe Bracket for Timing Card V2.SLDDRW
HW/MCAD/Archive/PCIe Bracket V2/PCIe Bracket for Timing Card V2.sldprt
HW/MCAD/Archive/PCIe Bracket V3/PCIe Bracket for Timing Card V3.SLDDRW
HW/MCAD/Archive/PCIe Bracket V3/PCIe Bracket for Timing Card V3.sldprt
Time-Card/HW/MCAD/PCIe Bracket V2/PCIe Bracket for Timing Card V2.SLDDRW
Time-Card/HW/MCAD/PCIe Bracket V2/PCIe Bracket for Timing Card V2.sldprt
Time-Card/HW/MCAD/PCIe Bracket V3/PCIe Bracket for Timing Card V3.SLDDRW
Time-Card/HW/MCAD/PCIe Bracket V3/PCIe Bracket for Timing Card V3.sldprt

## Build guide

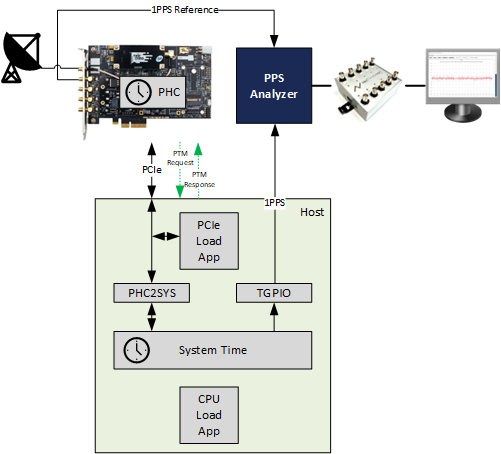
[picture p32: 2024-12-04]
images/PTM_Setup.png

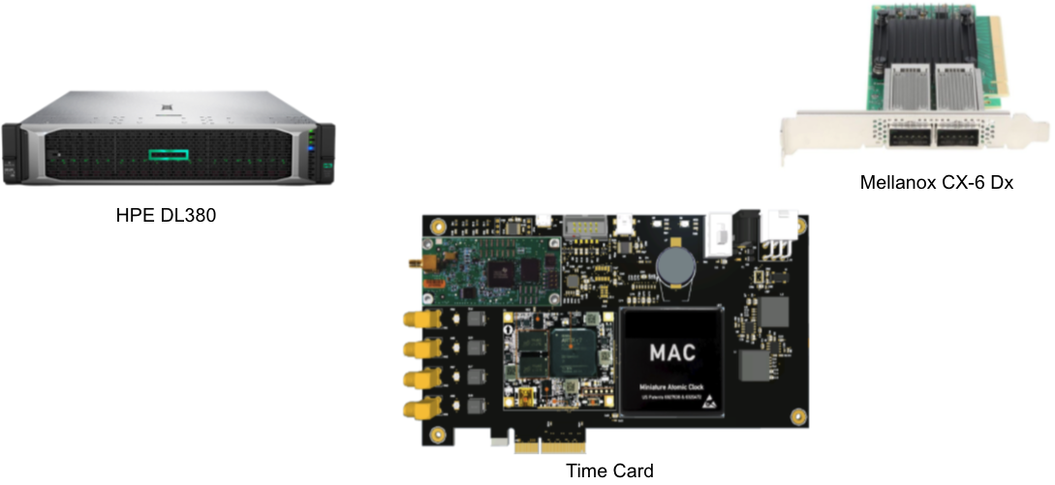
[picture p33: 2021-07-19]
images/OTS_assembly-2.png

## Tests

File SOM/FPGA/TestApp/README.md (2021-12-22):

# TestApp
Just for bring-up or testing without a linux driver.
Code is not maintained anymore.

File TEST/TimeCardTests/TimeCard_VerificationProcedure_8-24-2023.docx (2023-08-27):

1. Plug in the Time Card to your Linux machine PCIe slot and turn on the system
2. Once the PC is booted up, open a terminal

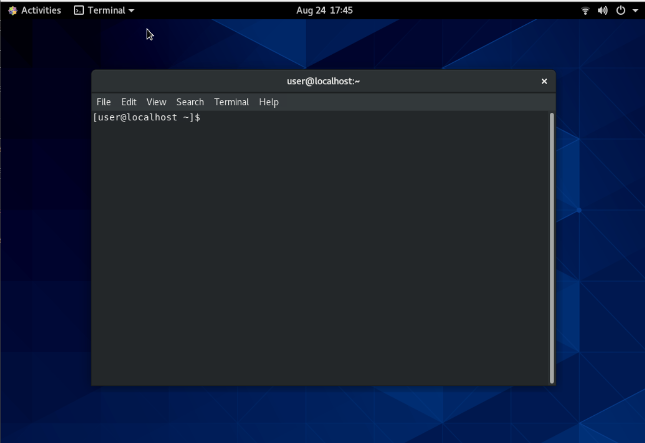
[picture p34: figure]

3. Run lspci | grep Meta , verify you see a device listed like this

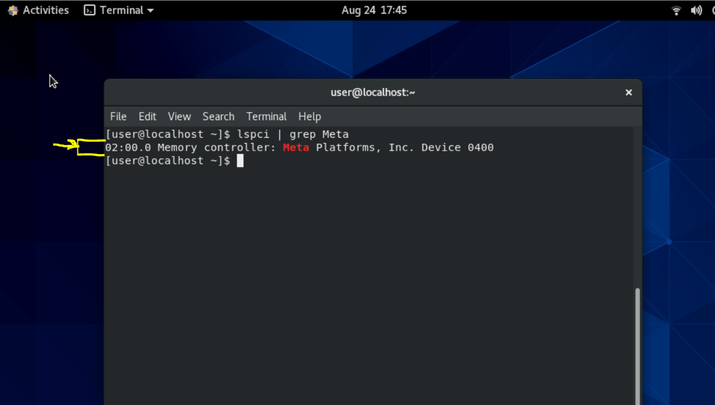
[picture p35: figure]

4. Run modprobe ptp_ocp , then dmesg | grep ptp_ocp . Verify you see messages from ptp_ocp in the output

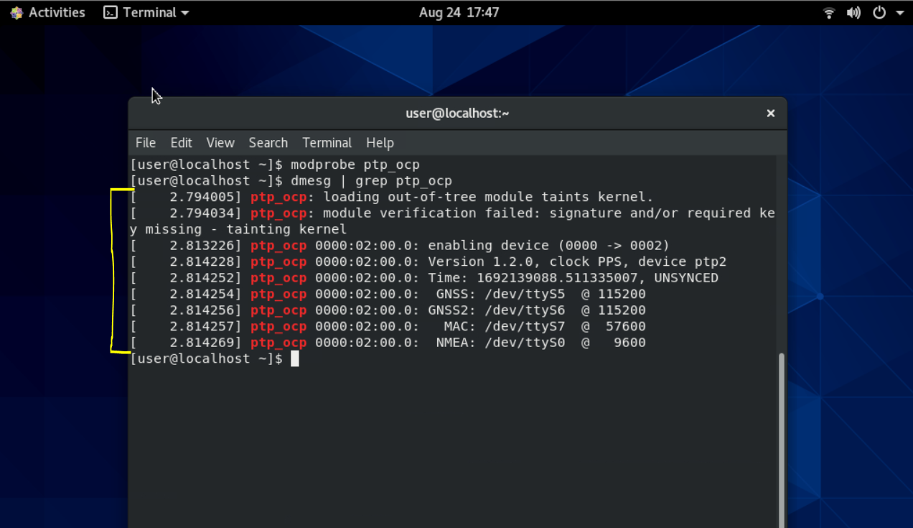
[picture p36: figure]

5. To verify the GPS module, run sudo tio -b 115200 /dev/ttyS5 , using the /dev/ttyS device listed as GNSS: in the dmesg output, as shown here

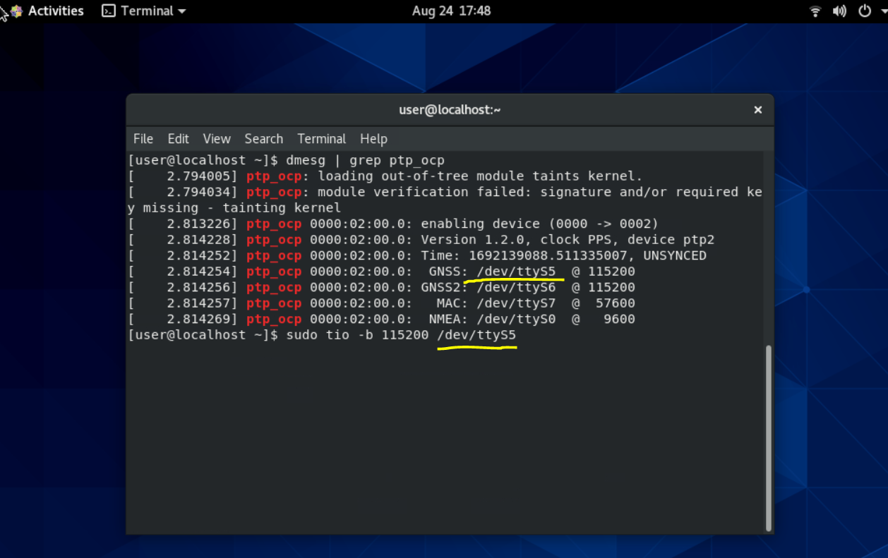
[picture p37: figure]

6. You should see messages scrolling , this is the binary output from the GPS receiver which is good

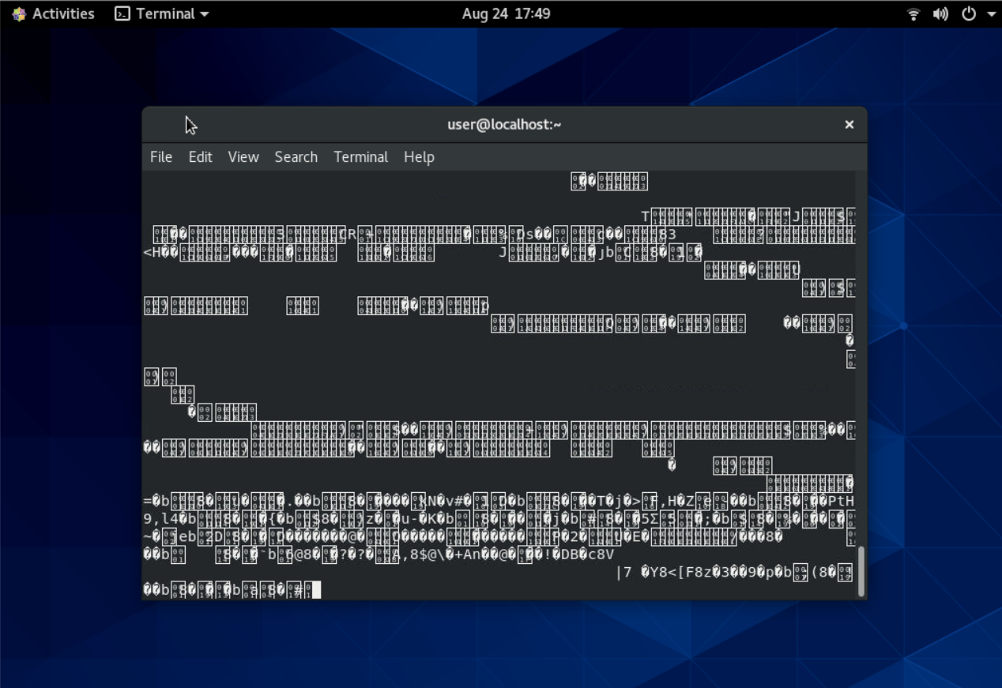
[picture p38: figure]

7. Use ctrl+t then q to quit out of tio

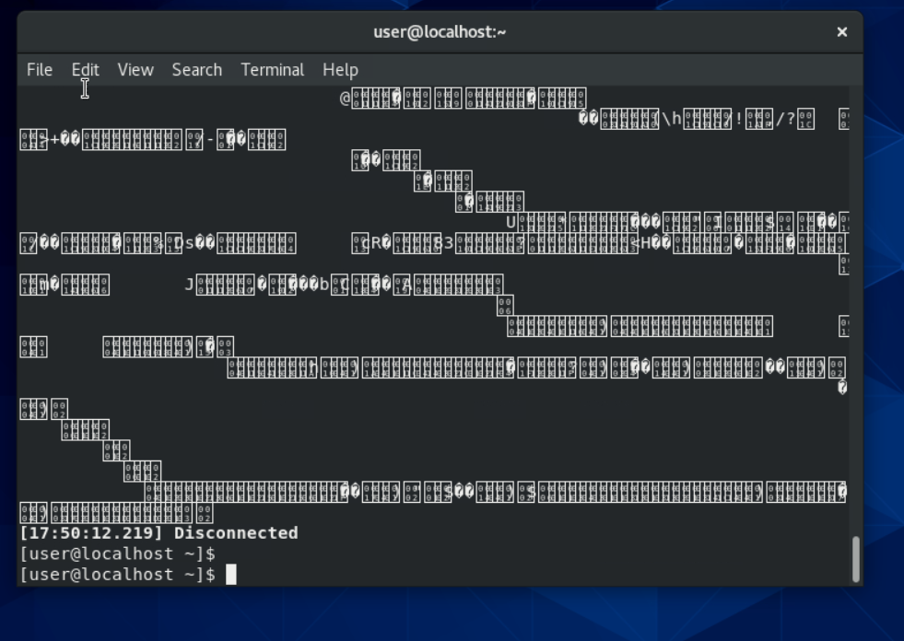
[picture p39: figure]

8. Verify the GPS fully
  a. If this is the first time doing this, run these commands to install
    i. sudo yum install python3
    ii. sudo yum install python3-tkinter
    iii. sudo python3 -m pip install --upgrade pip
    iv. sudo python3 -m pip install --upgrade Pillow
    v. sudo python3 -m pip install pygpsclient
9. Run su to enter root, enter your root password
10. Run pygpsclient , a GUI will pop up

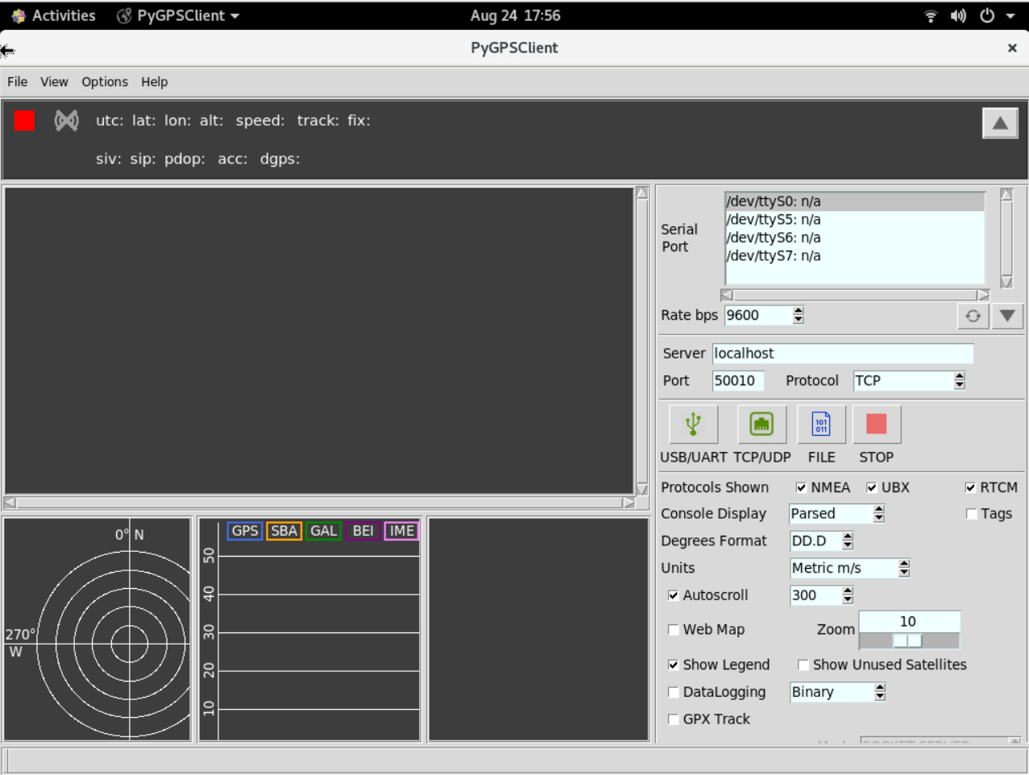
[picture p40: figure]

11. Select the GNSS /dev/ttyS device used earlier in TIO , in my example it is /dev/ttyS5 , and change the Rate bps to 115200

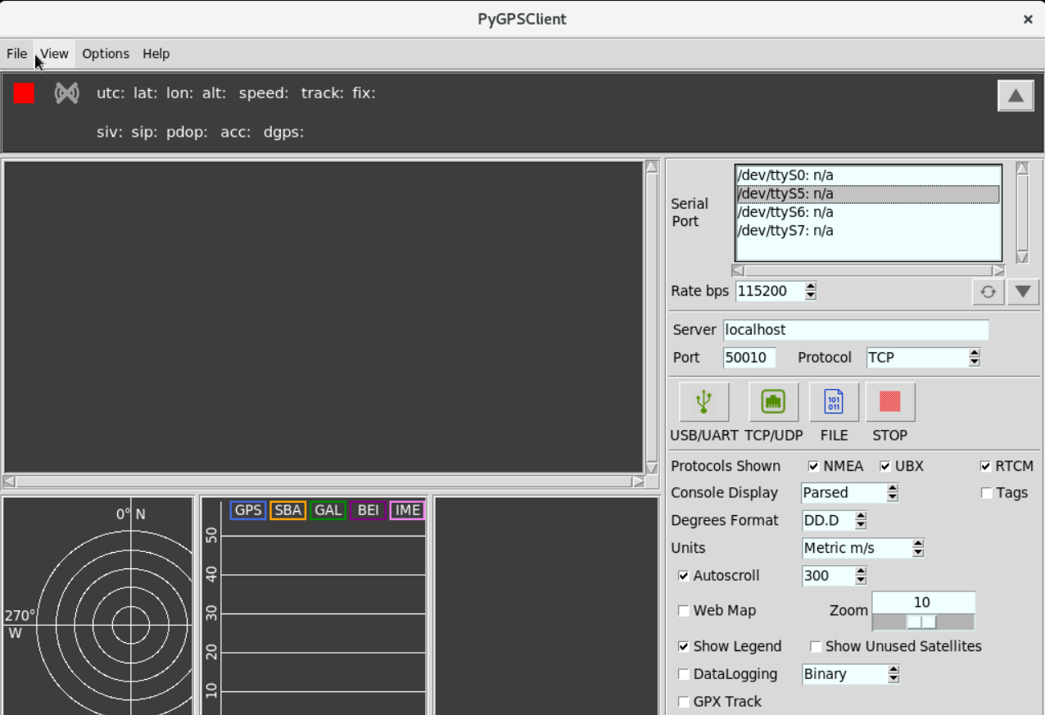
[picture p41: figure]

12. Press the USB/UART button to connect

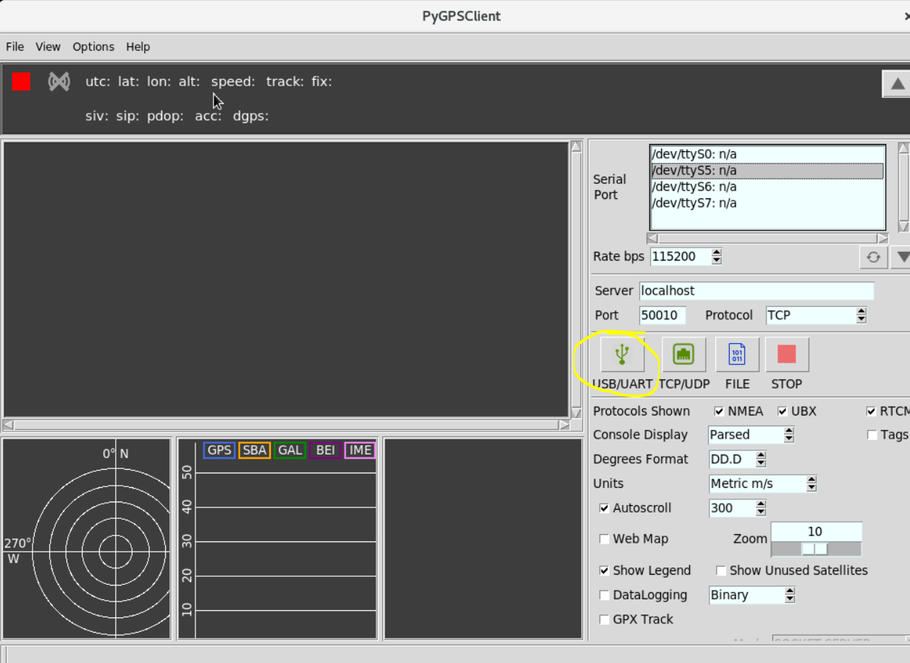
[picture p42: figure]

13. If you have a GPS antenna connected, you should see full GPS information from the device, like this example. If no GPS antenna is connected, you should at least see some <UBX messages in the text box. This will fully verify the GPS operation

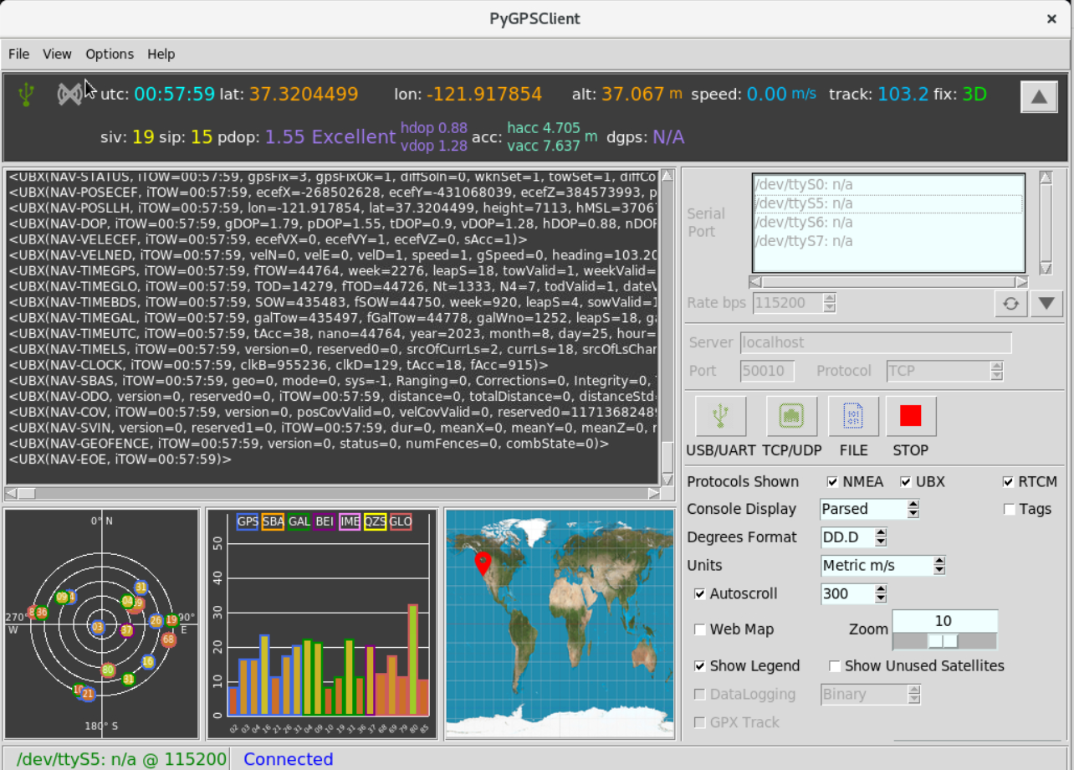
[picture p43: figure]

14. Close out of the PyGPSClient
15. To verify all the SMAs are working properly , run the following commands
  a. sudo echo OUT: PHC >> /sys/class/timecard/ocp0/sma1
  b. sudo echo OUT: PHC >> /sys/class/timecard/ocp0/sma2
  c. sudo echo OUT: PHC >> /sys/class/timecard/ocp0/sma3
  d. sudo echo OUT: PHC >> /sys/class/timecard/ocp0/sma4
16. Measure the four SMA outputs on an oscilloscope. You should see a 1Hz signal coming out of every SMA
17. To verify the frequency signal, run the following commands
  a. sudo echo OUT: 10Mhz >> /sys/class/timecard/ocp0/sma1
  b. sudo echo OUT: 10Mhz >> /sys/class/timecard/ocp0/sma2
  c. sudo echo OUT: 10Mhz >> /sys/class/timecard/ocp0/sma3
  d. sudo echo OUT: 10Mhz >> /sys/class/timecard/ocp0/sma4
18. Measure the four SMA outputs on an oscilloscope. You should see a 10MHz signal coming out of every SMA

This verifies the FPGA, the oscillator, and the GPS, verifying the time card is fully operational.

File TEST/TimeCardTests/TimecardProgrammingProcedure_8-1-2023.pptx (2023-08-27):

## 1. Connect JTAG dongle to Time Card header


## Open Vivado


## Open Hardware manager


## Click Open Target -> Auto Connect


## Right click on xc7a100t_0, click Add Configuration Memory Device


## Find and select this memory device


## When this pops up, press OK


## Select the programming file, then select these options, then hit Apply , then hit ok


## Programming will run and it will alert you when finished


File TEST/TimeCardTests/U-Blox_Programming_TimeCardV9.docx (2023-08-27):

1. Open u-center 22.07


2. Power the Time Card V9 through PCIe with a host and connect the back micro-USB port to your computer running u-center. You should see the two green LEDs on the Time Card, meaning the Time Card power is working.


3. Select the COM port that shows up in U-center under Receiver -> Connection, for example COM25. It will display that at the top of U-center window.


4. Flip these two DIP switches so D21 and D12 are lit


5. In u-center, the default baud rate for the NEO-M9N is 38400. It should auto detect, but you can manually set it in Receiver -> Baud rate -> 38400. This will show at the top of u-center.
6. Verify the connection is made. In u-center, go to view -> Binary console. A window in u-center should pop up, and you should see messages from the NEO-M9N, like this


7. Go under Tools -> Receiver configuration in u-center, a new window will pop up.


8. Select the NEO-M9N configuration file timingCardUBXM9_PPS_115200_Monitor.txt that is part of the github repo for the Time card, located here: https://github.com/opencomputeproject/Time-Appliance-Project/tree/master/Time-Card/GNSS/UBlox/NEO-M9N/Configs/NEO-M9N-00B-00


9. Press Transfer file -> GNSS


10. U-center should auto-update the baud rate from 38400 to 115200 by the end of the programming procedure. If not, manually change the baud rate under Receiver -> Baudrate to 115200


11. Go through the procedure to Transfer File -> GNSS one more time, to make sure all the configuration went through, steps 7-9. This is because the baud rate change may interfere with some configuration parameters.
12. To save the configuration persistently, go under Receiver -> Action -> Save Config. Run that twice, again to make sure it’s done.
13. After completed, please flip the two DIP switches back to allow for normal operation with the FPGA on the Time Card for GNSS2, so D21 and D12 LEDs on the board are off

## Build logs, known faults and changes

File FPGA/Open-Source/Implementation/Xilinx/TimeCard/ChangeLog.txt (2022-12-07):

20221207 Version: 0x0005
- Added SMA status Reg to read back the value of SMA inputs
- Added CommunicationSelector IP to select between UART and I2C for the communication with the MAC/Clock
- Added header to the bin-file with PCIe id information (gotham version)
- Updated project and docs
- Added to the implementation Readme.md info about the AXI GPIO regs
- Minor updates in the implementation, scripts, docs and binaries

20220601 Version: 0x0001
- Initial Release of the Open Source version for the TimeCard (Base System)

20220919 Version: 0x0003
- Extended Base System with PPS-Slave and TOD-Slave 

20220601 Version: 0x0001
- Initial Release of the Open Source version for the TimeCard (Base System)

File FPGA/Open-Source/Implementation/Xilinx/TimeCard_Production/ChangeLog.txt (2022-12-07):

20221207 Version: 0x8001
- Initial Release of the Open Source version for the Production TimeCard (not SOM version)

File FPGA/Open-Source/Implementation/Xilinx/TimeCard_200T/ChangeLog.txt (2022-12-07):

20221207 Version: 0x0005
- Initial Release of the 200T FPGA Open Source version for the TimeCard

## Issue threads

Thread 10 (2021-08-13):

BOM and schematic errata

wisxxx, 2021-08-13:
**BOM**

- item 41 (DS3231 RTC) shows "U5" as ref des. schematic shows "U3A"

- item 40 (1x3 header) does not have corresponding jumpers

- item 29 (IC REG BUCK  ADJUSTABLE 2A 8SOIC). Data sheet says this part is not recommended for new designs  (add 210817)

- no BOM item for CSAC and SA.3x/SA.5x

- no BOM item for U11 (sch. p.6,A2; assume SiT5721)

- no BOM item for U13 (sch. p.6,B4; assume SiT5356)

- no BOM item for U4 (sch. p.5,C5; BMP388. Note: this part is not recommended for new designs)

- no BOM item for U7 (sch. p.5,D5; AT24MAC402-STUM-T)

**SCHEMATIC**

- p. 6,C2

    MAC devices SA.3x and SA.5x are labeled "RV-3049-C3"

    Need notation: "Install one of CSAC, SA.3x, or SA.5x".

    Assuming connector U10B would interfere with installation of the CSAC or
    SA.3x oscillators, need notation: "Install U10B (connector) only if using SA.5x oscillator."

The nets **MAC_10Mout**, **MAC_10Mout**, **MAC_RF_OUT**, and **MAC_FREQ_CTL** are all shorted, as are **MAC_PPSout** and **MAC_PPS_OUT+**, and **MAC_PPSin** and **MAC_PPSIN0+**. This is  probably related to the oscillator stuffing options as well.

The output dotting should only be on p. 6 where the oscillators are drawn and not on p. 7 at the connector. There should be a note clarifying the operation under the alternative stuffing options (including R17, the zero ohm resistor to GPS_TP1).

ahmadexp, 2021-08-14:
Love it. Thank you so much. I will go through the correction list.

wisxxx, 2021-09-20:
It appears the the analog frequency control input to the MAC-SA5x oscillator is connected to a digital I/O pin in the FPGA. Is this intended?

In 'Timingcard_SCHEMATICS_BETA_V1.pdf", p. 6,A3 and p. 7,B4, the MAC_FREQ_CTRL net connects the MAC-SA5x INPUT FREQUENCY CONTROL pin (#1) to the FPGA board CON2-B33.

According to the AC7100B FPGA board schematic ("AC7100B_SDM.pdf"), CON2-B33 is routed to Xilinx pin AA10, which is listed in the XC7A100T pinout ("ug475_7Series_Pkg_Pinout.pdf") as a DQS (multifunction) pin.

I assume that analog frequency control is not enabled in the MAC-SA5x. Whatever, the wiring probably needs an update.

AlphaBetaPhi, 2021-09-20:
@wisxxx, this is correct. The analog tuning feature is not used and all tuning is performed through the digital interface.

On the FPGA this pin is not used either, it's a placeholder is for alternative versions should they arise in R&D.

Closed 2023-01-30.

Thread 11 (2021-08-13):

What are the IMU (BNO080) and barometric pressure sensor (BMP388) used for?

Nufflee, 2021-08-13:
As the title says, I'm curious what these sensors are used for in a time measurement device, furthermore because they don't seem to be mentioned anywhere outside of the ECAD.

ahmadexp, 2021-08-14:
The environmental and IMU sensors are used to monitor the surrounding condition since that directly affects the atomic clock especially when it is under holdover mode. Any changes or disturbances should be considered as a factor that increases the uncertainty.

Sent from my iPhone

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

Nufflee, 2021-08-14:
I see, thank you. Would you mind expanding on which specific environmental factors would increase the uncertainity of the system? Since this is made for datacenters I can't imagine a lot going on other than maybe some subtle vibrations and temperature/pressure changes.

ahmadexp, 2021-08-14:
That's right. Keep in mind, I designed the card fof general purpose application including DCs (as the first one). The datasheet of the SA53 talks about various environmental factors and their effect on the clock stability

Sent from my iPhone

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

wisxxx, 2021-09-17:
The MAC-SA5x data sheet (Microchip #DS00003348B, March 2021) only mentions temperature in terms of operating range and frequency drift:

  • Operating Temperature –40˚C to +75˚C
  • Temperature-induced frequency errors <5x10-11 Hz/Hz from –10˚C to +75˚C
  • Non-Operating (Storage & Transport):  –55˚C to +100˚C

Shock and Vibration are only specified with respect to maintaining lock.

Altitude (pressure) is only mentioned as a maximum for operation and storage/transport.

Can anyone explain how oscillator performance can be compensated for environmental effects based on what the spec sheet is presenting?

If loss of lock from temperature or shock/vibration occurs, won't other environmental monitoring in a data center be able to report? If localized over-temperature is a concern, then perhaps only that should be measured.

Closed 2021-08-18.

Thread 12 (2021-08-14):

BNO055 and environmental sensing

JoshSat, 2021-08-14:
Looking for more details on the IMU being used in this application.

Is it mainly for vibration detection with an accelerometer?
Is the magnetometer being used to measure the earth's magnetic fields and magnetic fields coming off other components?

thank you.

ahmadexp, 2021-08-14:
Vibration and shocks are known things that effect the holdover performance. Magnetometer just comes in the package. Perhaps it can be used to monitor magnetic field changes.

Sent from my iPhone

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

Closed 2021-08-18.

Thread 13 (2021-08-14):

Why different USB connectors (mini and micro)?

wisxxx, 2021-08-14:
Is there a reason that a mini USB connector (J3, p.3,C5) is used, vs. the micro USB on J4 (p.5,B6)?

The mini USB isn't very common and adds to BOM complexity.

Also, the micro USB connector shows as J4 on the schematic and J2 in the BOM.

ahmadexp, 2021-08-14:
All the USB ports are removed in the new design. Reason for different times of USB ports was to make the instruction for the technician much easier. Blue Cable (Mini-USB) goes to ..., Red Cable (Micro-USB) does to ...
The UART ports are now available via the PCIe bus

wisxxx, 2021-08-15:
Nice touch.

Closed 2021-08-15.

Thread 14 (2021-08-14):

Why DFLZ39 Zener diodes for +12V input isolation?

wisxxx, 2021-08-14:
The forward voltage drop of +1.2V seems excessive for simple isolation.

ahmadexp, 2021-08-14:
It will be removed. This was placed when we had the backup power source as well to keep the MAC up during short power cycles/loses

AlphaBetaPhi, 2021-08-15:
This is removed in the latest revision. Issue will be resolved with the next revision push.

Closed 2021-08-15.

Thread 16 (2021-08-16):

Is this absolute hard limit->PCIe x1 (18 pins) generation 3.0 or above

oiaohm, 2021-08-16:
There is a reason why is this a hard limit or is it that lower has not been tried.   If this card can work with generation 2.0/2.1 this opens a few other hardware options.

Raspberry Pi 4 Compute Module supporting boards can provide PCI 2.0 and RK3399 based boards can provide PCI 2.1.

Basically a 1U rack being able to hold primary secondary clock sync sources and few other extras.

For the Raspberry PI 4 Compute Module I am sure that "Jeff Geerling"
https://www.youtube.com/channel/UCR-DXc1voovS8nhAvccRZhg
would try the card.

Smaller setups its possible that something like a Raspberry PI 4 compute module would have enough processing power for like 50 machines worth of clock sync.    Think shop point of sales system.

wisxxx, 2021-08-18:
It would be electrically compatible (by PCIe definition), but the performance decrease would likely affect system operation.

It may be that there is an application where reduced accuracy, latency, and jitter is acceptable (e.g., a low cost time source). For such, it might be difficult to get the system validation under this project, given the time appliance's intended audience (time lords).

ahmadexp, 2021-08-18:
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

Time Card has no problem to run on PCIe x1. As a matter of fact, I tested it on the CM4. Jeff Geerling has a Time Card en-route. I am excited as you waiting for Jeff's magic with the Time Card.

oiaohm, 2021-08-18:
I think by that test the Readme can update.
https://github.com/opencomputeproject/Time-Appliance-Project/blob/master/Time-Card/README.md

PCIe x1 (18 pins) generation 3.0 or above << this comes a recommend for accuracy, latency, and jitter.   I would say test min could come 2.0.

Working on a CM4 board means it works with PCIe generation 2.0  the CM4 is a cut down PCIe 2.0 as it missing parts the specification says should be there.   Rockchip PCIe 2.1 will have no problem if a CM4 work.

I have a few different usage cases having a clock source that can run locally and not drift badly will be useful.   We have not had broken internet or jammed GPU for while now but its happened in the past.

https://centerclick.com/ntp/
I see this card as a better option to lot these GPS backed ones.   From what I can see this time card would be a more stable time source if GPS is disrupted.   Yes the atomic clock costs.   This is a rock pi S board based system as RK3308 CPU yes it cpu weaker than the cm4 as well.

There are a lot cases where the GPS time server in the network so some small arm based system.   Horrible even if they are built from open source supporting parts parts their software stack is common closed.   I have never felt happy having a time server that I cannot have audited at the source code level due to how much trouble a miss behaving time server can cause.

The facebook issue with closed source time source being a worry don't just apply to server farms.   It does apply to like pos setups where you want to keep the pos machines and the security system aligned for one.    Pos machines information aligned to bank processing information is also important that your clock has not drift too far.    Lower accuracy and jitter than data centres need but you cannot drifting by too much either.

Also looking at the card it looks like you could join 2 time card to each other by the PPS ports.   This could be useful in different setups.   So that cases like security system and pos systems on two different networks are in fact working on the same time with no general data link.   This is something I cannot do with the entry class gps time systems.   This also makes me wonder about a primary/secondary setup.   As in primary card has GPS and atomic lock and secondary card is only the fpga the job here would be to make the same time on two independent networks.

I know I am looking for same level accuracy that facebook is but I still need reasonable about of accuracy and precision in a lot of these cases  and have the problems when you have gps distruptions.   Of course for profit the more places the time card can be sold the better.

ahmadexp, 2021-08-19:
I am honored to see you passion for this project.

ahmadexp, 2021-08-19:
Jeff just received a Time Card and is going to do his magic to get it work on the CM4:
 https://github.com/geerlingguy/raspberry-pi-pcie-devices/issues/199

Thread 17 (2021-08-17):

FPGA IP Licensing

wisxxx, 2021-08-17:
What are the licensing or royalty arrangements for the FPGA intellectual property?

There appear to be six IP cores from NetTimeLogic in use.

ahmadexp, 2021-08-18:
The current license with NetTimeLogic allows the use of the bin file.
Alternatively we are working on a version without the proprietary IPs. Hopefully coming soon.

thschaub, 2021-08-20:
Exactly, it is allowed to use the IP cores as implemented in the bin file. If you have adaptation proposals which have a common interest we can also check if it make sense to adapt something as part of this binary license.

There are five NetTimeLogic IP Cores as part of the binary license included (PPS Slave, PPS Master, TOD Slave, Adjustable Clock and Signal Timestamper). The "UART to AXI" and "Static config" are included in the licensing of any other IP Core.
Additionally, there are IP Cores included from Xilinx (AXI UART, AXI Memory Mapped to PCI Express, AXI IIC, AXI GPIO etc.) which are under their end user license agreement:
https://www.xilinx.com/content/dam/xilinx/licenses/ip/end-user-license-agreement.pdf

Currently we are checking different options for a version without the proprietary IP.

geerlingguy, 2021-09-20:
@AlphaBetaPhi - Was there any other update on this or is this issue closed as other options won't be investigated at this time?

AlphaBetaPhi, 2021-09-20:
Hi @geerlingguy, we are still investigating this. I'll label appropriately.

thschaub, 2022-03-10:
There will be soon an update about the open source FPGA version.

https://www.opencompute.org/wiki/Time_Appliances_Project
on Mar-23, 2022, there will be a call about Open Time Card FPGA

wisxxx, 2022-06-03:
Thanks. I see the pinout in

…/Implementation/Xilinx/TimeCard/Constraints/PinoutConstraint.xdc

Good info.

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

wisxxx, 2022-06-07:
The pinout appears to show that the PCie interface is reduced to one lane. Am I reading it correctly?

thschaub, 2022-07-01:
> The pinout appears to show that the PCie interface is reduced to one lane. Am I reading it correctly?

Not really related to this topic.
If you build the open source FPGA project you could see the configuration of the PCIe memory mapped bridge in Vivado. And yes it's only one lane.

thschaub, 2023-01-26:
Full Open-Source Project including video tutorials available:
https://github.com/opencomputeproject/Time-Appliance-Project/tree/master/Time-Card/FPGA/

Closed 2023-01-26.

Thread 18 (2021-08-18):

Unknown connector

wisxxx, 2021-08-18:
What is this external connector? It isn't in the schematic, but seems to be associated with the GNSS receiver.

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

ahmadexp, 2021-08-18:
That is a simple RF proto module which allows you to build all kinds of filters, attenuators, etc...
At the moment I have a pass through (just a wire) inside it.
This was place there because we are planning to use an active antenna (GPS-OVER-FIBER) and that will require an attenuator (-30db) on the line to avoid receiver [input](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) saturation.

ahmadexp, 2021-08-18:
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

wisxxx, 2021-08-18:
Thanks. It seems then that I could use a simple SMA/SMA (or SMB/SMB) pass-through connector if I have a powered patch antenna a run of low-loss cable.

ahmadexp, 2021-08-18:
That's right. I have done that too.
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

Closed 2021-08-18.

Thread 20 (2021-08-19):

Not enough info for ordering

ErQrYfkrju, 2021-08-19:
Just want to know price for ordering on jlpcb.
Gerber files and BOM are present and loaded without problems, but no CPL. So can`t figure out resulting price.
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

ahmadexp, 2021-08-19:
@AlphaBetaPhi, what is a CPL file?

AlphaBetaPhi, 2021-08-20:
Hi @ErQrYfkrju,

I have pushed the pick and place assembly files to https://github.com/opencomputeproject/Time-Appliance-Project/tree/master/Time-Card/FAB/V1/ASSEMBLY

Closed 2021-08-20.

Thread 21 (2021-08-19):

Power to pressure sensor and IMU

wisxxx, 2021-08-19:
Why is +3.3V_CLEAN connected to VDDIO (pin 1) of the pressure sensor U4 (p. 5,B5)?

Similarly, why is +3.3V connected to VDD (pin 3) of the IMU U8 (p.5,C2)?

AlphaBetaPhi, 2021-08-20:
Hi @wisxxx,

We have deprecated the initial prototype version which was used as a development board for testing different vendors and clocks.

Please see [beta-v1 schematics](https://github.com/opencomputeproject/Time-Appliance-Project/blob/master/Time-Card/ECAD/Beta-V1/Timingcard_PROJECT_SCHEMATICS_BETA_V1.pdf)

 We will be releasing additional designs which tighten the requirements and improve performance of the device.

Closed 2021-08-20.

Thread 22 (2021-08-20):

beta-v1 schematics issues

wisxxx, 2021-08-20:
- What is "RV-3049-C3" (U10A and U10B, p.5,A3)?
- The labels on the off-page connectors on p. 6 seem to be interspersed with CR (0x0d) characters. The corresponding net names on other pages are OK.
- MP1482DS is marked "not recommended for new designs. refer to MP1476.
- There is no revision or date in the title block.
- U2 (p.4,A5) EEPROM I2C address is 0x00

wisxxx, 2023-01-30:
Fixed in subsequent versions.

Closed 2023-01-30.

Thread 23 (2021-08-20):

Driver compilation on Raspberry Pi (CM4) / Pi OS

geerlingguy, 2021-08-20:
I'm working on getting this thing working on a Raspberry Pi, running the latest version of Raspberry Pi OS:

```
$ uname -a
Linux cm4 5.10.52-v8+ #1441 SMP PREEMPT Tue Aug 3 18:14:03 BST 2021 aarch64 GNU/Linux

$ cat /etc/os-release
PRETTY_NAME="Debian GNU/Linux 10 (buster)"
NAME="Debian GNU/Linux"
VERSION_ID="10"
VERSION="10 (buster)"
VERSION_CODENAME=buster
ID=debian
HOME_URL="https://www.debian.org/"
SUPPORT_URL="https://www.debian.org/support"
BUG_REPORT_URL="https://bugs.debian.org/"
```

Right now the `remake` script fails with:

```
$ ./remake
Could not locate kernel source for distribution 'debiangnu/linux'
```

But if I update the script to allow debian in addition to ubuntu:

```diff
diff --git a/Time-Card/DRV/remake b/Time-Card/DRV/remake
index 61e0c73..77ed189 100755
--- a/Time-Card/DRV/remake
+++ b/Time-Card/DRV/remake
@@ -10,7 +10,7 @@ if [ "$*" == "install" ]; then
 fi

 case "$DIST" in
-    ubuntu)
+    debian*|ubuntu)
         KDIR=/usr/src/linux-headers-${KVER}
         ;;
     centos*)
```

Then I get:

```
$ ./remake
make: Entering directory '/usr/src/linux-headers-5.10.52-v8+'
  CC [M]  /home/pi/Time-Appliance-Project/Time-Card/DRV/ptp_ocp.o
/home/pi/Time-Appliance-Project/Time-Card/DRV/ptp_ocp.c:956:22: warning: ‘struct firmware’ declared inside parameter list will not be visible outside of this definition or declaration
         const struct firmware *fw)
                      ^~~~~~~~
/home/pi/Time-Appliance-Project/Time-Card/DRV/ptp_ocp.c: In function ‘ptp_ocp_devlink_flash’:
/home/pi/Time-Appliance-Project/Time-Card/DRV/ptp_ocp.c:968:12: error: dereferencing pointer to incomplete type ‘const struct firmware’
  resid = fw->size;
            ^~
/home/pi/Time-Appliance-Project/Time-Card/DRV/ptp_ocp.c: In function ‘ptp_ocp_devlink_flash_update’:
/home/pi/Time-Appliance-Project/Time-Card/DRV/ptp_ocp.c:1012:50: error: ‘struct devlink_flash_update_params’ has no member named ‘fw’
  err = ptp_ocp_devlink_flash(devlink, dev, params->fw);
                                                  ^~
make[1]: *** [scripts/Makefile.build:280: /home/pi/Time-Appliance-Project/Time-Card/DRV/ptp_ocp.o] Error 1
make: *** [Makefile:1824: /home/pi/Time-Appliance-Project/Time-Card/DRV] Error 2
make: Leaving directory '/usr/src/linux-headers-5.10.52-v8+'
```

geerlingguy, 2021-08-20:
@philhartung mentioned [here](https://github.com/geerlingguy/raspberry-pi-pcie-devices/issues/199#issuecomment-902946392) that it may be because Pi OS ships with a 5.10 kernel, whereas 5.11 or newer is required for the module to build. I'm now testing compiling in the driver from kernel source on 5.14... we'll see how it goes (see issue mention above this comment).

ahmadexp, 2021-08-20:
I speculate that is due to using a older version of gcc (the built-in for Pi vs the one on CentOS (C++11))
@jlemon, any insight on this?

ATR83-05, 2021-09-04:
Egnnn

Closed 2021-09-21.

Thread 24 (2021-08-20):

PCIe Bracket V3 dimensions

wisxxx, 2021-08-20:
The vertical hole centers are referenced to the top surface of the short bend section at the upper end of the bracket. This position, being on the outside of the bend, is not as well controlled as the bottom surface. The CEM and off-the-shelf brackets all use the bottom surface as a reference.

The horizontal hole centers _are_ properly referenced to the inside of the bend of the ears.

Also, not specified are:
- the overall length of the bracket
- the tapered section on the lower end
- the widths and lengths of the mounting tabs
- the width of the stiffener opposite the mounting tabs

wisxxx, 2021-09-17:
SMA connectors do not appear centered in the cutouts when the .STP model is combined with a 3D model of the connectors (Amphenol 901-143-6RFX, from SnapEDA) mounted on a 1.57 mm (61.8 mil) thick board. The offset is estimated to be about 0.64 mm.

The connector model dimensions appear match the part drawings. Both models are very close to their correct positions vertically. Mounting the bracket on the top side of of the board puts the connectors below the center of the cutouts.

It may be that the cutouts are oversized to accommodate different SMA connectors. Is that the case?

looking from outside:
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

zoom
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

mounting detail
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

ahmadexp, 2021-09-17:
@wisxxx, I really want to thank you for all the amazing reviews you have been doing on the time card.

wisxxx, 2023-01-30:
Addressed in bracket V4 docs.

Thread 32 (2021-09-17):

Accelerometer and Pressure Sensors

wisxxx, 2021-09-17:
In the now-closed issue #11, the requirements for acceleration and pressure sensor were laid to the MAC-5x oscillator data sheet. However...

The MAC-SA5x data sheet (Microchip #DS00003348B, March 2021) only mentions temperature in terms of operating / non-operating range, and frequency drift:

• Operating Temperature –40˚C to +75˚C
• Temperature-induced frequency errors <5x10-11 Hz/Hz from –10˚C to +75˚C
• Non-Opera

ting (Storage & Transport): –55˚C to +100˚C

Shock and Vibration are only specified with respect to maintaining lock.

Altitude (pressure) is only mentioned as a maximum for operation and storage/transport.

Can anyone explain how oscillator performance can be compensated for environmental effects based on what the spec sheet is presenting?

If loss of lock from temperature or shock/vibration occurs, won't other environmental monitoring in a data center be able to report? If localized over-temperature is a concern, then perhaps only that should be measured.

Are there any other citations for these environment impacts that are relevant to this application?

AlphaBetaPhi, 2021-09-29:
Hi @wisxxx,

The purpose of these sensors is to collect environmental information local to the card for purposes of analyzing the data trends over longer periods of time. We report all data over the PCIe driver and can be used for determining effects of temperature, vibration, shock, and aging in cases where holdover is critical.

wisxxx, 2021-09-29:
Does this drive the placement of the sensor then? To capture the effect on the oscillator, it seems it would ideally be placed on the back side of the board, centered in the oscillator footprint. That would capture the Z axis motion most effectively - a simple sign change (if needed), compared to extrapolation from some other position on the board (along with the resonant mode analysis required to make it worthwhile).

Closed 2021-09-29.

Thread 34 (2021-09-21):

EEPROM write protect input driven by +1.5V signal

wisxxx, 2021-09-21:

wisxxx, 2021-09-21:
Looking at "Timingcard_SCHEMATICS_BETA_V1.pdf", the AT24MAC402 serial EEPROM WP input (p. 4,A5) is driven by the EXT_EEPROM_WP signal from the FPGA board (pin P1A-44, p. 6,B5) and a 10K pullup to +3.3V.

The AT24MAC402 is operating on +3.3V. VIL min is specified as VCC x 0.7 = +2.31 V.

The FPGA pin driving the signal to P1A-A44 (net B34_L21_P) is driven by Bank 34, which is a +1.5V block.

- Does the 10k pullup to +3.3V guarantee a valid logic high into the EEPROM? It seems to depend on a very large output resistance in the FPGA buffer, given the 10K pullup value.
- Can the FPGA output reliably sustain the back-drive (nominal 180 uA)?

ref: AC7100 FPGA SoM schematic "AC7100B_SDM.pdf" (p. 6,D2; p.12,D4), "AC7100B User Manual.pdf".

AlphaBetaPhi, 2021-09-21:
Hi @wisxxx,

Thank you for a great issue.

This is correct. The WP has been moved to a 3.3V bank in the next version we are evaluating.

wisxxx, 2022-06-04:
EEPROM write protect is +1.5V signal in new FPGA description

File: PinoutConstraint.xdc, lInes: 75-77

```
#EEPROM
set_property PACKAGE_PIN V9 [get_ports EepromWp_DatOut]
set_property IOSTANDARD **LVCMOS15** [get_ports EepromWp_DatOut]
```

wisxxx, 2023-01-13:
**Not fixed** in file: Time-Appliance-Project/blob/master/Time-Card/FPGA/Open-Source/Implementation/Xilinx/**TimeCard**/Constraints/PinoutConstraint.xdc

**Is fixed** (moved to pin AA13) in file: Time-Appliance-Project/blob/master/Time-Card/FPGA/Open-Source/Implementation/Xilinx/**TimeCard_Production**/Constraints/PinoutConstraint.xdc

thschaub, 2023-01-13:
Just to clarify: The constraint files are for two different hardware versions. That's why they are different. The FPGA pinout constraints are simply configured that it matches with the hardware. So you will never see a "fix" in the constraints file since they are related to a specific hardware.

wisxxx, 2023-01-30:
Fixed in recent FPGA pushes.

Closed 2023-01-30.

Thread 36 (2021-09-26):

MAC_USB_PWR

wisxxx, 2021-09-26:
MAC_USB_PWR goes to connector P1B-B8 and thence to FPGA pin V8, IO_L14P_T2_SRCC_13, per the AC7100 schematics.

This is curious, since USB power is +5V and there is no +5 going to the FPGA. Also, what kind of IOH spec does that thing have?

wisxxx, 2023-02-27:
Fixed in production board (ref. schematic "R4006-G0001-03-SC-REV02.pdf").

Closed 2023-02-27.

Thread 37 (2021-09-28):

PCIe clock capacitors

wisxxx, 2021-09-28:
The PCIe clock has DC blocking capacitors. Is that correct?

Ref: Timingcard_SCHEMATICS_BETA_V1.pdf, p. 3,A4/A5.

AlphaBetaPhi, 2021-09-29:
Hi @wisxxx,

This is correct, a value of 100nF is acceptable and verified on the design.

Closed 2021-09-29.

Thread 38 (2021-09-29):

Updated FPGA

wisxxx, 2021-09-29:
"Time-Card/SOM/FPGA/TimeCard_FPGA.png" shows an extra GNSS receiver (UART and PPS connections) as well as an UART in the upper left that is not labelled. These don't appear on the SOM connector P1 of the current schematic ("Timingcard_PROJECT_SCHEMATICS_BETA_V1.pdf", p.7). This change is reflected in the FPGA binaries directory as well.

- Are they being resurrected from the initial design shown in "Time-Card/ECAD/Prototype-V0/Timingcard_PROJECT.pdf"?
- Or, are they simply no-connects on P1?
- Or, can we expect a new design with an FPGA replacing the AC7100 SOM? If so, when would that land?

AlphaBetaPhi, 2021-09-29:
Hi @wisxxx,

We are currently evaluating a set of configuration variants for the Timecard which we plan to release in a few weeks. Additionally, there will be support for backward compatibility.

thschaub, 2021-12-10:
We try to keep backwards compatibility of the FPGA image where ever possible. The base functionality should work on all Hardware revisions.
So it might be that you see in the FPGA more or different features which are not available on a specific HW revision.
The FPGA image provides the features as in the description but it is possible that the base board Timecard does not map the pins from the SOM.

The not labled UART (Communication UART to access the AXI Adddress Space) is answer in #39

Closed 2023-01-30.

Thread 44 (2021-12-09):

I found a mistake I think

wlong-coxeve, 2021-12-09:
1. "Time-Card\SOM\FPGA\Readme.pdf" shows that ANT1 and ANT2 are input ports;
However, "Time-Card\ECAD\Beta-V1\USER_IO.SchDoc" shows that ANT1 and ANT2 are output ports;
Futhermore, i can only get 10MHz (from my crystal oscillator) on the 4th pin of the "U8"(NC7SZ125M5), and there is nothing output on all four SMA ports ".

Q1: Could you please explain the contradiction?

2. “Time-Card\GNSS\UBX\RCB-F9T\README.md" recommands me to program the GNSS module by the UBX U-Center, but the 9th generation GNSS is not supported for the function of programming by U-Center.

Q2: Is it necessary for me to only get PPS on timecard port?
Q3: Does the RCB-F9T blong to 9th generation GNSS ? If so, How can I resolve it？

Last but not least, all these problems are based on the fact that I did not plug in PCIe, but only the external 12V power supply.

Thank you so much !!!

thschaub, 2021-12-09:
**Q1:** Your observation is in general correct. The schematics you are reffering does not match with the FPGA readme. The schematics is a beta (should we replace this once? @ahmadexp) and it was wrong because with this you loose the backwards compatibility. Do you have produced your own PCB?
On the [picture ](https://github.com/opencomputeproject/Time-Appliance-Project/blob/master/Time-Card/images/timingcard.png) you can see that it was patched on the hardware.

So in short the FPGA/Readme.pdf is correct.

**2.** In the u-center I am using 9th generation is supported (Version 20.06.01)

**Q2:** I don't understand what you exactly mean by this?

**Q3:** I guess so but as mentioned I don't see there any problem with U-Center

The FPGA comes up with a base configuration, however without PCIe or UART you can't do any modification or reading out any time (I guess the schematics you are reffering to doesn't have an FPGA UART). I would recommand to continue with the PCIe and the driver.

wlong-coxeve, 2021-12-09:
I am so&nbsp; glad to receive your replay!&nbsp; Thank you!&nbsp; lol !!!
Q1: Solved;
Q2:
The first step I only testing the basic features of FPGA, 10MHz and PPS，so that insure&nbsp; my own PCB has not faulty. But there is no PPS output, so i think whether i need to further programming the GNSS (or something) according to the README.

Q3: Solved;

---Original---
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

thschaub, 2021-12-10:
**Q2:** Theoretically you should see a PPS even without a GNSS module. By default on ANT4 the PPS of the Local Clock from the PPS master is selected.
Additionally you can maybe check some status on the LEDs. On LED3 you should get also a PPS. They have following mapping (Readme.pdf is updated with this information):
LED1: Alive LED of the FPGA internal Clock (50MHz) --> This must be blinking!
LED2: Alive LED of the PCIe clocking part (62.5MHz)
LED3: PPS of the FPGA (Time of the Local Clock via PPS Master)
LED4: PPS of the MAC (differential inputs from the MAC via diff-buffer)

wlong-coxeve, 2021-12-10:
> **Q2:** Theoretically you should see a PPS even without a GNSS module. By default on ANT4 the PPS of the Local Clock from the PPS master is selected. Additionally you can maybe check some status on the LEDs. On LED3 you should get also a PPS. They have following mapping (Readme.pdf is updated with this information): LED1: Alive LED of the FPGA internal Clock (50MHz) --> This must be blinking! LED2: Alive LED of the PCIe clocking part (62.5MHz) LED3: PPS of the FPGA (Time of the Local Clock via PPS Master) LED4: PPS of the MAC (differential inputs from the MAC via diff-buffer)

wisxxx, 2021-12-13:
The marked up schematic page 1, to reflect the assembly:

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

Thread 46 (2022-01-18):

FPGA pin assignments for production version

wisxxx, 2022-01-18:
What are the pin assignments for the "Version: 0x8003 (Production Version)" FPGA?

They aren't in "Readme_Production.pdf".

thschaub, 2022-03-10:
It's not planned to have the pin assignment in the "Readme_Production.pdf" and the schematic (and PCB) of this timecard version is currently not published. Therefore no pinout available at the moment.

ahmadexp, 2022-03-16:
@wisxxx, please try to join our upcoming meeting about opening the FPGA code of the time card
https://www.linkedin.com/feed/update/urn:li:activity:6909908144374652929

thschaub, 2023-01-26:
Pinout constraint file for the Open Source Production version is available here:
https://github.com/opencomputeproject/Time-Appliance-Project/blob/master/Time-Card/FPGA/Open-Source/Implementation/Xilinx/TimeCard_Production/Constraints/PinoutConst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

Closed 2023-01-26.

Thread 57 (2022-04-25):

External atomic clock for laptops & such

greereer, 2022-04-25:
How feasible do you think the following is:

An external solution that enables my computer's (a Dell XPS for example) outgoing packets to be timestamped with a very accurate clock however as you know my stock NIC does not support hardware timestamping nor do I have a PCIe slot.

My proposal:

A NIC with hardware time stamping and built in rubidium oscillator connected to my laptop via USB

The outgoing packets are sent to the NIC to be accurately timestamped before being transmitted

More power could be supplied to the external setup by an additional 5v usb connection

Ideally the only thing the computer would need is downloadable drivers to alter the ptp handling of the computer.

It will require a method of detecting and compensating for changes in latency between the NIC and computer caused by for instance using a different length USB cables/setups.

I would really like to further this idea, if you could let me know what you think I would be very grateful.

ahmadexp, 2022-04-25:
The closes to your idea can be found on the following link which was done for the raspberry pi.
https://www.cnx-software.com/2021/08/17/raspberry-pi-4-ieee1588-precision-time-protocol-ptp-with-real-time-hat/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,enable%20measurement%20and%20control%20systems.
Couple that with a time card and you are good to go.
I will be more than happy to learn more about your application.

Closed 2022-04-27.

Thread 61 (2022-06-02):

question How does this interface with pcie?

Nosh-Ware, 2022-06-02:
I was trying to do some research on how to make some diy electronics that use PCIe, and after a fruitless search baring the slot's pinout, I ended up here, being the only relay active project using PCIe (not Mini PCIe). How exactly does this, on the electronic level, interface with PCIe? Is that something documented elsewhere? Is this something I should ask somewhere else?

ahmadexp, 2022-06-20:
If I understood your question correctly, the PCIe interface is via the FPGA and a core from AXI that provides a memory controller. In the Memory controller was have a set of addresses assigned for various things which in turn the Linux driver maps them to the operating system in different forms such of POSIX clock, etc…
The PCIe connection itself is basically made from two pairs of differential signals (one clock and one data for a 1X connection). Please do not hesitate ask further questions and I apologize in advance if I did not get your question right.

Nosh-Ware, 2022-09-08:
Sorry about the long delay here, but yes that was a lot of helpful information, thanks! I do have a few other questions though.

I'm hoping to have some type of microcontroller (preferably an Arduino Uno/ATMega328P, but I can understand if the speeds warrant a more powerful or otherwise different choice) interface with the slot for some datalogging of my own (temperature, humidity, and 6dof sensors, not anything as complex as you have here). I understand how its a lot more reasonable to use USB to do all of this but for the sake of experimentation, lets assume I'm the unreasonable type. Also I do know about some PCI mini slots having a embedded USB interface as well, but I still consider that "cheating".

I was wondering if there's any good resources I missed about how to make a electronic device interface with PCIe that's freely available (ie not requiring me to be hired by a company registered with the people who maintain the standard). Preferably one as simple as possible (I am not necessarily a complete beginner, but something as advanced as this will no doubt still be a lot to figure out).

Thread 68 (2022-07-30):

TimeCard not visible on PCI bus after updating to FPGA rel 10

MaciekMachni, 2022-07-30:
I tried to update my TimeCard to FPGA release 10, but it is not showing on the bus after the update.

### Hardware:
Time Card
Xilinx Platform Cable (Waveshare clone)

### Software
Vivado Lab Edition 2022.1

### Image
Factory_TimeCardProduction.bin release 10

### Steps tested
- upgrade full flash to raw Factory_TimeCardProduction.bin
- Modified original dump and replace content starting @ 0x00400000 with theTimeCardProduction.bin
- Write bitstream directly to the FPGA RAM
- Update using `devlink`

### Result
D14 is constantly lit, and the Time Card does not show on the bus.
trying to upgrade with devlink ends up with: `ptp_ocp 0000:02:00.0: Can't find Flash SPI adapter`

Does this release require some hardware reworks?
dmesg info about my HW:
```
[    4.516617] ptp_ocp 0000:02:00.0: enabling device (0100 -> 0102)
[    4.517114] ptp_ocp 0000:02:00.0: irq 16 out of range, skipping ts4
[    4.526202] ptp_ocp 0000:02:00.0: Version 1.2.0, clock PPS, device ptp0
[    4.526218] ptp_ocp 0000:02:00.0: Time: 1659174202.287690580, in-sync
[    4.526221] ptp_ocp 0000:02:00.0: version 8
[    4.526223] ptp_ocp 0000:02:00.0: regular image, version 8
[    4.526224] ptp_ocp 0000:02:00.0:  GNSS: /dev/ttyS5  @ 115200
[    4.526227] ptp_ocp 0000:02:00.0: GNSS2: /dev/ttyS6  @ 115200
[    4.526229] ptp_ocp 0000:02:00.0:   MAC: /dev/ttyS7  @  57600
[    4.526234] ptp_ocp 0000:02:00.0:  NMEA: /dev/ttyS8  @     -1
[ 2887.195004] ptp_ocp 0000:02:00.0: Can't find Flash SPI adapter
```

MaciekMachni, 2022-07-31:
Using the SOM FPGA fixed the problem.

Closed 2022-07-31.

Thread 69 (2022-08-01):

Is GNSS dependance the mistake? Should part of this include back to basics.  Solar/moon calibration.

oiaohm, 2022-08-01:
https://hackaday.io/project/167202/instructions
Aweigh here was working on calculation current location using sun location.   Of course reverse can be done using sun/moon... to calculate time.

GNSS can be spoofed or jammed.    Local time calculated by sun/moon is a lot harder to jam and can be hard to spoof.

Back to basics of calibrating atomic clock straight from sun/moon.   Yes using GNSS when the signal is good to work out what the local offsets are.

Its just that thing I got thinking this has added atomic clock to fix the issue that GNSS is not dependable.    Reality here GNSS is still not dependable.  This got me thinking is there some other clock source that is dependable.   Then I remembered that our clocks historically were calibrated by sun and the sun and moon and stars... are all still there.

Raspberry pi compute module with like Aweigh module on poe Ethernet cable in a water proof box on roof is possible.   This way if GNSS is jammed or spoofed for a long time atomic clock calibration can be done at-least once per day against the sun.   This could removes the GNSS dependence reducing so making it optional extra.   Dependence comes sun and atomic module.

See my problem here is the time board working around problem that can be avoided.   Time of year and other things are also calculable from sun location in sky to earth position information this could also limit spoofing of GNSS information being able to check against local sun time/data.

I know the sun/moon data will have some error due to how land under our feet slowly moves.

ahmadexp, 2023-08-09:
@oiaohm, sorry for getting back to you after a year. I just noticed this comment and I find it very interesting.
Things that I am not sure about are, the precision you will get form observing the sun and wether it is good enough to be in the useful to discipline an atomic clock. The introduction of VLBI made use find out about leap seconds while before that we had no clue about precisions lower than 10ms per day (this number is just a guess though).
I love to hear more about your thoughts.

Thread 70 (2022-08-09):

Time in GPZDA on the NMEA serial port is incorrect

MaciekMachni, 2022-08-09:
The time reported in the $GPZDA NMEA message on the NMEA serial port is incorrect. It returns GPS time instead of UTC.

The upper part shows the G*ZDA message from the Time Card, while the lower - reported by the UBX module (on the UBX serial port)

```
$GPZDA,144310.00,09,08,2022,00,00*66
$GPZDA,144311.00,09,08,2022,00,00*67
$GPZDA,144312.00,09,08,2022,00,00*64
$GPZDA,144313.00,09,08,2022,00,00*65
$GPZDA,144314.00,09,08,2022,00,00*62
$GPZDA,144315.00,09,08,2022,00,00*63
$GPZDA,144316.00,09,08,2022,00,00*60
$GPZDA,144317.00,09,08,2022,00,00*61
$GPZDA,144318.00,09,08,2022,00,00*6E

───────────────────────────────────────────────────────────────────────────────────
NT����$GNZDA,144155.00,09,08,2022,00,00*7B
MT����$GNZDA,144156.00,09,08,2022,00,00*78
LT����$GNZDA,144157.00,09,08,2022,00,00*79
KT��s�$GNZDA,144158.00,09,08,2022,00,00*76
JT��^$GNZDA,144159.00,09,08,2022,00,00*77
IT��I$GNZDA,144200.00,09,08,2022,00,00*78
HT��3$GNZDA,144201.00,09,08,2022,00,00*79
GT��($GNZDA,144202.00,09,08,2022,00,00*7A
FT���   8$GNZDA,144203.00,09,08,2022,00,00*7B

```

thschaub, 2022-08-09:
Please check the TOD Master Reference Manual:
https://github.com/opencomputeproject/Time-Appliance-Project/blob/master/Time-Card/SOM/FPGA/Doc/Tod_Master_ReferenceManual.pdf

The NMEA Master takes the time from the adjustable clock which is usually TAI (Chapter 2.4). Correction has to be done via the available register (Chapter 3.2.1.5).

@jlemon: Maybe something which could be done directly in the driver?

MaciekMachni, 2022-08-09:
Just note that the difference between the two messages is at -75 seconds, which is more than 2x the current UTC vs. TAI difference. Most likely, the correction is done twice, and we're getting stale messages.

jlemon, 2022-08-09:
The sysfs file utc_tai_offset should apply its correction to the NMEA master, as @thschaub mentioned.  I'd suggest checking that value.

MaciekMachni, 2022-08-09:
Unfortunately, writing to that file has no effect: https://asciinema.org/a/RbQNaJarzDvWflWP3RoE0TDG1
Also, it does not accept negative corrections (which makes sense but prevents testing a workaround).
I'll try to hack the code tomorrow, but the thing that worries me is we get the extra 1 s offset.

MaciekMachni, 2022-08-10:
@thschaub, unfortunately, it's not fixable in the software. The NMEA offset is already set correctly at the ptp_ocp_utc_distribute() function at the driver initialization, but it seems the IP block applies the 37 s correction by default.

I tried setting the bp->nmea_out->adj_sec (which maps to the register you mentioned) to 0, resulting in the 38-second offset in the NMEA received from the Time Card NMEA UART vs. the ZED-F9T UART.

Setting the negative correction in the register results in time reverting to 1980.

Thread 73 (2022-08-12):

ptp_ocp on RPi CM4 doesn't expose NMEA TTY and GNSS TTY

MaciekMachni, 2022-08-12:
The driver loads but fails to allocate interrupts when connecting the TimeCard to the RPi CM4 2GB and 4GB modules.
As a result, no TTY ports are present.
The same card works properly in the x86 platform.
Tested on the in-tree 5.19.0 driver.

```
[    4.278190] ptp_ocp 0000:03:00.0: enabling device (0000 -> 0002)
[    4.279502] ptp_ocp 0000:03:00.0: irq 1 out of range, skipping ts0
[    4.279531] ptp_ocp 0000:03:00.0: irq 2 out of range, skipping ts1
[    4.279546] ptp_ocp 0000:03:00.0: irq 6 out of range, skipping ts2
[    4.279559] ptp_ocp 0000:03:00.0: irq 15 out of range, skipping ts3
[    4.279572] ptp_ocp 0000:03:00.0: irq 16 out of range, skipping ts4
[    4.279693] ptp_ocp 0000:03:00.0: irq 11 out of range, skipping signal_out[0]
[    4.279708] ptp_ocp 0000:03:00.0: irq 12 out of range, skipping signal_out[1]
[    4.279721] ptp_ocp 0000:03:00.0: irq 13 out of range, skipping signal_out[2]
[    4.279733] ptp_ocp 0000:03:00.0: irq 14 out of range, skipping signal_out[3]
[    4.280026] ptp_ocp 0000:03:00.0: irq 7 out of range, skipping i2c_ctrl
[    4.280040] ptp_ocp 0000:03:00.0: irq 3 out of range, skipping gnss_port
[    4.280052] ptp_ocp 0000:03:00.0: irq 4 out of range, skipping gnss2_port
[    4.280064] ptp_ocp 0000:03:00.0: irq 5 out of range, skipping mac_port
[    4.280077] ptp_ocp 0000:03:00.0: irq 10 out of range, skipping nmea_port
[    4.280089] ptp_ocp 0000:03:00.0: irq 9 out of range, skipping spi_flash
[    4.359245] ptp_ocp 0000:03:00.0: Version 1.2.0, clock PPS, device ptp1
[    4.359297] ptp_ocp 0000:03:00.0: Time: 1660295049.472829090, in-sync
```

The CM4s' datasheet states that the module should be able to allocate up to 32 vectors, and the lspci confirms it:
```
03:00.0 Memory controller: Facebook, Inc. Device 0400
        Subsystem: Xilinx Corporation Device 0007
        Flags: bus master, fast devsel, latency 0, IRQ 39
        Memory at 600000000 (32-bit, non-prefetchable) [size=32M]
        Capabilities: [40] Power Management version 3
        Capabilities: [48] MSI: Enable+ Count=1/32 Maskable- 64bit+
        Capabilities: [60] Express Endpoint, MSI 00
        Capabilities: [100] Device Serial Number 00-00-00-00-00-00-00-00
        Kernel driver in use: ptp_ocp
        Kernel modules: ptp_ocp
```

jlemon, 2022-08-16:
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

Unfortunately, the CM4 doesn't support multiple MSI vectors.

MaciekMachni, 2022-08-17:
Hmmm - RPi team claims it supports up to 32 vectors.
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

Although the problem seems to be present in different devices too.
https://forums.raspberrypi.com/viewtopic.php?t=322859

jlemon, 2022-08-17:
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
MSI and MSI-X are different.

MaciekMachni, 2022-08-17:
> On Aug 17, 2022, at 2:42 AM, Maciek Machnikowski ***@***.***> wrote:   Hmmm - RPi team claims it supports up to 32 vectors. Although the problem seems to be present in different devices too. https://forums.raspberrypi.com/viewtopic.php?t=322859
> MSI and MSI-X are different.

I know, and I think this is just a typo, and they meant MSI.
The [pcie-brcmstb.c](https://elixir.bootlin.com/linux/latest/source/drivers/pci/controller/pcie-brcmstb.c) seems to confirm that:
```
#define BRCM_INT_PCI_MSI_NR
#define BRCM_INT_PCI_MSI_LEGACY_NR	8
...
static int brcm_pcie_enable_msi(struct brcm_pcie *pcie)
{
	struct brcm_msi *msi;
	int irq, ret;
	struct device *dev = pcie->dev;

	irq = irq_of_parse_and_map(dev->of_node, 1);
	if (irq <= 0) {
		dev_err(dev, "cannot map MSI interrupt\n");
		return -ENODEV;
	}

	msi = devm_kzalloc(dev, sizeof(struct brcm_msi), GFP_KERNEL);
	if (!msi)
		return -ENOMEM;

	mutex_init(&msi->lock);
	msi->dev = dev;
	msi->base = pcie->base;
	msi->np = pcie->np;
	msi->target_addr = pcie->msi_target_addr;
	msi->irq = irq;
	msi->legacy = pcie->hw_rev < BRCM_PCIE_HW_REV_33;

	/*
	 * Sanity check to make sure that the 'used' bitmap in struct brcm_msi
	 * is large enough.
	 */
	BUILD_BUG_ON(BRCM_INT_PCI_MSI_LEGACY_NR > BRCM_INT_PCI_MSI_NR);

	if (msi->legacy) {
		msi->intr_base = msi->base + PCIE_INTR2_CPU_BASE;
		msi->nr = BRCM_INT_PCI_MSI_LEGACY_NR;
		msi->legacy_shift = 24;
	} else {
		msi->intr_base = msi->base + PCIE_MSI_INTR2_BASE;
		msi->nr = BRCM_INT_PCI_MSI_NR;
		msi->legacy_shift = 0;
	}

	ret = brcm_allocate_domains(msi);
	if (ret)
		return ret;

	irq_set_chained_handler_and_data(msi->irq, brcm_pcie_msi_isr, msi);

	brcm_msi_set_regs(msi);
	pcie->msi = msi;

	return 0;
}
...
static int brcm_msi_alloc(struct brcm_msi *msi)
{
	int hwirq;

	mutex_lock(&msi->lock);
	hwirq = bitmap_find_free_region(msi->used, msi->nr, 0);
	mutex_unlock(&msi->lock);

	return hwirq;
}
```

julianstj1, 2023-01-27:
Since this is an open issue, will comment on my current view of this. We're working on enabling MSI-X in the Time Card as the primary mechanism for interrupts. I'm hoping that once we get that accomplished, this issue will be resolved since it seems RPi CM4 can support a large number of MSI-X interrupts.

vvfedorenko, 2025-01-08:
@MaciekMachni The problem here comes from Linux kernel. It cannot use multiple MSI vectors (not talking about MSI-X) unless HW IOMMU can handle MSI configuration, which is usually part of VT-d specification. AFAIK, RPi4 doesn't have HW IOMMU, thus no way to use TimeCard until MSI-X is properly supported by the firmware

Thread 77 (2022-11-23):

LED driver enable pulled down

wisxxx, 2022-11-23:
Ref: file "Timingcard_PROJECT.pdf", in Time-Card/HW/ECAD/Prototype-V7/ECADv7.7z

The new status LED driver, U6, on sheet 2 of the new schematic has pin 1 ("SDB") pulled to ground through a 100K resistor.

The data sheet description of this pin reads: "Shutdown the chip when pulled low". That would render the driver and LED's useless.

Also, the pulldown is bypass by a 0.1 uF cap. Why?

julianstj1, 2023-01-27:
This is a good catch. I corrected these issues in V8. I'll close this issue after uploading V8, please re-open if there are any other issues. Thank you!

julianstj1, 2023-01-27:
Updated in V8 in Experimental HW folder, will close for now.

Closed 2023-01-27.

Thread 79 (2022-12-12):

locate SMB connector on RCB

wisxxx, 2022-12-12:
File: OCP Receiver Carrier Board Form Factor (In Progress).docx

The SMB connector on the F9T-RCB needs to be dimensioned.  X, Y, and Z of the center (signal) pin should be shown.

wisxxx, 2023-01-27:
Using the RCB-F9T ".stp" file, one can measure relative positions of features on the board.

Relative to the right and bottom edges, the SMB housing (square) is centered at ( 61.38 mm, 19.80 mm ). The center of the cable connector pin is 5.44 mm above the top of the board.

Note that these should be dimensioned from a well-controlled location on the card. The card edges are not.

Any of the mounting holes would work, but the center of J1 may be preferred. This will ease definition of an RCB-F9T footprint for Timecard board design, since J1 mates with a header on the Timecard.

See the comment in "v0.1 draft spec, soliciting feedback" in Time-Card/GNSS/ .

Closed 2023-01-27.

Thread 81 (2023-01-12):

Open source FPGA build fails

wisxxx, 2023-01-12:
After installing Vivado 2019.1 and cloning the time card repository to my local machine, the script "CreateBinariesAll.tcl" fails with this error:
```
ERROR: [BD 41-758] The following clock pins are not connected to a valid clock source:
/TC_PpsSlave_1/SysClk_ClkIn
/TC_PpsSlave_1/SysClkNx_ClkIn

ERROR: [BD 41-1031] Hdl Generation failed for the IP Integrator design C:/Users/wis1/Documents/tc/Time-Appliance-Project/Time-Card/FPGA/Open-Source/Implementation/Xilinx/TimeCard/TimeCard/TimeCard.srcs/sources_1/bd/TimeCard/TimeCard.bd
ERROR: [Vivado 12-4756] Launch of runs aborted due to earlier errors while preparing sub-designs for run execution.

    while executing
"source "$ScriptFolder/CreateBinariesGolden.tcl""
    (file "C:/Users/wis1/Documents/tc/Time-Appliance-Project/Time-Card/FPGA/Open-Source/Implementation/Xilinx/TimeCard/CreateBinariesAll.tcl" line 28)
```

There are warnings in the Tcl console during "CreateProject.tcl", the first of which is:
```
## create_root_design ""
INFO: [IP_Flow 19-5107] Inferred bus interface 'ClkIn0_ClkIn' of definition 'xilinx.com:signal:clock:1.0' (from Xilinx Repository).
INFO: [IP_Flow 19-5107] Inferred bus interface 'ClkIn1_ClkIn' of definition 'xilinx.com:signal:clock:1.0' (from Xilinx Repository).
WARNING: [IP_Flow 19-3153] Bus Interface 'ClkIn0_ClkIn': ASSOCIATED_BUSIF bus parameter is missing.
WARNING: [IP_Flow 19-3153] Bus Interface 'ClkIn1_ClkIn': ASSOCIATED_BUSIF bus parameter is missing.
INFO: [IP_Flow 19-234] Refreshing IP repositories
INFO: [IP_Flow 19-1700] Loaded user IP repository 'c:/Users/wis1/Documents/tc/Time-Appliance-Project/Time-Card/FPGA/Open-Source'.
WARNING: [IP_Flow 19-3656] If you move the project, the path for repository 'c:/Users/wis1/Documents/tc/Time-Appliance-Project/Time-Card/FPGA/Open-Source' may become invalid. A better location for the repository would be in a path adjacent to the project. (Current project location is 'c:/Users/wis1/Documents/tc/Time-Appliance-Project/Time-Card/FPGA/Open-Source/Implementation/Xilinx/TimeCard/TimeCard'.)
WARNING: [BD 41-1731] Type mismatch between connected pins: /BufgMux_IPI_0/ClkOut_ClkOut(undef) and /BufgMux_IPI_2/ClkIn0_ClkIn(clk)
WARNING: [BD 41-1731] Type mismatch between connected pins: /BufgMux_IPI_1/ClkOut_ClkOut(undef) and /BufgMux_IPI_2/ClkIn1_ClkIn(clk)
WARNING: [BD 41-1731] Type mismatch between connected pins: /BufgMux_IPI_2/ClkOut_ClkOut(undef) and /clk_wiz_1/clk_in1(clk)
WARNING: [BD 41-1306] The connection to interface pin /util_ds_buf_1/IBUF_DS_N is being overridden by the user. This pin will not be connected as a part of interface connection CLK_IN_D
    (_repeats 25 times, different instances_)
WARNING: [BD 41-702] Propagation TCL tries to overwrite USER strength parameter S_AXI_SUPPORTS_NARROW_BURST(false) on '/axi_pcie_0' with propagated value(true). Command ignored
```

Subsequently, there are 63 of these warnings(same warning, different blocks and domains):
```
WARNING: [BD 41-927] Following properties on pin /BufgMux_IPI_0/ClkIn0_ClkIn have been updated from connected ip. They may not be synchronized with cell properties. You can set property on pin directly to confirm the value and resolve the warning.
	CLK_DOMAIN=TimeCard_Mhz10ClkSma_ClkIn
```

thschaub, 2023-01-13:
The warnings you have reported are no issue, it just mentioned that there is no BUS assigned to a clock which is in this case correct since there is only a clock mux. Additionally it does not detect the output as a Clk Ouputs but this should be also no issue.

It's more interessting that you have an Tc_PpsSlave_1 instance in your Block Design. The BD tcl only creates only the [Tc_PpsSlave_0](https://github.com/opencomputeproject/Time-Appliance-Project/blob/31ae07f60544251b1d1306149210d0638d4de711/Time-Card/FPGA/Open-Source/Implementation/Xilinx/TimeCard/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):

**The Tc_PpsSlave_1 should not exist.** Have you touched somehow the block design manually? Did you really created the design from scratch? **(Git Cleanup and remove untracked files before call the CreateProject script)**.

There should be no existing Vivado project folder: Time-Appliance-Project\Time-Card\FPGA\Open-Source\Implementation\Xilinx\TimeCard\TimeCard

wisxxx, 2023-01-13:
I did not knowingly touch anything. I’ll re-clone and try again.

Thanks for this and all the other help.

-wis

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

Closed 2023-01-13.

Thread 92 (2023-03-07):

Production Timecard: mismatch between board and FPGA PCIe lane counts

wisxxx, 2023-03-07:
The production board schematic description on sht. 1 says "X4 PCIE TIME CARD", and four lanes are routed between the edge connector and FPGA (schematic and board). However, the production FPGA only uses a single lane. This lane is correctly attached to the TX0 and RX0 pairs in the board design.

It works, no doubt, but there may be missed expectations for new users.

If going to an x4 channel, during FPGA synthesis are the additional pairs guaranteed to go to the pins already connected on the board?

[ from Vivado block diagram ]
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

lasselj, 2023-03-08:
Hi Wis! Nice speaking with you the other day. I think you are doing great work :-)

For the production card I don't really mind. For the "normal" modular Timecard, I think this is cool. Most servers don't have slots smaller than x4 and it lets people add their own logic if they want and use x4. I.e. I don't think we should chop it.

(We chopped the x4 connector to x1 on [this](https://store.timebeat.app/products/timecard-mini-pci-card-adapter) card. I am sending you one when they arrive)

All the best,

Lasse

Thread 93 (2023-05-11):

experimental timecard v9 resistors R2 and R3 have the wrong values

JohnHay, 2023-05-11:
On the PDF of the schematic at least, I cannot check the original.

It looks like R2 and R3 (P5V_MUN_FB) was just copied from R67 and R68 (P3V3_MUN_FB). From the datasheet, the value for R2 and R3 combined should be 147k for 5V output.

JohnHay, 2023-07-08:
The BOM has now been fixed, but the PDF version of the schematic has not.

Closed 2023-07-08.

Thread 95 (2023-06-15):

Loading driver cause system crash on version of Beta-V1

Satoshier, 2023-06-15:
I am using the PCB version is Beta -V1.

When I reflash Factory_TimeCardOS.bin file from \Time-Appliance-Project-master\Time-Card\FPGA\Open-Source\Implementation\Xilinx\TimeCard\Binaries and executing modprobe, then system gets crashed, only reboot.
(BTW, I don't make any changes on Vivado project)

Then I reflash Factory_TimeCard.bin file from \SOM\FPGA\Binaries and it works well.

It looks very wired, that is why?
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

If I only reflash from SOM folder, I can not make any changes on Vivado, it will be lost funny.

thschaub, 2023-06-23:
I can't reproduce your reported issue with the latest open-source version. Do you restart the PC after programming the SPI flash (cold start/complete power down)?

chaloz, 2023-09-21:
> I can't reproduce your reported issue with the latest open-source version. Do you restart the PC after programming the SPI flash (cold start/complete power down)?

I could reproduce this with CentOS, kernel 6.4, and Vivado 2023.1 (Vivado v2023.1 (64-bit) SW Build: 3865809 on Sun May 7 15:04:56 MDT 2023 IP Build: 3864474 on Sun May 7 20:36:21 MDT 2023 SharedData Build: 3865790 on Sun May 07 13:33:03 MDT 2023). SOM image works, image built with Open-Source implementation does not.

Similar with Ubuntu (Linux ocp 6.5.3 #1 SMP PREEMPT_DYNAMIC Mon Sep 18 10:41:37 IST 2023 x86_64 x86_64 x86_64 GNU/Linux) SOM image works, but Open-Source image built with Vivado 2023.1 does not. Kernel does not crash though, and I can see the following with lspcie:
```
18:00.0 Memory controller: Facebook, Inc. Device 0401                                                                                  
        Subsystem: Xilinx Corporation Device 0007                                                                                      
        Physical Slot: 1-1                                     
        Flags: bus master, fast devsel, latency 0                                                                                      
        Memory at f0000000 (32-bit, non-prefetchable) [size=32M]                                                                       
        Capabilities: [40] Power Management version 3                                                                                  
        Capabilities: [48] MSI: Enable- Count=1/32 Maskable- 64bit+                                                                    
        Capabilities: [60] Express Endpoint, MSI 00                                                                                    
        Capabilities: [100] Device Serial Number 00-00-00-00-00-00-00-00
```
Note that I have changed Device ID to 0x0401 to be sure my image is loaded. With SOM image the lspcie shows:

```
        18:00.0 Memory controller: Facebook, Inc. Device 0400
        Subsystem: Xilinx Corporation Device 0007
        Physical Slot: 1-1
        Flags: bus master, fast devsel, latency 0, IRQ 32
        Memory at f0000000 (32-bit, non-prefetchable) [size=32M]
        Capabilities: [40] Power Management version 3
        Capabilities: [48] MSI: Enable+ Count=1/32 Maskable- 64bit+
        Capabilities: [60] Express Endpoint, MSI 00
        Capabilities: [100] Device Serial Number 00-00-00-00-00-00-00-00
        Kernel driver in use: ptp_ocp
        Kernel modules: ptp_ocp"
```
Clearly MSI is somehow disabled for Open-Source version.

Can someone please explain what is the main difference between SOM version and the Open-Source version? Mainly any difference in the PCIe MSI settings?

thschaub, 2023-09-21:
Yeah, well the with the Device ID 0x0401 the ptp_ocp driver is not loaded and the interrupts are not enabled.

Why do you have 0x0401 as device id? Did you changed it manually?

In the TCL script which creates the PCIe config it's not like that:
https://github.com/opencomputeproject/Time-Appliance-Project/blob/b22096f427e6ec01ff5e1c719547a2e447580aaf/Time-Card/FPGA/Open-Source/Implementation/Xilinx/TimeCard/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

I guess the crash has maybe something to do with the driver and already pending interrupts or similar.
Do you see any interrupts on the SOM version?

There are some small differences with the available modules and possible interrupt sources in the SOM and Open-Source version. PCIe config is the same.

chaloz, 2023-09-21:
Thanks @thschaub for such a quick reply. Yeah, I've changed the Device ID to 0x0401 just to see that I have successfully loaded the new bit file. Thanks for pointing out that driver needs to have the ID changed accordingly. Now the card is visible with lspcie.

Another issue, same to #73 is that the driver only gets allocated 1 MSI IRQ. @thschaub would you be able to tell what might be the issue and/or where to look? I have this behaviour with SOM and also clean Open-Source compiled bit stream.

lspcie shows that 32 MSIs are enabled (see below), but driver only gets one IRQ after calling ```pci_alloc_irq_vectors```
```
Capabilities: [48] MSI: Enable+ Count=1/32 Maskable- 64bit+
```

JohnHay, 2023-09-21:
I'm not sure if I should start a different issue.

I have a v8 card and if I boot with a usb flash with ubuntu-23.04-live-server-amd64.iso with the closed TimeCard.bin firmware, it will boot ok, but if I load the TimeCardOS.bin firmware, the kernel will panic.

In both cases, I did a cold boot after changing the firmware. I have not tried other linux versions. Here is a screenshot of the panic. I tried a few times and it paniced every time.

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

I only have a single GNSS installed, if that makes a difference.

I'm actually trying to write a FreeBSD driver for the card, but am a bit stuck with the MSI interrupts causing panics there, so I thought to check how linux was doing. I started with the OS version, which paniced, and I thought I had a smoking gun, but then linux did not panic with the SOM version. My FreeBSD code panic with both, but it is probably something I do wrong. :-)

Any suggestions on debugging MSI interrupts on the TimeCard would be useful.

@chaloz while searching I saw that for more than one MSI interrupt on linux, you need a kernel option CONFIG_IRQ_REMAP.

chaloz, 2023-09-21:
@JohnHay Thanks for the tip, I think I have this option enabled:
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

@JohnHay I am no expert on kernel drivers, but what I would suggest is to start with only one interrupt being enabled by the driver, and go on from there. If it works with a single interrupt, enable two and so on.

The line where you enable interrupts is here: https://github.com/opencomputeproject/Time-Appliance-Project/blob/b22096f427e6ec01ff5e1c719547a2e447580aaf/Time-Card/DRV/ptp_ocp.c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
So force `err = 1;` after the line above.

JohnHay, 2023-09-22:
@thschaub are the MsiIrq Ips the same for the SOM and Open-Source version?

I had a look at the Open-Source MsiIrq.vhd and noticed that MsiVectorWidth_DatIn is not being used, so I was wondering how the interaction with the PCIe would be in the case where the OS sets only 1 interrupt. Like we see in @chaloz example and I have also seen when booting with ubuntu and the SOM firmware.

In the AXI PCIe documentation I found (DS820 April 24, 2012), in the MSI Interrupt section there is a sentence:
`The bridge ignores any bits set on the MSI_Vector_Num input signal, if they are not allocated in the Message Control Register.`

I'm not sure if that refers to the capability part of that register or the part where the OS sets the number of vectors it allows/allocated. Would that mean if MsiIrq still sends all the vectors, just their lowest bit will be used? So will all the even vectors cause the same interrupt? What will then happen to the odd numbered ones?

Is there a way for the driver to determine if there are pending interrupts before enabling it, other than going through each function on the card?

JohnHay, 2023-09-23:
I made some progress, but still have some questions.  I followed @chaloz's suggestion and made a stripped down driver that only allocated a single msi interrupt with a handler that does nothing. That did not panic, but I found that it was getting 1.5M interrupts per second. That was with a cold booted system and the driver did nothing on the card. So I wrote a program that read and displayed the interrupt enable registers of all the functions on the card. Nothing was enabled. I tried it with both the SOM and Open-Source firmware and they behaved the same.
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
chaloz, 2023-09-24:
@JohnHay, great to see you're making progress. Without seeing your code anything I recommend is just a shot in the dark, but here we go: are you clearing the interrupts in the interrupt handler?

Like so: https://github.com/opencomputeproject/Time-Appliance-Project/blob/b22096f427e6ec01ff5e1c719547a2e447580aaf/Time-Card/DRV/ptp_ocp.c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

JohnHay, 2023-09-25:
@chaloz, I made a lot of progress. I found the source of the interrupts. There are 2 unused interrupts (17 and 18) on the board. In TimeCardBd.tcl they are connected to xlconstant_5_dout, but xlconstant_5 is defined without giving it a value, so its default is 1. If they were edge interrupts, that would only cause 2 interrupts, but also in TimeCardBd.tcl, they are defined as level interrupts with this bitmask:
`CONFIG.LevelInterrupt_Gen {0x000E05B8}`

@thschaub can xlconstant_5 not just be removed and TC_MsiIrq_0/IrqIn17_DatIn and TC_MsiIrq_0/IrqIn18_DatIn be left open? Looking at the MsiIrq code, it will use a 0 for IrqIn pins that are not connected.

Also should the level mask not be changed to 0x000805B8, ie. clearing bits 17 and 18? That seems safer, except if you already know what irq 17 and 18 will be used for in the future, or is there another reason to keep them as level interrupts?

The last part of the puzzle (for now) was the panics in FreeBSD. I found that there is a mistake in the function native_apic_alloc_vectors() that did not align it on a 32 boundary, but only on a 16 boundary. So msi allocations up to 16 were fine. If you allocate 32 msi vectors and they are not aligned, the axi pcie blob will just ignore the lower 5 bits and write over it. In my case the vector received from the OS was 0x50, so the axi pcie would ignore bit 4 and create vectors from 0x40 to 0x5f. The interrupts outside of the range caused the panics. The axi pcie implementation is correct though, because the pci spec says that the vector has to be aligned to the number of bits that are requested.

So now I can return to the driver I'm busy with. :-)

thschaub, 2023-09-25:
@JohnHay

Good catch, the xlconstant_5 should be definitly '0'. The reason why we have not left them open and we have a defined mask is because on a special HW revision (production version) where this IRQs are used:
https://github.com/opencomputeproject/Time-Appliance-Project/tree/master/Time-Card/FPGA/Open-Source/Implementation/Xilinx/TimeCard_Production

Left open is also somehow undefined, but driving it with a constant allows to optimize the logic. So left something open is usually not the proper way in VHDL.

I will inform you once this bug is fixed.

thschaub, 2023-10-06:
@JohnHay

Constant value correctly defined in the updated BD.tcl scripts.
You can find the update in following commit: https://github.com/opencomputeproject/Time-Appliance-Project/commit/a330ec4c33a1a760dd3cbf221079e561027fcce5

Closed 2023-10-06.

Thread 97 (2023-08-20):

wrong UTC Offset to TAI during startup with NEO-M9N

JohnHay, 2023-08-20:
I'm using the NEO-M9N board on a v8 card. I have tried both the closed source (0x1A) and OS (0x06) FPGA firmware. The M9N is configured for 115k baud and UBX output (NAV_TIME_UTC, NAV_TIME_LS, NAV_STATUS, MON_HW and NAV_SAT).

During the first few minutes after a cold boot the Tod SlaveUtcStatus register will often go to:
0x10133 (51s UTC to TAI)
0x10112 (18s UTC to TAI)

before settling on:
0x10125 (37s UTC to TAI)

It looks like the M9N will always/mostly report the currLs as 0x12 (18 decimal) even when the srcOfCurrLs is
1 (Glonass)
2 (GPS)
4 (Beidou)
5 (Galileo)
7 (Configured)
255 (Unknown)

It looks like the code in TodSlave.vhd expects currLs to be different for different values of srcOfCurrLs, but that is not the case NEO-M9N firmware (protocol version 32.01).

It is only a "problem" during startup, but it can last for quite a few minutes, but during that time the UTC_INFO_VALID bit (8) is set, so the clock is set.

Attached is the capture of the NAV_TIME_LS messages during 2 cold starts.
[ubx-out-ls.txt](https://github.com/opencomputeproject/Time-Appliance-Project/files/12388626/ubx-out-ls.txt)

PS. Is there a reason the OS firmware does not also default to UBX and 115k baud, like the the closed firmware? It defaults to NMEA and 19k baud.

Regards

John

JohnHay, 2023-08-21:
Here is the output reading the TimeCard registers once a second during a coldstart. The lines have a timestamp of the card, the OS, and some of the status registers.

In this case the UTC-TAI went through 37,18,37,51,37.

[tc4-tai.txt](https://github.com/opencomputeproject/Time-Appliance-Project/files/12392624/tc4-tai.txt)

JohnHay, 2023-08-29:
Maybe I should ask it in another way.

Can anyone with a Ublox GNSS receiver other than a M9N check if it ever has a value other than 18 in currLs of the UBX-NAV-TIMELS message? (While validCurrLs is set.) During a cold boot or whenever it has not locked onto the GPS constellation yet, so the srcOfCurrLs is set to something other than GPS(2). (Say on a ZED-F9T for instance. )

I had a look at the documentation for both the M9N and F9T. For both in the UBX-NAV-TIMELS section (M9-SPG 3.15.19, and ZED-F9T-10B 3.15.21), the description of the CurrLs field is:

`Current number of leap seconds since start of GPS
time (Jan 6, 1980). It reﬂects how much GPS time is
ahead of UTC time. Galileo number of leap seconds is
the same as GPS. BeiDou number of leap seconds is 14
less than GPS. GLONASS follows UTC time, so no leap
seconds.`

The way I read it is that CurrLs = GPS - UTC
They say GPS and not GNSS or the one that is currently srcOfCurrLs. They then go on to describe the relationship of the other time bases, but that is extra information and they do not say those will ever be put in CurrLs.

Regards

John

lasselj, 2023-08-29:
Hi John,

I would like to help you, and I am writing UBX code right now for the LEA-M8F and the MAX-M10S in addition to the NEO-M9N so I am ideally placed to do so, but can I ask first please:

- We assume that any receiver will lie, cheat and steal before an “A” has been observed in a <talkerid>RMC line (btw… what engineer came up with V indicating invalid… haha?) - why don’t you make the same assumption?
- It’s a PCIe card in a PC, by the time my application is ready to interact with the the GNSS module it is long since started, so how can I test what you are asking? Why do you care about this value only at startup?

In any event, if you want, I can test with the two module also listed above. In the instance, can you describe in significant detail (UBX instructions you issue for the NAV stuff) the exact steps to reproduce this problem please?

All the best,

Lasse

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

JohnHay, 2023-08-29:
Hi Lasse,

For the TimeCard, the firmware on the FPGA implement a counter that is synchronized to TAI by the TOD (Time of Day) module also on the the FPGA. The TOD module listens the GNSS receiver and parse the messages. The message used to find the TAI offset is the UBX-NAV-TIMELS message. To determine TAI, 3 fields in the message is used, `validCurrLs` that is 1 when the other fields are valid, `currLs` the number of leap seconds, and `srcOfCurrLs` that indicate the source of the information.

The firmware code to implement this is in this [block](https://github.com/opencomputeproject/Time-Appliance-Project/blob/70fb2358f7fd5f4481496cdd6a5892b8d3924a8d/Time-Card/FPGA/Open-Source/Ips/TodSlave/TodSlave.vhd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).

What I observed was that during the first 10-12 minutes after power on, the clock would jump around, like I explained in the 1st and 2nd messages. So I used ubxtool to look at the UBX-NAV-TIMELS messages and saw that the `currLs` field stayed 18 the whole time, but `srcOfCurrLs` changed as it searched the sky and found different GNSS constellations, until it finally synced to GPS. Time jumps happened even after the `validCurrLs` bit was set. The current offset between UTC and GPS time is 18 seconds. GPS time is fixed at 19 seconds ahead of TAI, so TAI to UTC is 37 seconds.

Looking at the code in the above link, I noticed that depending on the value of `srcOfCurrLs`, different values are added to `currLs` to calculate the TAI-UTC offset. But for the M9Ns I have, that is wrong because they always report 18 not matter what their `srcOfCurrLs` value at that stage.

So what I'm trying to find out, is if the firmware was written with the wrong assumption or if different Ublox receivers/firmware  differ in how they fill `currLs` in.

To test, you can disable the NMEA messages and enable UBX-NAV-TIMELS and then do a cold boot and capture the messages. With ubxtool I enabled it with `-z CFG-MSGOUT-UBX_NAV_TIMELS_UART1,1`.

Regards

John

JohnHay, 2023-08-30:
@julianstj1 I see you committed test scripts recently that check for the TIMELS message. Any chance that you could capture the TIMELS mesages for the first 10-12 minutes after the cold boot of one of the GNSS receivers?

While I focused on the startup where I saw the TAI jumps, one could also see it later if ever the GPS constellation is not available, while some of the other GNSS constellations are. While unlikely, it could occur because of jamming or whatever.

JohnHay, 2023-08-31:
Hi Julian, currently it looks like the TIMELS message M9N receivers sends, fill the currLs field differently from what the Xilinx firmware expects. What I'm trying to find out is how other ublox receivers does it, so that we can determine if the M9N is an exception or if the Xilinx firmware needs to change for all of them.

Unfortunately I only have M9Ns. For me the easiest was to force a cold boot of the receiver and log all the TIMELS messages and then look through the ones where validCurrLs is set. On the M9N receivers (with the SPG 4.04 firmware they came with) currLs is always 18 and it does not matter what srcOfCurrLs is set to.

To calculate TAI the Xilinx firmware [in this section](https://github.com/opencomputeproject/Time-Appliance-Project/blob/70fb2358f7fd5f4481496cdd6a5892b8d3924a8d/Time-Card/FPGA/Open-Source/Ips/TodSlave/TodSlave.vhd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) will add different values depending on what srcOfCurrLs is. When using a M9N receiver that makes the  TAI offset register and the clock counter jump around.
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
thschaub, 2023-09-13:
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

Hi John,

thanks for this good catch. The sentence above about the CurrLs was a bit misleading. You are right it never goes into CurrLs. I have quickly checked it when modules (F9T and the M9N) uses only Beidou.

```
09:08:34  0000  B5 62 01 26 18 00 A0 94 69 11 00 00 00 00 04 12  µb.&.. .i.......
          0010  04 00 6E 4A A1 FC 89 08 07 00 00 00 00 03 F7 F4  ..nJ¡ü........÷ô.
```
CurrLs is always 12s. We will provide a fix.

Thanks again
Thomas

JohnHay, 2023-09-13:
Hi Thomas,

Thank you.

Regards

John

thschaub, 2023-10-06:
You can find the fixed UTC correction for BeiDou in the following commit: https://github.com/opencomputeproject/Time-Appliance-Project/commit/a330ec4c33a1a760dd3cbf221079e561027fcce5

SOM version not fixed yet.

JohnHay, 2023-10-06:
Thank you.

JohnHay, 2023-10-06:
Hi @thschaub, is the else case really correct? It seems like currLs is always the number of leap seconds since the start of GPS time.

        if ((UtcOffsetInfo_DatReg.SrcOfCurLeapSecond = x"01") or (UtcOffsetInfo_DatReg.SrcOfCurLeapSecond = x"02") or (UtcOffsetInfo_DatReg.SrcOfCurLeapSecond = x"04") or (UtcOffsetInfo_DatReg.SrcOfCurLeapSecond = x"05")) then -- GPS, or derived from dif GPS to Glonass, or Beidou or Galileo
            UtcOffsetInfo_DatReg.CurrentUtcOffset <= std_logic_vector(unsigned(MsgData_DatReg) + 19); -- add the GPS-TAI offset to UTC-GPS offset
            UtcOffsetInfo_DatReg.CurrentTaiGnssOffset <= std_logic_vector(unsigned(MsgData_DatReg) + 19); -- add the GPS-TAI offset to UTC-GPS offset
        else -- else assume that the utc offset is provided directly
            UtcOffsetInfo_DatReg.CurrentUtcOffset <= MsgData_DatReg;
            UtcOffsetInfo_DatReg.CurrentTaiGnssOffset <= MsgData_DatReg;
        end if;

The M9N's that I have report 18 (0x12) for currLs even when srcOfCurrLs is 7 (Configured) and 255 (Unknown) during a cold start. That is without me setting it, so it comes from the firmware settings. Their validCurrLs bit is not set srcOfCurrLs is 7, but it was set when it was 255, but it does seem that the whole "if else end if" can be replaced with just adding 19 to the currLs value:

```
UtcOffsetInfo_DatReg.CurrentUtcOffset <= std_logic_vector(unsigned(MsgData_DatReg) + 19); -- add the GPS-TAI offset to UTC-GPS offset
UtcOffsetInfo_DatReg.CurrentTaiGnssOffset <= std_logic_vector(unsigned(MsgData_DatReg) + 19); -- add the GPS-TAI offset to UTC-GPS offset
```

You can look at the TIMELS bytes captured in the file [ubx-out-ls.txt](https://github.com/opencomputeproject/Time-Appliance-Project/files/12388626/ubx-out-ls.txt) in my first post. On the lines, byte 14 is srcOfCurrLs, byte 15 is currLs, and byte 29 is where the valid flags are. The last 2 bytes are the checksum.

Or is there a case when that is not correct?

Regards

John

thschaub, 2023-10-10:
Hi @JohnHay

Sorry, I didn't checked the point about srfOfCurrLs = 255 which seems to be a valid leap second value according to that what the M9N is reporting. 255 seems to be somehow a transient state, I am not sure what is the best approach.

I see following options:
- Instead of just taking the value as it is when non of the if statements is matching, it might be better to retain the previous value in the else, so basically remove the else.
- Take 255 (Unknown) as a valid value and add it as an possible if which matched ans keep the else as it is

Byte 29 = 1 is already a valid for the currLs which seems to be set in you case as well when srcOfCurrLs =1

thschaub, 2023-10-10:
Reading the datasheet I have in general the feeling all values except 0, are valid sources for CurrLs. So maybe we should be not picky and take them all to update the Offsets. The valid is treated anyway independently.

JohnHay, 2023-10-10:
That is also the conclusion I came to after reading the datasheets and looking at the output of the M9Ns I have.

thschaub, 2023-10-11:
Now also 255 is taken as a valid source. Additionally, if the source is non of the matching ones, the last valid value is retained.
The valid is still handled as before, so directly taken from the receiver.
https://github.com/opencomputeproject/Time-Appliance-Project/commit/fbf97469ea892694f82ad5cbba23b8f2b5b34aa2

JohnHay, 2023-10-13:
Thanks, so far it looks good.

JohnHay, 2023-10-15:
It took some time and few tries before I got the srfOfCurrLs to go:
Configured(7), Glonass(1), Unknown(255), Galileo(5) and then GPS(2).
The validCurrLs flag was set from Glonass and there were no jumps in time.

I'm happy, thank you!

Closed 2023-10-15.

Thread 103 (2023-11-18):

in CoreListFile.txt the high address of the AXI IIC CLOCK lines are wrong

JohnHay, 2023-11-18:
The HighRangAddress of the AXI IIC CLOCK lines are wrong. It is 00120FFF, but that is lower than the Low address. I guess it should be 0020FFFF to match the size of the other IIC lines.

```
grep 'AXI IIC CLOCK' */CoreListFile.txt
TimeCard/CoreListFile.txt:00010002 00000001 02000000 00200000 00120FFF 00000005 00000003 Xilinx AXI IIC CLOCK
TimeCard_200T/CoreListFile.txt:00010002 00000001 02000000 00200000 00120FFF 00000005 00000003 Xilinx AXI IIC CLOCK
TimeCard_LitePcie/CoreListFile.txt:00010002 00000001 02000000 00200000 00120FFF 00000005 00000003 Xilinx AXI IIC CLOCK

```

thschaub, 2023-11-21:
Finally, someone starts using the CoreList :-)
It's fixed in a903680d5155aa2600549b9dd2f26e3a086021e7

JohnHay, 2023-11-21:
Thank you. :-)

I'm using it in the FreeBSD driver I'm busy with. I also have it working with the LitePCIe firmware. Adding support for that also made me wonder what the better or more future proof way would be for a driver to distinguish between the different firmware versions. But maybe that should be done in a separate issue.

JohnHay, 2023-11-22:
BTW It looks like the LitePcie TimeCardOS.bit was missed in the update.

thschaub, 2023-11-22:
True, was missing in my release script. Here it is: a4c9739f0526f57c70bb10ad354221c180ab9b50

thschaub, 2023-11-22:
> Thank you. :-)
>
> I'm using it in the FreeBSD driver I'm busy with. I also have it working with the LitePCIe firmware. Adding support for that also made me wonder what the better or more future proof way would be for a driver to distinguish between the different firmware versions. But maybe that should be done in a separate issue.

The idea is to allow a modular driver. So read out from the CoreList and initialize the driver accordingly with the how many time stampers etc. are instantiated. Of course beside Vendor and Device IDs it could also be used to distinguish between the versions. So feel free to contribute into this direction :)

JohnHay, 2023-11-23:
I agree with the modular driver approach. But for that you need to get to the CoreList. :-) So my current understanding is roughly this:

All the cards have a firmware version at offset 0x20000.
All the Open Source versions have a CoreList at offset 0x01300000.
The LitePcie versions offset everything with 32M, including the above. (except the irq mask)
The pre-LitePcie firmware has msi interrupts, while the LitePcie has msi-x and a mask register.
For msi interrupts 1 has to be added to the irq in the CoreList to get the vector offset.
For msi-x interrupts another 32 has to be added to get the vector offset. The CoreList irq value is used as a bit index in the irq enable/mask register.

The way I currently approach it, is something like this:
Determine if it is LitePcie based firmware by reading at offset 0x20000. If that is 0xffffffff, add 32M and try again. If it is still 0xffffffff, give up. If it is not, add 32M to all future offsets.
Determine if there is a CoreList by reading at offset 0x01300000. If that is 0xffffffff, assume it is a closed source firmware and use a hardcoded table, else read the CoreList and use that.
Determine msi-x/msi by calling the operating system msi-x initialization function. If that fails, try the msi function.

I have this working, although I have not gone back to previous firmware versions to see that I did not break anything. :-)

I guess I just wanted to check if this way have obvious holes or if there is a more robust way, especially if there are already plans for other changes. And also while there is documentation for each firmware stream, I have not found something that describe the differences that can be used by software to add support for multiple versions.

JohnHay, 2023-12-21:
One thing I noticed in the updated linux driver is that the PCI_REVISION_ID can be used to distinguish between the LitePCIe and non-LitePCIe firmware. That is a cleaner way than reading at the firmware version offset (0x20000) and knowing it is LitePCIe based because you read 0xffffffff.

Is there a cleaner way to determine if the firmware has a CoreList than just reading at the offset and knowing there isn't one because 0xffffffff was returned?

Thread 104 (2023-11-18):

Should the version numbers in the CoreList be the same as the version registers?

JohnHay, 2023-11-18:
Should the version number in the CoreList match the number in the Version register of that core? There are some that are different.

```
timecard0: CoreList 0x10000, register 0x10001, TC SMA Selector Inst0 Slave1
timecard0: CoreList  0x10000, register 0x10001, TC SMA Selector Inst0 Slave2
timecard0: CoreList  0x20001, register 0x20002, TC ToD Slave
```

I looks like TodSlave.vhd has a different version number (0x20003) from the above 2 ToD version numbers:
```
constant TodSlaveMajorVersion_Con               : std_logic_vector(7 downto 0) := std_logic_vector(to_unsigned(0, 8));
constant TodSlaveMinorVersion_Con               : std_logic_vector(7 downto 0) := std_logic_vector(to_unsigned(2, 8));
constant TodSlaveBuildVersion_Con               : std_logic_vector(15 downto 0) := std_logic_vector(to_unsigned(3, 16));
```

thschaub, 2023-11-21:
Yes, that's the idea but at the moment it's manual work and therefore the potential high to miss the update in the CoreList as well.
It's fixed in a903680d5155aa2600549b9dd2f26e3a086021e7

JohnHay, 2023-11-21:
Thank you. :-)

Currently my driver compare them in the attach routine and print a message to the console if there is a difference.

JohnHay, 2023-11-23:
I have now loaded the version 9 LitePcie firmware and still see a version mismatch on the SMA Selector. It is not an issue for me, so you do not have to bring out a new version just for that. I just thought I'll mention it for when you next bring out a new version:

```
timecard0: CoreList 0x10000, register 0x10001, TC SMA Selector Inst0 Slave1
timecard0: CoreList 0x10000, register 0x10001, TC SMA Selector Inst0 Slave2
```

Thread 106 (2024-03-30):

Could not find device ttySX

SfCal, 2024-03-30:
I'm experiencing issues as I'm following along the Time Card installation and usage guide.

OS: Ubuntu 22.04.4 LTS x86_64
Host: NUC9VXQNX K47173-402
Kernel: 5.15.0-101-generic

Being on Ubuntu 22.04.4 I went straight to step 11 and made sure the driver was up to date.

I'm a bit concerned about missing NMEA in dmesg here

```
[    0.486218] pci 0000:02:00.0: [1d9b:0400] type 00 class 0x058000
[    0.486242] pci 0000:02:00.0: reg 0x10: [mem 0x90000000-0x91ffffff]
[    0.602696] pci 0000:02:00.0: Adding to iommu group 1
[    5.205701] ptp_ocp 0000:02:00.0: enabling device (0000 -> 0002)
[    5.207805] 0000:02:00.0: ttyS5 at MMIO 0x90161000 (irq = 175, base_baud = 3125000) is a 16550A
[    5.210203] 0000:02:00.0: ttyS6 at MMIO 0x90181000 (irq = 177, base_baud = 3125000) is a 16550A
[    5.212064] ptp_ocp 0000:02:00.0: Time: 1711770702.739673435, UNSYNCED
[    5.212124] ptp_ocp 0000:02:00.0: Version 1.2.0, clock PPS, device ptp3
[    5.212128] ptp_ocp 0000:02:00.0: TOD Version 2.2.1
[    5.212135] ptp_ocp 0000:02:00.0: control: 10000001
[    5.212137] ptp_ocp 0000:02:00.0: TOD Protocol UBX enabled
[    5.212138] ptp_ocp 0000:02:00.0: GNSS ALL
[    5.212142] ptp_ocp 0000:02:00.0: status: 0
[    5.212146] ptp_ocp 0000:02:00.0: correction: 0
[    5.212149] ptp_ocp 0000:02:00.0: utc_status: 0
[    5.212150] ptp_ocp 0000:02:00.0: utc_offset: 0  valid:0  leap_valid:0
[    5.212154] ptp_ocp 0000:02:00.0: version 1a
[    5.212155] ptp_ocp 0000:02:00.0: regular image, version 26
[    5.212156] ptp_ocp 0000:02:00.0: GNSS @ /dev/ttyS5 115200
[    5.212157] ptp_ocp 0000:02:00.0: MAC @ /dev/ttyS6   57600
```

Here's the output from cgps
```
lqqqqqqqqqqqqqqqqqqqqqqqqqqqqqqqqqqqqqqqqqqqklqqqqqqqqqqqqqqqqqqSeen  0/Used  0k
x Time:          n/a (0)                    xxGNSS   PRN  Elev   Azim   SNR Usex
x Latitude:        n/a                      xx                                 x
x Longitude:       n/a                      xx                                 x
x Alt (HAE, MSL):        n/a,       n/a     xx                                 x
x Speed:           n/a                      xx                                 x
x Track (true, var):                n/a deg xx                                 x
x Climb:           n/a                      xx                                 x
x Status:         NO FIX (0 secs)           xx                                 x
x Long Err  (XDOP, EPX):  n/a ,  n/a        xx                                 x
x Lat Err   (YDOP, EPY):  n/a ,  n/a        xx                                 x
x Alt Err   (VDOP, EPV):  n/a ,  n/a        xx                                 x
x 2D Err    (HDOP, CEP):  n/a ,  n/a        xx                                 x
x 3D Err    (PDOP, SEP):  n/a ,  n/a        xx                                 x
x Time Err  (TDOP):       n/a               xx                                 x
x Geo Err   (GDOP):       n/a               xx                                 x
x ECEF X, VX:              n/a    n/a       xx                                 x
x ECEF Y, VY:              n/a    n/a       xx                                 x
x ECEF Z, VZ:              n/a    n/a       xx                                 x
x Speed Err (EPS):        n/a               xx                                 x
x Track Err (EPD):        n/a               xx                                 x
x Time offset:            n/a               xx                                 x
x Grid Square:            n/a               xx                                 x
mqqqqqqqqqqqqqqqqqqqqqqqqqqqqqqqqqqqqqqqqqqqjmqqqqqqqqqqqqqqqqqqqqqqqqqqqqqqqqqj

{"class":"VERSION","release":"3.22","rev":"3.22","proto_major":3,"proto_minor":14}
{"class":"DEVICES","devices":[]}
{"class":"WATCH","enable":true,"json":true,"nmea":false,"raw":0,"scaled":false,"timing":false,"split24":false,"pps":false}
```

I didn't feel confident that I understood how to use gpsd correctly so I also confirmed with pygpsclient below. I am getting data from ttyS5 and it seems correct.

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

I purchased the Time Card from Makerfab and used a NUC 9 Pro because it was within the supported systems list. I didn't see any recommendation for a specific GPS receiver so I found a generic one on amazon this one [specifically.](https://www.amazon.com/dp/B07R7RC96G?ref=ppx_yo2ov_dt_b_product_details) It is outside so it has LOS to the sky. Curious what I may be missing here.

SfCal, 2024-04-04:
Wanted to leave an update, switched over to a desktop system I had:

OS: Pop!_OS 22.04 LTS x86_64
Host: Z690 UD AX DDR4
Kernel: 6.8.0-76060800daily20240311-generic

I was able to get gpsd working, I was unable to use the command `gpsd /dev/ttyS5` to set the device and had to instead edit it directly from `/etc/default/gpsd` and restart the service.

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

Curiously, I am getting `Could not find device ttySX` but each device appears to be working as expected. Will attempt BIOS update on NUC later.

```
[    1.194851] pci 0000:06:00.0: [1d9b:0400] type 00 class 0x058000 PCIe Endpoint
[    1.194878] pci 0000:06:00.0: BAR 0 [mem 0x42000000-0x43ffffff]
[    1.194972] pci 0000:06:00.0: enabling Extended Tags
[    1.254669] pci 0000:06:00.0: Adding to iommu group 19
[    7.633255] ptp_ocp 0000:06:00.0: enabling device (0000 -> 0002)
[    7.660873] 0000:06:00.0: ttyS4 at MMIO 0x42161000 (irq = 160, base_baud = 3125000) is a 16550A
[    7.674818] 0000:06:00.0: ttyS5 at MMIO 0x42171000 (irq = 161, base_baud = 3125000) is a 16550A
[    7.678954] 0000:06:00.0: ttyS6 at MMIO 0x42181000 (irq = 162, base_baud = 3125000) is a 16550A
[    7.680243] 0000:06:00.0: ttyS7 at MMIO 0x42191000 (irq = 167, base_baud = 3125000) is a 16550A
[    7.681502] ptp_ocp 0000:06:00.0: Could not find device ttyS4
[    7.681504] ptp_ocp 0000:06:00.0: Could not find device ttyS5
[    7.681504] ptp_ocp 0000:06:00.0: Could not find device ttyS6
[    7.681505] ptp_ocp 0000:06:00.0: Could not find device ttyS7
[    7.681522] ptp_ocp 0000:06:00.0: Version 1.2.0, clock PPS, device ptp0
[    7.681533] ptp_ocp 0000:06:00.0: Time: 1712200239.97249309, in-sync
[    7.681534] ptp_ocp 0000:06:00.0:  GNSS: /dev/ttyS4  @ 115200
[    7.681535] ptp_ocp 0000:06:00.0: GNSS2: /dev/ttyS5  @ 115200
[    7.681535] ptp_ocp 0000:06:00.0:   MAC: /dev/ttyS6  @  57600
[    7.681539] ptp_ocp 0000:06:00.0:  NMEA: /dev/ttyS7  @ 115200
```

SfCal, 2024-05-10:
Switched to the newly released Ubuntu 24.04 for some more testing.

Worked the same as Pop_OS but decided to recompile the kernel anyway in case. The only kernel parameter that wasn't already set correctly as defined by the install guide was `CONFIG_IKCONFIG=y` however this didn't seem to change anything.

After updating the card firmware this is what I'm getting.

```[    2.330759] ptp_ocp: loading out-of-tree module taints kernel.
[    2.331098] ptp_ocp: module verification failed: signature and/or required key missing - tainting kernel
[    2.332021] ptp_ocp 0000:02:00.0: enabling device (0000 -> 0002)
[    2.332598] ptp_ocp 0000:02:00.0: MSI/MSI-X info: 32
[    2.341284] ptp_ocp 0000:02:00.0: Could not find device ttyS6
[    2.341738] ptp_ocp 0000:02:00.0: Could not find device ttyS7
[    2.341739] ptp_ocp 0000:02:00.0: Could not find device ttyS8
[    2.341740] ptp_ocp 0000:02:00.0: Could not find device ttyS9
[    2.341812] ptp_ocp 0000:02:00.0: Version 1.2.0, clock PPS, device ptp3
[    2.342764] ptp_ocp 0000:02:00.0: Time: 1715354082.175616378, in-sync
[    2.342765] ptp_ocp 0000:02:00.0:  GNSS: /dev/ttyS6  @ 115200
[    2.342787] ptp_ocp 0000:02:00.0: GNSS2: /dev/ttyS7  @ 115200
[    2.342788] ptp_ocp 0000:02:00.0:   MAC: /dev/ttyS8  @  57600
[    2.342791] ptp_ocp 0000:02:00.0:  NMEA: /dev/ttyS9  @   9600
```

SfCal, 2024-06-11:
You'll have to forgive me here as I'm not super familiar with device drivers.

"Could not find device ttySX is located in `ptp_ocp_link_child()` which itself calls `device_find_child_by_name()`.

Here's where we see an issue. Printing child devices does not seem to return any of the ttySX's. What is the expected output here?

Here is what I modified in ptp_ocp.c and the corresponding dmesg output.

```
[    0.436299] pci 0000:02:00.0: [1d9b:0400] type 00 class 0x058000 PCIe Endpoint
[    0.436323] pci 0000:02:00.0: BAR 0 [mem 0x90000000-0x91ffffff]
[    0.536194] pci 0000:02:00.0: Adding to iommu group 2
[    3.178399] ptp_ocp: loading out-of-tree module taints kernel.
[    3.178403] ptp_ocp: module verification failed: signature and/or required key missing - tainting kernel
[    3.179012] ptp_ocp 0000:02:00.0: enabling device (0000 -> 0002)
[    3.179298] ptp_ocp 0000:02:00.0: MSI/MSI-X info: 32
[    3.179584] 0000:02:00.0: ttyS6 at MMIO 0x90161000 (irq = 188, base_baud = 3125000) is a 16550A
[    3.181108] 0000:02:00.0: ttyS7 at MMIO 0x90171000 (irq = 189, base_baud = 3125000) is a 16550A
[    3.182604] 0000:02:00.0: ttyS0 at MMIO 0x90181000 (irq = 190, base_baud = 3125000) is a 16550A
[    3.184083] 0000:02:00.0: ttyS1 at MMIO 0x90191000 (irq = 195, base_baud = 3125000) is a 16550A
[    3.185766] Parent device name: 0000:02:00.0
[    3.185770] Child device found: 0000:02:00.0:0
[    3.185775] ptp_ocp 0000:02:00.0: Could not find device ttyS6
[    3.185778] Parent device name: 0000:02:00.0
[    3.185782] Child device found: 0000:02:00.0:0
[    3.185786] ptp_ocp 0000:02:00.0: Could not find device ttyS7
[    3.185788] Parent device name: 0000:02:00.0
[    3.185792] Child device found: 0000:02:00.0:0
[    3.185795] ptp_ocp 0000:02:00.0: Could not find device ttyS0
[    3.185797] Parent device name: 0000:02:00.0
[    3.185801] Child device found: 0000:02:00.0:0
[    3.185805] ptp_ocp 0000:02:00.0: Could not find device ttyS1
[    3.185807] Parent device name: 0000:02:00.0
[    3.185811] Child device found: 0000:02:00.0:0
[    3.185857] ptp_ocp 0000:02:00.0: Version 1.2.0, clock PPS, device ptp3
[    3.185869] ptp_ocp 0000:02:00.0: Time: 1718135008.201674902, in-sync
[    3.185875] ptp_ocp 0000:02:00.0:  GNSS: /dev/ttyS6  @ 115200
[    3.185877] ptp_ocp 0000:02:00.0: GNSS2: /dev/ttyS7  @ 115200
[    3.185877] ptp_ocp 0000:02:00.0:   MAC: /dev/ttyS0  @  57600
[    3.185881] ptp_ocp 0000:02:00.0:  NMEA: /dev/ttyS1  @   9600
```
```
static int
print_child_device(struct device *dev, void *data)
{
    pr_info("Child device found: %s\n", dev_name(dev));
    return 0;
}

void ptp_ocp_link_child(struct ptp_ocp *bp, const char *name, const char *link)
{
    struct device *dev, *child;

    dev = &bp->pdev->dev;
//-------------------------------------
    if (!dev) {
        pr_err("Parent device is NULL\n");
        return;
    }
    pr_info("Parent device name: %s\n", dev_name(dev));

    device_for_each_child(dev, NULL, print_child_device);
//---------------------------------------

    child = device_find_child_by_name(dev, name);
    if (!child) {
        dev_err(dev, "Could not find device %s\n", name);
        return;
    }
```

vvfedorenko, 2024-08-05:
The changes introduced in kernel 6.8 made it impossible to find child tty device as we did before. The changes to the upstream driver are currently under review. In meanwhile you can use Out-Of-Tree driver.

SfCal, 2025-01-07:
Thank you for the update. This worked as expected.

Closed 2025-01-07.

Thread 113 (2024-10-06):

GPS module UART baud mismatch in code and TimeCard on sale?

regymm, 2024-10-06:
Please forgive me if this has already been issued. I'm kinda new to this project, and is working on a Verilog (instead of VHDL) version of the Time Card's FPGA project.

In the current open-source version, the GNSS baud rate is 19200 as specified in the block design (the parameter 4):
```
  set TC_TodSlave_0 [ create_bd_cell -type ip -vlnv nettimelogic.com:TimeCardLib:TC_TodSlave TC_TodSlave_0 ]
  set_property -dict [ list \
   CONFIG.UartDefaultBaudRate_Gen {4} \
 ] $TC_TodSlave_0
```

But on the time card I purchased (https://www.makerfabs.com/ocp-tap-time-card.html), the baud rate is 115200, and this parameter to 7 in order to function properly.

regymm, 2024-10-06:
However, after the baud rate config change, the ToDSlave registers are still different from the stock v1.2.0 firmware ones.

On stock firmware:
```
todslave: enablecontrol: 10000001
todslave: errorstatus: 00000000
todslave: uartpolarity: 00000001
todslave: version: 02020001
todslave: correction: 00000000
todslave: uartbaudrate: 00000007
todslave: utcstatus: 00000025 (was 00000125 for a short moment)
todslave: attennastatus: 32000442
todslave: satellitenumber: 00010206
```

On open source firmware:
```
todslave: enablecontrol: 10000001
todslave: errorstatus: 00000001 (00000000 then quickly becomes 00000001)
todslave: uartpolarity: 00000001
todslave: version: 00020003
todslave: correction: 00000000
todslave: uartbaudrate: 00000007
todslave: utcstatus: 00000000
todslave: attennastatus: 32070422
todslave: satellitenumber: 00011b2e
```

A UART parse error seems to occur, and utcstatus is always zero.
With this open-source firmware, if I run phc2sys like `sudo phc2sys -c CLOCK_REALTIME -s /dev/ptp4 -O0 -m`, I can still see the time from GPS be updated to the system clock and the 37s difference between TAI and UTC. No difference is visible between the stock firmware.

I wonder if this will affect something or if it's OK to ignore it?

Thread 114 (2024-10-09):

Time Stick driver crash while retrieving timestamp

rnijveld, 2024-10-09:
I got a driver crash while working with the time stick given to me during ISPCS2024 on my up-to-date Debian Bookworm machine. It uses kernel 6.1.0-26-amd64. It looks like one of the kernel protection mechanisms is triggered because of a memcpy in `ax_ptp.c:506` (see line 60 in the trace attached below). It appears the kernel isn't happy about the memcpy across multiple fields. Maybe the memcpy call can be replaced by separate calls for each field that needs to be copied from the one struct to the other. Alternatively we memcpy the entire struct and reset the fields that didn't need to be copied?

[time-stick-trace.txt](https://github.com/user-attachments/files/17300287/time-stick-trace.txt)

vvfedorenko, 2024-10-09:
The reason for this error is using CONFIG_FORTIFY_SOURCE=y kernel config option which prevents writing over several fields in structures. Even though the code doesn't corrupt memory, the kernel is pretty strict on the size of data type provided to mem* and str* functions. The easy fix would be to try to explicitly case pointer to `void *`:
`
@@ -503,7 +503,7 @@ static struct _ax_ptp_info *ax_ptp_info_transform(struct ax_device *axdev,
                for (i = 0; i < AX_PTP_HW_QUEUE_SIZE; i++) {
                        memcpy(&temp[i], &_179a_ptp[i], 2);
                        temp[i].sequence_id &= 0xFF;
-                       memcpy(&temp[i].nsec, &_179a_ptp[i].nsec, 10);
+                       memcpy((void *)&temp[i].nsec, (void *)&_179a_ptp[i].nsec, 10);
                }
                memcpy(data, temp, AX_PTP_INFO_SIZE);
                break;
`

I'll push a better solution to the repo to avoid such breaks

vvfedorenko, 2024-10-09:
The fix is pushed to the repo, could you please test it?

Closed 2025-01-08.

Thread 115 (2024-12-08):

Inqueries about the Time Card

regymm, 2024-12-08:
Hi, I don't know if this is the right place to ask questions about the Time Card (the mailing list discussion seems quite professional), but I'm working on a project of porting the Time Card FPGA design to [OpenXC7, the open-source FPGA toolchain](https://github.com/openXC7).

I have some questions about the FPGA design:

- I saw the clocks for AXI peripherals are two-fold: PTP-related parts use one clock, while system peripherals (UART, etc) use another. Is this only for easier management/coding, or has a performance impact?
- The DCXO also goes through clocking wizards and BufgMuxs until reaching the PTP clock domain. Will these impact performance? If not, what will be the major time-critical path in the design?
- Is the I2C bus used on the Time Card on sale? From the schematics, I saw the reference clock crystal oscillator doesn't have any I2C controls.

Thanks for your attention!

thschaub, 2024-12-09:
Hi

Your questions are not really issues. Howerer, I can try to answer your questions but I will not teaching you in FPGA design practices.

Regarding your first two questions, they can be addressed by understanding the use of different clock sources for the synchronization part. Certain components are designed to avoid losing lock and therefore use a separate, always-available clock source. Clock Domain Crossing (CDC) is managed through the AXI Interconnects.

In general, most of the design operates at 50MHz, which is not particularly critical. I recommend running the design and analyzing the timing paths to identify any potential critical issues.

As for the I2C usage, this can be clarified by referring to the documentation or building the design itself. You can find the relevant information in the manuals or at the following link:
https://github.com/opencomputeproject/Time-Appliance-Project/tree/master/Time-Card/FPGA/Open-Source/Implementation/Xilinx/TimeCard

Regards

regymm, 2024-12-10:
Thank you very much for the information!

Closed 2024-12-09.

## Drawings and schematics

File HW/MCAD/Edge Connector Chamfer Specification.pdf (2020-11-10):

A

B

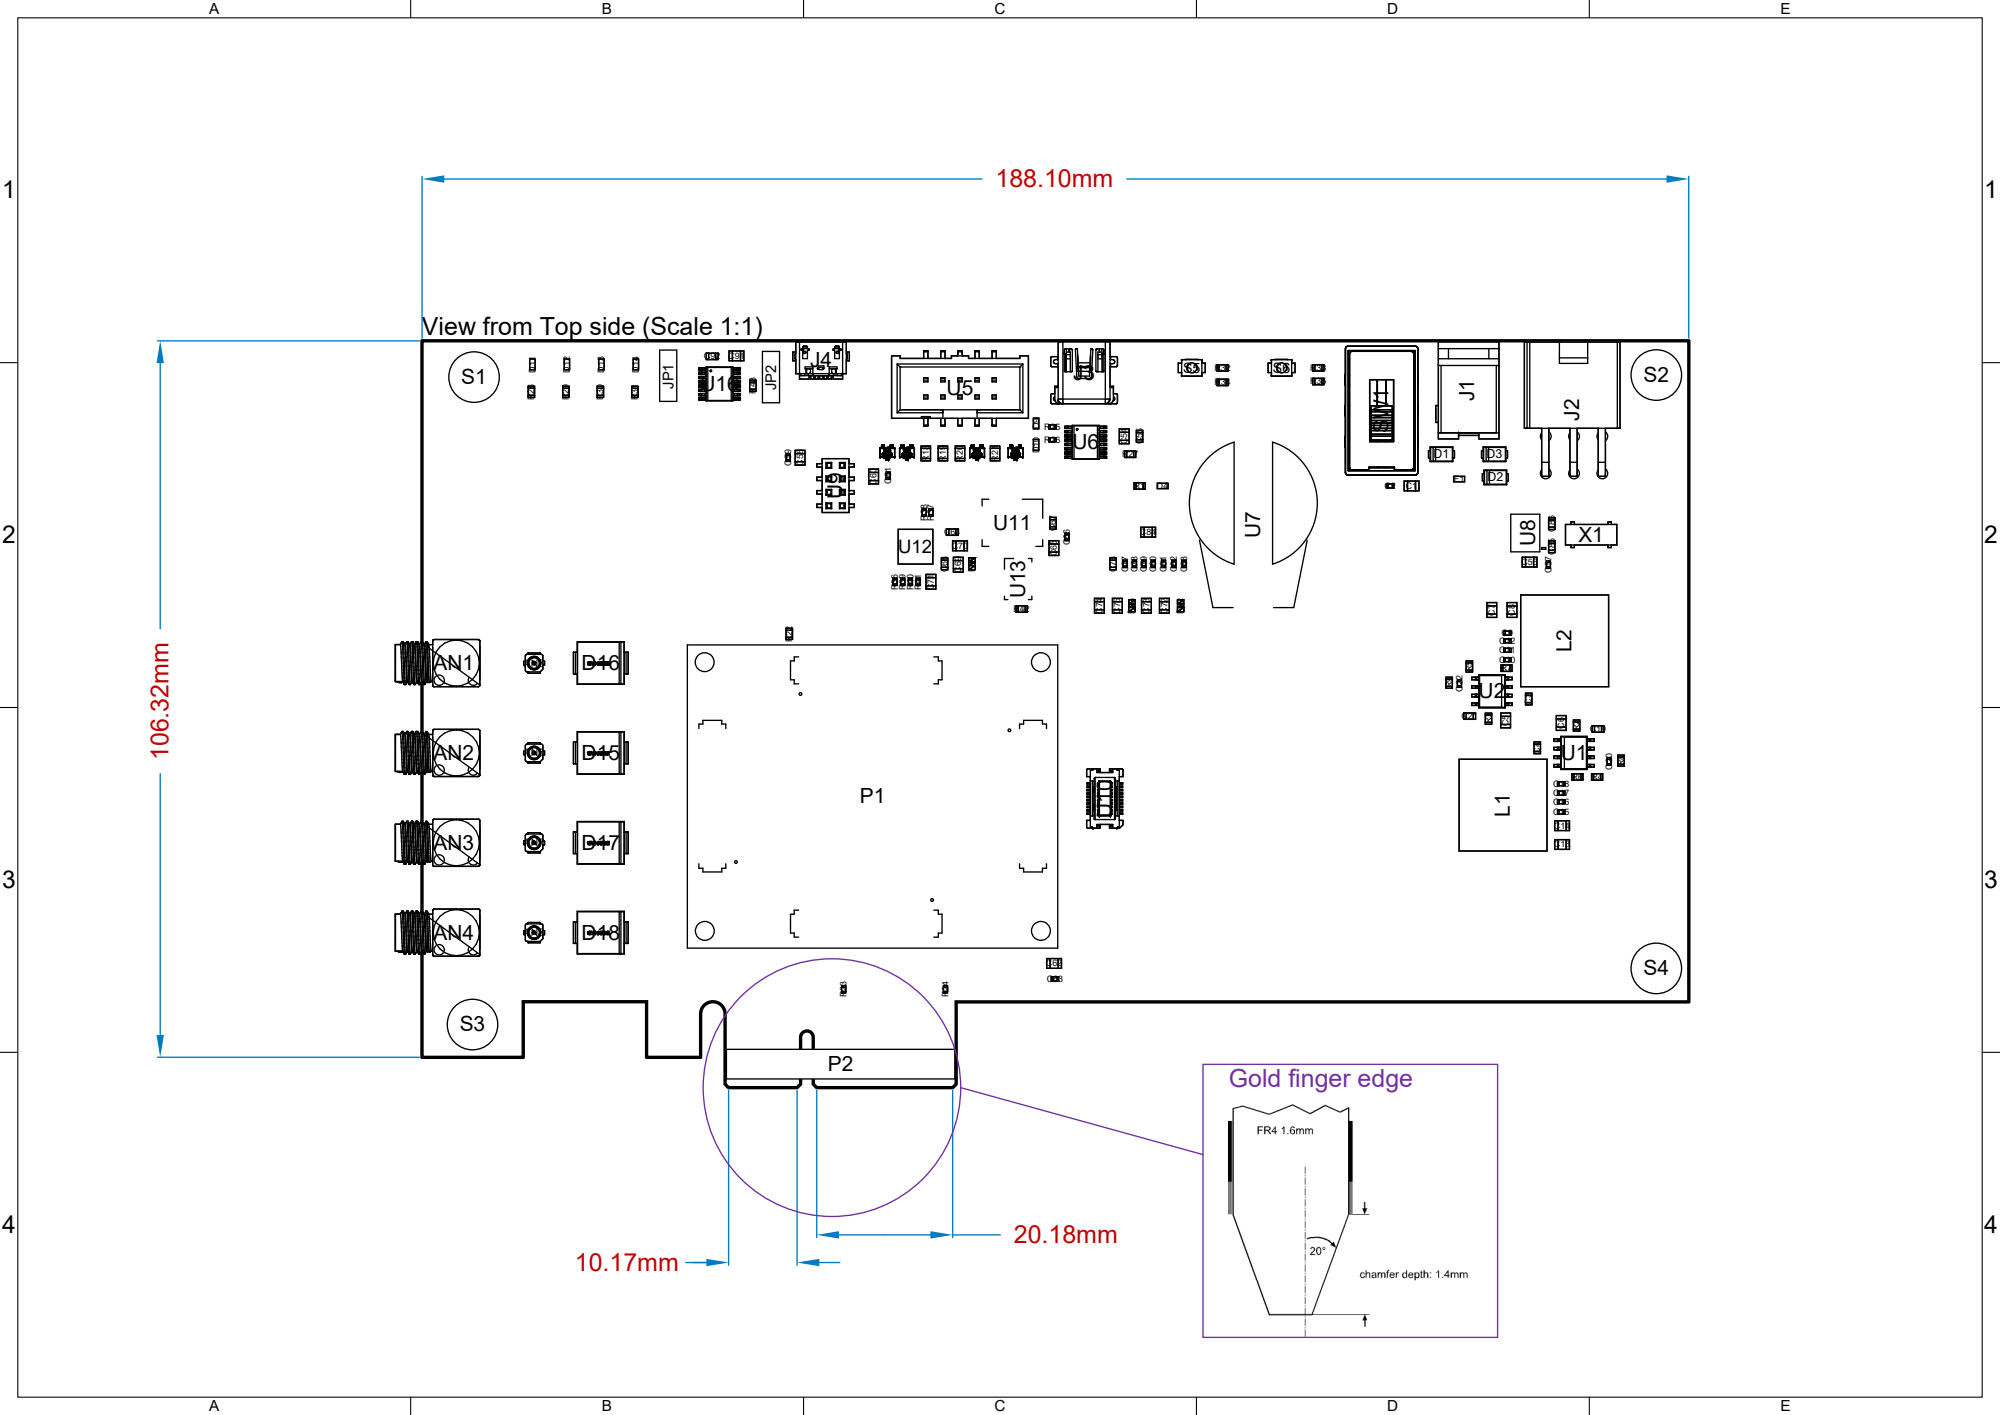
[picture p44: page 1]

View from Top side (Scale 1:1)

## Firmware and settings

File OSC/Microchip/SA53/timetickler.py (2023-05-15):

# Copyright (c) Facebook, Inc. and its affiliates. All rights reserved.

# This source code is licensed under the license found in the LICENSE file in the root directory of this source tree.

import argparse
import itertools
import logging
import os
import sys
 
import serial
 
BASE_SYS_TIMECARD_PATH = "/sys/class/timecard"
DEFAULT_BAUDRATE = 57600
 
MAC_COMMANDS_GET = [
    "DisciplineLocked",
    "DisciplineThresholdPps0",
    "PpsInDetected",
    "LockProgress",
    "PpsSource",
    "LastCorrection",
    "DigitalTuning",
    "Phase",
    "Temperature",
    "serial",
    "Locked",
    "PhaseLimit",
    "EffectiveTuning",
]
MAC_COMMANDS_SET = ["PpsWidth", "TauPps0", "PpsSource", "PpsOffset", "Disciplining", "DisciplineThresholdPps0", "PhaseMetering", "DigitalTuning", "CableDelay", "latch"]
 
log = logging.getLogger(__name__)

def query_system_timecards():
    timecards = os.listdir(BASE_SYS_TIMECARD_PATH)
    return timecards
 

def list_timecard(timecard):
    timecard_sys_class = os.listdir(os.path.join(BASE_SYS_TIMECARD_PATH, timecard))
    print(f"{timecard} sys class info:")
    for entity in timecard_sys_class:
        path = os.path.join(BASE_SYS_TIMECARD_PATH, timecard, entity)
        if os.path.islink(path):
            print("\t" + entity + " -> " + os.readlink(path))
        else:
            print("\t" + entity)
 

def get_mac_tty(timecard):
    mac_path = os.path.join(BASE_SYS_TIMECARD_PATH, timecard, "ttyMAC")
    mac_tty = os.path.basename(os.readlink(mac_path))
    return os.path.join(os.sep, "dev", mac_tty)
 

def query_timecard_mac(tty, fields, n):
    with serial.Serial(tty, baudrate=DEFAULT_BAUDRATE, timeout=1) as tty_dev:
        for i in itertools.count(start=0):
            if i == n:
                break
            for field in fields:
                cmd_str = "\{get," + field + "}"
                tty_dev.write(cmd_str.encode())
                field_val = tty_dev.readline().decode().strip()
                print(f"{field}, {field_val}")
 

def set_timecard_mac(tty, field, value, store=False):
    with serial.Serial(tty, baudrate=DEFAULT_BAUDRATE, timeout=1) as tty_dev:
        if field == "latch":
            cmd_str = "\{latch}"
        else:
            cmd_str = "\{set," + field + "," + value + "}"
        tty_dev.write(cmd_str.encode())
        if store:
            cmd_str = "\{store}"
            tty_dev.write(cmd_str.encode())
        ret_val = tty_dev.readline().decode().strip()
        if field == "latch":
            print(f"Set: {field}, stored: {store}, returned: {ret_val}")
        else:
            print(f"Set: {field} to: {value}, stored: {store}, returned: {ret_val}")
 

def main():
    parser = argparse.ArgumentParser("timetickler")
    subparsers = parser.add_subparsers(dest="command")
    get_parser = subparsers.add_parser("get", help="obtain value from field")
    set_parser = subparsers.add_parser("set", help="write value to field")
    list_parser = subparsers.add_parser("list", help="list timecard details on system")
 
    get_parser.add_argument(
        "field",
        nargs="+",
        choices=MAC_COMMANDS_GET + MAC_COMMANDS_SET,
    )
    get_parser.add_argument(
        "-n",
        default=1,
        type=int,
        help="query field 'n' times, or '-1' until terminated by user",
    )
 
    set_parser.add_argument("field", choices=MAC_COMMANDS_SET)
    set_parser.add_argument("value")
    set_parser.add_argument(
        "--store",
        "-s",
        help="store value into mac eeprom",
        action="store_true",
    )
 
    parser.add_argument(
        "timecard",
        nargs="?",
        default=query_system_timecards()[0],
        choices=query_system_timecards(),
        help="specify which timecard to list all info",
    )
 
    args = parser.parse_args()
    # print(args)
 
    if args.command == "get":
        query_timecard_mac(get_mac_tty(args.timecard), args.field, args.n)
    elif args.command == "set":
        set_timecard_mac(get_mac_tty(args.timecard), args.field, args.value, args.store)
    elif args.command == "list":
        list_timecard(args.timecard)
    else:
        parser.print_help()
 

if __name__ == "__main__":
    sys.exit(main())

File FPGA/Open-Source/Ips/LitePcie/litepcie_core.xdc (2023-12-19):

################################################################################
# IO constraints
################################################################################
# clk:0
set_property LOC X [get_ports {clk}]

# rst:0
set_property LOC X [get_ports {rst}]

# pcie:0.rst_n
set_property LOC X [get_ports {pcie_rst_n}]

# pcie:0.clk_p
set_property LOC X [get_ports {pcie_clk_p}]

# pcie:0.clk_n
set_property LOC X [get_ports {pcie_clk_n}]

# pcie:0.rx_p
set_property LOC X [get_ports {pcie_rx_p}]

# pcie:0.rx_n
set_property LOC X [get_ports {pcie_rx_n}]

# pcie:0.tx_p
set_property LOC X [get_ports {pcie_tx_p}]

# pcie:0.tx_n
set_property LOC X [get_ports {pcie_tx_n}]

# mmap_axi_lite:0.awvalid
set_property LOC X [get_ports {mmap_axi_lite_awvalid}]

# mmap_axi_lite:0.awready
set_property LOC X [get_ports {mmap_axi_lite_awready}]

# mmap_axi_lite:0.awaddr
set_property LOC X [get_ports {mmap_axi_lite_awaddr[0]}]

# mmap_axi_lite:0.awaddr
set_property LOC X [get_ports {mmap_axi_lite_awaddr[1]}]

# mmap_axi_lite:0.awaddr
set_property LOC X [get_ports {mmap_axi_lite_awaddr[2]}]

# mmap_axi_lite:0.awaddr
set_property LOC X [get_ports {mmap_axi_lite_awaddr[3]}]

# mmap_axi_lite:0.awaddr
set_property LOC X [get_ports {mmap_axi_lite_awaddr[4]}]

# mmap_axi_lite:0.awaddr
set_property LOC X [get_ports {mmap_axi_lite_awaddr[5]}]

# mmap_axi_lite:0.awaddr
set_property LOC X [get_ports {mmap_axi_lite_awaddr[6]}]

# mmap_axi_lite:0.awaddr
set_property LOC X [get_ports {mmap_axi_lite_awaddr[7]}]

# mmap_axi_lite:0.awaddr
set_property LOC X [get_ports {mmap_axi_lite_awaddr[8]}]

# mmap_axi_lite:0.awaddr
set_property LOC X [get_ports {mmap_axi_lite_awaddr[9]}]

# mmap_axi_lite:0.awaddr
set_property LOC X [get_ports {mmap_axi_lite_awaddr[10]}]

# mmap_axi_lite:0.awaddr
set_property LOC X [get_ports {mmap_axi_lite_awaddr[11]}]

# mmap_axi_lite:0.awaddr
set_property LOC X [get_ports {mmap_axi_lite_awaddr[12]}]

# mmap_axi_lite:0.awaddr
set_property LOC X [get_ports {mmap_axi_lite_awaddr[13]}]

# mmap_axi_lite:0.awaddr
set_property LOC X [get_ports {mmap_axi_lite_awaddr[14]}]

# mmap_axi_lite:0.awaddr
set_property LOC X [get_ports {mmap_axi_lite_awaddr[15]}]

# mmap_axi_lite:0.awaddr
set_property LOC X [get_ports {mmap_axi_lite_awaddr[16]}]

# mmap_axi_lite:0.awaddr
set_property LOC X [get_ports {mmap_axi_lite_awaddr[17]}]

# mmap_axi_lite:0.awaddr
set_property LOC X [get_ports {mmap_axi_lite_awaddr[18]}]

# mmap_axi_lite:0.awaddr
set_property LOC X [get_ports {mmap_axi_lite_awaddr[19]}]

# mmap_axi_lite:0.awaddr
set_property LOC X [get_ports {mmap_axi_lite_awaddr[20]}]

# mmap_axi_lite:0.awaddr
set_property LOC X [get_ports {mmap_axi_lite_awaddr[21]}]

# mmap_axi_lite:0.awaddr
set_property LOC X [get_ports {mmap_axi_lite_awaddr[22]}]

# mmap_axi_lite:0.awaddr
set_property LOC X [get_ports {mmap_axi_lite_awaddr[23]}]

# mmap_axi_lite:0.awaddr
set_property LOC X [get_ports {mmap_axi_lite_awaddr[24]}]

# mmap_axi_lite:0.awaddr
set_property LOC X [get_ports {mmap_axi_lite_awaddr[25]}]

# mmap_axi_lite:0.awaddr
set_property LOC X [get_ports {mmap_axi_lite_awaddr[26]}]

# mmap_axi_lite:0.awaddr
set_property LOC X [get_ports {mmap_axi_lite_awaddr[27]}]

# mmap_axi_lite:0.awaddr
set_property LOC X [get_ports {mmap_axi_lite_awaddr[28]}]

# mmap_axi_lite:0.awaddr
set_property LOC X [get_ports {mmap_axi_lite_awaddr[29]}]

# mmap_axi_lite:0.awaddr
set_property LOC X [get_ports {mmap_axi_lite_awaddr[30]}]

# mmap_axi_lite:0.awaddr
set_property LOC X [get_ports {mmap_axi_lite_awaddr[31]}]

# mmap_axi_lite:0.awprot
set_property LOC X [get_ports {mmap_axi_lite_awprot[0]}]

# mmap_axi_lite:0.awprot
set_property LOC X [get_ports {mmap_axi_lite_awprot[1]}]

# mmap_axi_lite:0.awprot
set_property LOC X [get_ports {mmap_axi_lite_awprot[2]}]

# mmap_axi_lite:0.wvalid
set_property LOC X [get_ports {mmap_axi_lite_wvalid}]

# mmap_axi_lite:0.wready
set_property LOC X [get_ports {mmap_axi_lite_wready}]

# mmap_axi_lite:0.wdata
set_property LOC X [get_ports {mmap_axi_lite_wdata[0]}]

# mmap_axi_lite:0.wdata
set_property LOC X [get_ports {mmap_axi_lite_wdata[1]}]

# mmap_axi_lite:0.wdata
set_property LOC X [get_ports {mmap_axi_lite_wdata[2]}]

# mmap_axi_lite:0.wdata
set_property LOC X [get_ports {mmap_axi_lite_wdata[3]}]

# mmap_axi_lite:0.wdata
set_property LOC X [get_ports {mmap_axi_lite_wdata[4]}]

# mmap_axi_lite:0.wdata
set_property LOC X [get_ports {mmap_axi_lite_wdata[5]}]

# mmap_axi_lite:0.wdata
set_property LOC X [get_ports {mmap_axi_lite_wdata[6]}]

# mmap_axi_lite:0.wdata
set_property LOC X [get_ports {mmap_axi_lite_wdata[7]}]

# mmap_axi_lite:0.wdata
set_property LOC X [get_ports {mmap_axi_lite_wdata[8]}]

# mmap_axi_lite:0.wdata
set_property LOC X [get_ports {mmap_axi_lite_wdata[9]}]

# mmap_axi_lite:0.wdata
set_property LOC X [get_ports {mmap_axi_lite_wdata[10]}]

# mmap_axi_lite:0.wdata
set_property LOC X [get_ports {mmap_axi_lite_wdata[11]}]

# mmap_axi_lite:0.wdata
set_property LOC X [get_ports {mmap_axi_lite_wdata[12]}]
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

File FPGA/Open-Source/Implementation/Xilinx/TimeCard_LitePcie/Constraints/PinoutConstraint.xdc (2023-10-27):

#CLOCK DCXO 1 and 2
set_property PACKAGE_PIN W21 [get_ports Mhz10ClkDcxo1_ClkIn]
set_property IOSTANDARD LVCMOS33 [get_ports Mhz10ClkDcxo1_ClkIn]
set_property PULLDOWN true [get_ports Mhz10ClkDcxo1_ClkIn]

set_property CLOCK_DEDICATED_ROUTE FALSE [get_nets Mhz10ClkDcxo1_ClkIn_IBUF]

#MAC RF Out
set_property PACKAGE_PIN V13 [get_ports Mhz10Clk0_ClkIn]
set_property IOSTANDARD LVCMOS33 [get_ports Mhz10Clk0_ClkIn]
set_property PACKAGE_PIN V14 [get_ports Mhz10Clk1_ClkIn]
set_property IOSTANDARD LVCMOS33 [get_ports Mhz10Clk1_ClkIn]

#Reset
set_property PACKAGE_PIN T6 [get_ports RstN_RstIn]
set_property IOSTANDARD LVCMOS15 [get_ports RstN_RstIn]

#200Hz
set_property IOSTANDARD DIFF_SSTL15 [get_ports Mhz200ClkP_ClkIn]
set_property PACKAGE_PIN R4 [get_ports Mhz200ClkP_ClkIn]
set_property PACKAGE_PIN T4 [get_ports Mhz200ClkN_ClkIn]
set_property IOSTANDARD DIFF_SSTL15 [get_ports Mhz200ClkN_ClkIn]

#125MHz
#set_property IOSTANDARD LVDS_25 [get_ports Mhz125ClkP_ClkIn]
set_property PACKAGE_PIN F6 [get_ports Mhz125ClkP_ClkIn]
set_property PACKAGE_PIN E6 [get_ports Mhz125ClkN_ClkIn]
#set_property IOSTANDARD LVDS_25 [get_ports Mhz125ClkN_ClkIn]

#Buttons
set_property PACKAGE_PIN J21 [get_ports {Key_DatIn[0]}]
set_property IOSTANDARD LVCMOS33 [get_ports {Key_DatIn[0]}]
set_property PACKAGE_PIN E13 [get_ports {Key_DatIn[1]}]
set_property IOSTANDARD LVCMOS33 [get_ports {Key_DatIn[1]}]

#LEDs
set_property PACKAGE_PIN B13 [get_ports {Led_DatOut[0]}]
set_property IOSTANDARD LVCMOS33 [get_ports {Led_DatOut[0]}]
set_property PACKAGE_PIN C13 [get_ports {Led_DatOut[1]}]
set_property IOSTANDARD LVCMOS33 [get_ports {Led_DatOut[1]}]
set_property PACKAGE_PIN D14 [get_ports {Led_DatOut[2]}]
set_property IOSTANDARD LVCMOS33 [get_ports {Led_DatOut[2]}]
set_property PACKAGE_PIN D15 [get_ports {Led_DatOut[3]}]
set_property IOSTANDARD LVCMOS33 [get_ports {Led_DatOut[3]}]

#IO LEDs
#set_property PACKAGE_PIN E21 [get_ports {IoLed_DatOut[0]}]
#set_property IOSTANDARD LVCMOS33 [get_ports {IoLed_DatOut[0]}]
#set_property PACKAGE_PIN D21 [get_ports {IoLed_DatOut[1]}]
#set_property IOSTANDARD LVCMOS33 [get_ports {IoLed_DatOut[1]}]
#set_property PACKAGE_PIN E22 [get_ports {IoLed_DatOut[2]}]
#set_property IOSTANDARD LVCMOS33 [get_ports {IoLed_DatOut[2]}]
#set_property PACKAGE_PIN D22 [get_ports {IoLed_DatOut[3]}]
#set_property IOSTANDARD LVCMOS33 [get_ports {IoLed_DatOut[3]}]

#PMOD
#set_property PACKAGE_PIN M22 [get_ports {Pmod_DatOut[0]}]
#set_property IOSTANDARD LVCMOS33 [get_ports {Pmod_DatOut[0]}]
#set_property PACKAGE_PIN N22 [get_ports {Pmod_DatOut[1]}]
#set_property IOSTANDARD LVCMOS33 [get_ports {Pmod_DatOut[1]}]
#set_property PACKAGE_PIN H18 [get_ports {Pmod_DatOut[2]}]
#set_property IOSTANDARD LVCMOS33 [get_ports {Pmod_DatOut[2]}]
#set_property PACKAGE_PIN H17 [get_ports {Pmod_DatOut[3]}]
#set_property IOSTANDARD LVCMOS33 [get_ports {Pmod_DatOut[3]}]
#set_property PACKAGE_PIN H22 [get_ports {Pmod_DatOut[4]}]
#set_property IOSTANDARD LVCMOS33 [get_ports {Pmod_DatOut[4]}]
#set_property PACKAGE_PIN J22 [get_ports {Pmod_DatOut[5]}]
#set_property IOSTANDARD LVCMOS33 [get_ports {Pmod_DatOut[5]}]
#set_property PACKAGE_PIN K21 [get_ports {Pmod_DatOut[6]}]
#set_property IOSTANDARD LVCMOS33 [get_ports {Pmod_DatOut[6]}]
#set_property PACKAGE_PIN K22 [get_ports {Pmod_DatOut[7]}]
#set_property IOSTANDARD LVCMOS33 [get_ports {Pmod_DatOut[7]}]

#EEPROM
set_property PACKAGE_PIN V9 [get_ports EepromWp_DatOut]
set_property IOSTANDARD LVCMOS15 [get_ports EepromWp_DatOut]

#QSPI Flash
set_property PACKAGE_PIN P22 [get_ports SpiFlashDq0_DatInOut]
set_property IOSTANDARD LVCMOS33 [get_ports SpiFlashDq0_DatInOut]
set_property PACKAGE_PIN R22 [get_ports SpiFlashDq1_DatInOut]
set_property IOSTANDARD LVCMOS33 [get_ports SpiFlashDq1_DatInOut]
set_property PACKAGE_PIN P21 [get_ports SpiFlashDq2_DatInOut]
set_property IOSTANDARD LVCMOS33 [get_ports SpiFlashDq2_DatInOut]
set_property PACKAGE_PIN R21 [get_ports SpiFlashDq3_DatInOut]
set_property IOSTANDARD LVCMOS33 [get_ports SpiFlashDq3_DatInOut]
set_property PACKAGE_PIN T19 [get_ports SpiFlashCsN_EnaOut]
set_property IOSTANDARD LVCMOS33 [get_ports SpiFlashCsN_EnaOut]

#I2C
set_property PACKAGE_PIN N17 [get_ports I2cScl_ClkInOut]
set_property IOSTANDARD LVCMOS33 [get_ports I2cScl_ClkInOut]
set_property PULLUP true [get_ports I2cScl_ClkInOut]
set_property PACKAGE_PIN T16 [get_ports I2cSda_DatInOut]
set_property IOSTANDARD LVCMOS33 [get_ports I2cSda_DatInOut]
set_property PULLUP true [get_ports I2cSda_DatInOut]

#SMA Inputs/Outputs
# INPUTS
# ANT1 Y11
# ANT2 Y12
# ANT3 AA21
# ANT4 AA20
# ANT1_IN_EN H15
# ANT2_IN_EN J14
# ANT3_IN_EN K14
# ANT4_IN_EN L13
# OUTPUTS
# ANT1 W11
# ANT2 W12
# ANT3 V10
# ANT4 W10
# ANT1_OUT_EN J15
# ANT2_OUT_EN H14
# ANT3_OUT_EN K13
# ANT4_OUT_EN M13
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

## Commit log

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2020-11-10 fixed the config
    [BOM.xlsx, FPGA.SchDoc, GPS-IMU.SchDoc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]
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2020-11-11 Remove space from directory name to fix driver compilation
    [BOM.xlsx, FPGA.SchDoc, GPS-IMU.SchDoc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]
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2020-12-01 Added AND-logic for DCM locked signal to properly reset the system on a clock switch Updated Bitstreams
2020-12-01 Created proper reset on clock source switch since PLL lock loss is not guaranteed.
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2021-02-18 refactored schematics and updated pcb
    schematic template, changed 0402 res to 0603 res for non-critical components, pcb cleanup, rebuilt project library component packages and footprints
    [FPGA.SchDoc, GPS-IMU.SchDoc, GPS_IMU_SENSORS.SchDoc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]
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2021-03-29 Extended MSI interrupts to 8, connected I2C interrupt (imu and osc) Updated Readmed with new interrupts, fixed typos in address mapping (GPS and GPS2 swapped), fixed wrong High Addresses
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2021-04-06 Fixed I2C IO mapping
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2021-04-08 Added logic as possible workaround for missing pull up resistors (on PCB) for I2C Added logic to initialize IMU (BNO08X device) I2C interface correctly Fixed mapping of I2C interface for BNO08X
2021-04-09 Removed workaround logic for no Pull-Ups since it was wrong with the tristate-logic. Assigned I2C signals directly via tristate-buffes to IO
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2021-04-20 ptp_ocp: Initialize PI parameters, add holdover watchdog
    Initialize the PI servo with recommended values.
    Add a watchdog which checks whether the card went into holdover.
    If it did, reinitialize the drift values back to 0.
    [ptp_ocp.c]
2021-04-22 ptp_ocp: Use PPS status for holdover detection.
    If the PPS_SUPERV_ERR bit is set, this indicates that the
    PPS signal from the GPS receiver is missing. This bit
    is sticky, and must be acknowledged by writing the same
    back into the register.
    When the loss is initially detected, reset the drift registers.
    [ptp_ocp.c]
2021-04-22 ptp_ocp: add devlink health reporter for gps signal
    When the watchdog detects that the GPS signal has been lost,
    it reports a devlink health error. The time when the signal
    has been lost can be retrieved through diagnose:
    devlink health diagnose pci/0000:04:00.0 reporter gps_sync
    The current sync status, and the number of times the signal
    was lost, if any, can be seen with 'devlink health':
    # devlink health
    pci/0000:04:00.0:
    reporter gps_sync
    state healthy error 1 recover 0
    [ptp_ocp.c]
2021-04-23 ptp_ocp: use correct enumeration for CLK_SELECT_REGS
    The wrong value was being used for the clock selection, fix.
    [ptp_ocp.c]
2021-04-23 Changes PI Servo Paramters (no drift correction)
    [ptp_ocp.c]
2021-04-26 Added Quad SPI and HWICAP for flash update Replaced I2C Imu with Quad SPI Imu Added EEPROM WP to Ext GPIO Added MSI Interrupt Edge Generator for Level Interrupt of Osc I2C
    Added Production_TimeCard.bin (includes Golden and Update Image) to flash via JTAG
    ===================================
    Configuration Memory information
    ===================================
    File Format BIN
    Interface SPIX4
    Size 32M
    Start Address 0x00000000
    End Address 0x01FFFFFF
    Addr1 Addr2 File(s)
    0x00000000 0x002856FF Golden_TimeCard.bit
    0x00400000 0x0069B5AB TimeCard.bit
2021-04-28 ptp_ocp: add SPI devices
    The new bitstream adds SPI controllers, so hook them up. There is
    also an HWICAP controller, which hasn't been handled yet.
    The irq vector size has increased to 10 in order to handle the
    new devices. Rework the device registration a bit so devices are
    registered or skipped based on the irq availability.
    [ptp_ocp.c]
2021-04-28 ptp_ocp: restructure driver for better resource assignments.
    Rework the ocp resources, removing the fixed resource entries in
    favor of a dynamic table. The table is now attached to the PCI
    device id, paving the way for different resource entries.
    Hook up the SPI flash. While still somewhat flaky, reads from the
    flash are successful. Writes are not working yet.
    [ptp_ocp.c]
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2021-04-30 Added Axi Version Register (0x0200_0000) Fixed messed up Osc I2C with interrupt Updated Documentation and Images
    Golden Version 0x0001_0000
    Regular Version 0x000_0001
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2021-05-05 ptp_ocp: add support for devlink flashing.
    The timecard contains two images in flash:
    - a golden image intended for rebooting/reflashing
    - a timecard.bin image that normally runs.
    In order to flash a new image, the following procedure is used:
    1) copy the new TimeCard.bin image to /lib/firmware.
    2) devlink dev flash pci/0000:04:00.0 file TimeCard.bin
    3) power cycle.
    [ptp_ocp.c]
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2021-05-11 Add Orolia's ART card support
    - Add Generic PPS device
    - Add Phasemeter between oscillator and GNSS
    - Add GNSS UART
    [ptp_ocp.c]
2021-05-11 Revert "[WIP] Orolia art card integration"
    [ptp_ocp.c]
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2021-06-10 ptp_ocp: use correct value for SAVE_COARSE
    [ptp_ocp.c]
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2021-08-11 Update for Orolia I2C eeprom.
    Add support for the I2C eeprom. This will likely change, as the
    eeprom shouldn't be exposed to the user.
    Create orolia-specific attributes for the timecard directory.
    Add devlink workaround for new kernel version.
    [ptp_ocp.c]
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2021-08-23 ptp: ocp: Skip resources with out of range irqs
    The TimeCard exposes different resources, which may have their
    own irqs. Space for the irqs is allocated through a MSI or MSI-X
    interrupt vector. On some platforms, the interrupt allocation fails.
    Rather than making this fatal, just skip exposing those resources.
    The main timecard functionality (that of a PTP clock) will work
    without the additional resources.
    [ptp_ocp.c]
2021-08-26 Update art card devices
    - create 2 PTP external timestamps:
    - One generated when the internal PPS of the card is
    triggered
    - One generated when the GNSS receiver PPS is triggered
    - Turn phasemeter into registers only
    - phasemeter does not expose external timestamps
    corresponding to phase error (obtained by comparing the
    2 external timestamps mentionned above)
    - Add Orolia flash start address
    - Increase num of requested IRQ to 16
    - Fix ocp_art_pps_red and ocp_phaseèreg definitions
    [ptp_ocp.c]
2021-08-27 ptp: ocp: Fix uninitialized variable warning spotted by clang.
    If attempting to flash the firmware with a blob of size 0,
    the entire write loop is skipped and the uninitialized err
    is returned. Fix by setting to 0 first.
    [ptp_ocp.c]
2021-08-27 ptp: ocp: Fix error path for pci_ocp_device_init()
    If ptp_ocp_device_init() fails, pci_disable_device() is skipped.
    Fix the error handling so this case is covered. Update ptp_ocp_remove()
    so the normal exit path is identical.
    [ptp_ocp.c]
2021-08-27 Fixup comments and whitespace.
    [ptp_ocp.c]
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2021-08-28 Swap SMA1 and SMA2
    [ptp_ocp.c]
2021-08-28 Swap SMA3 and SMA4
    [ptp_ocp.c]
2021-08-30 Whitespace change: Fix tabs
    [ptp_ocp.c]
2021-08-30 Correct debugfs display for smaX -> PPS1 -> PHC steering
    [ptp_ocp.c]
2021-08-30 Correct README regarding # of i2c devices.
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2021-09-09 Add PCI delay estimator
    The following process is used to read the PHC clock and correlate
    the reading with the "correct" system time.
    - get starting timestamp
    - issue PCI write command
    - issue PCI read command
    - get ending timestamp
    The write command is posted to PCI bus and returns. When the write
    arrives at the FPGA, the PHC time is latched into the sec/nsec registers,
    and a flag is set indicating the registers are valid. The read command
    returns this flag, and the time retrieval proceeds.
    Below is a non-scaled picture of the timing diagram involved. The
    PHC time corresponds to some SYS time between [start, end]. Userspace
    usually uses the midpoint between [start, end] to estima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
    [ptp_ocp.c]
2021-09-10 Make PPS_PEROUT a NOP (have it return 0)
    The prior patch added PPS_PEROUT support for ts2phc, as that command
    fails if PPS_PEROUT errors. However, the PEROUT command is expected
    to enable 1PPS on an output connector, not deliver it for external use.
    external signals are controlled via sysfs, so just skip this for now.
    [ptp_ocp.c]
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2021-09-11 Fixup sma selectors
    The last commit botched the settings for the sma outputs. Fix.
    Add labels for the sma attributes so it's clear what direction
    is being used on the connectors.
    [ptp_ocp.c]
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2021-09-14 Delete phasemeter from ART card
    - As ptp_ocp_adjtime_changed we can now use this function
    to correct the phase error by adjusting clock's nanoseconds
    [ptp_ocp.c]
2021-09-22 Fix broken OTS assembly picture link
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2022-01-04 Renamed Production_TimeCard.bin to Factory_TimeCard.bin (Golden Image + Update Image) Added bidirectional support for ANT/SMA1-4 connectors (default is still 1 & 2 inputs, 3 & 4 outputs) Direction mu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
2022-01-06 Version: 0x8002 Added all missing Inputs and Outputs and connected them to the AXI GPIO EXT. Added Logic to keep GPS UART TX on 'Z' for 1s after PLL has locked. Documentation cleanup
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2022-01-20 Bugfixes for signal setting.
    Signal is set as:
    period [duty [phase [polarity]]]
    phase and period are expressed as <sec>.<nsec>
    duty is a percentage from 0 - 99.
    unspecified arguments default to previous values.
    setting 0 period disables signal generation.
    Examples:
    echo 1 > signal # 1 second period.
    echo "0.500000000" > signal # .5 second period
    echo "0.500000000 30" > signal # .5 second period, 30% duty
    echo "0.500000000 30 0.100000000" > signal
    # signal shifted .1 sec
    [ptp_ocp.c]
2022-01-21 Tie in the 2nd signal generator for firmware v19
    - also fix a bug where a bad index was used during the driver unload.
    [ptp_ocp.c]
2022-01-25 ptp: ocp: Expose clock status drift and offset
    Monitoring of clock variance could be done through checking
    the offset and the drift updates that are applied to atomic
    clocks. Expose these values as attributes for timecard.
    [ptp_ocp.c]
2022-01-25 ptp: ocp: add tod_correction attribute
    TOD correction register is used to compensate for leap seconds in
    different domains. Export it as attribute with write access.
    [ptp_ocp.c]
2022-01-25 ptp: ocp: adjust utc_tai_offset to TOD info
    utc_tai_offset is used to correct IRIG, DCF and NMEA outputs and is
    set during initialisation but is not corrected during leap second
    announce event. Add watchdog code to control this correction.
    [ptp_ocp.c]
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2022-01-25 Rename 'GNSS' to 'GNSS1' for clarity
    This also works around a parsing issue.
    [ptp_ocp.c]
2022-01-26 Add some firmware capability bits for enabling features
    This way non-present attributes are omitted, and the summary
    page does not crash when running on older firmware.
    [ptp_ocp.c]
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2022-01-26 Handle correct error return from ptp_ocp_get_mem
    ptp_ocp_get_mem returns an errno on error, not NULL, so handle
    this appropriately.
    [ptp_ocp.c]
2022-01-26 Bug cleanup
    - Fix input mapping for TS3 and TS4
    - Null check attr_tbl in case resources errored out early.
    [ptp_ocp.c]
2022-01-27 Version: 0x8005 Fixed address space of Frequency Counters Increased MSI Size for interrupts
2022-01-27 Update firmware v21 - correct frequency generators.
    [ptp_ocp.c]
2022-01-28 Adjust signal generator settings
    Set target start time to (now + 1MS), then round this up to a multiple
    of the period. 1MS allows for some latency when setting the clock.
    Only disable generator on error.
    Tweak debug output to show actual register values.
    [ptp_ocp.c]
2022-02-09 ptp: ocp: fix i2c reading and board info offsets
    i2c-xiic driver always reads 2 bytes and current code treats it as
    error when it tries to read odd amount of bytes for board part
    number info. Fix it and also fix the offsets for board info
    provided by manufacturers.
    [ptp_ocp.c]
2022-02-11 Version: 0x0016 Reduced ext_spi_clk of the AXI QUAD SPI to 50MHZ since 100MHz was out of spec. Added a SoftFlash Reset after successful boot up to bring the flash in a proper state e.g. for Firmware 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
2022-02-25 ptp: ocp: rework devlink firmware display path.
    Cache the firmware version when the card is initialized,
    and use this field to populate the devlink firmware information.
    [ptp_ocp.c]
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2022-03-08 ptp: ocp: add UPF_NO_THRE_TEST flag for serial ports
    The serial port driver attempts to test for correct THRE behavior
    on startup. However, it does this by disabling interrupts, and
    then intentionally trying to trigger an interrupt in order to see
    if the IIR bit is set in the UART.
    However, in this FPGA design, the UART interrupt is generated
    through the MSI vector, so when interrupts are re-enabled after
    the test, the DMAR-IR reports an unhandled IRTE entry, since
    no irq handler is installed at this point - it is installed
    after the test.
    This only happens on the /second/ open of the UART, since on the
    first open, the x86_vector has installed and activated by the
    driver probe, and is cor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
    [ptp_ocp.c]
2022-03-09 Production TimeCard Version 7 (0x8007) The MsiIrq generator supports now level interrupts and handles them correctly. Enabled e.g. for AXI UART 16550.
2022-03-09 TimeCard Version 24 (0x0018) The MsiIrq generator supports now level interrupts and handles them correctly. Enabled e.g. for AXI UART 16550.
2022-03-10 Production TimeCard Version 8 (0x8008) Swapped SMA1 <-> SMA3 and SMA2 <-> SMA4 (including LEDs). Connectors are matching now with the labeling on the card. There was a mismatch between card labeling 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
2022-03-10 Catchup to mainline changes - mostly whitespace fixes, minor bug items. - remove mfr information from devlink
    [ptp_ocp.c]
2022-03-10 ptp: ocp: Fix PTP_PF_* verification requests
    Update and check functionality for pin configuration requests:
    PTP_PF_NONE: requests "IN: None", disabling the pin.
    # testptp -d /dev/ptp3 -L3,0 -i1
    set pin function okay
    # cat sma4
    IN: None
    PTP_PF_EXTTS: should configure external timestamps, but since the
    timecard can steer inputs to multiple inputs as well as timestamps,
    allow the request, but don't change configurations.
    # testptp -d /dev/ptp3 -L3,1 -i1
    set pin function okay
    (no functional or configuration change here yet)
    PTP_PF_PEROUT: Channel 0 is the PHC, at 1PPS. Channels 1-4 are
    the programmable frequency generators.
    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
    [ptp_ocp.c]
2022-03-11 Time Drive first prototype check-in
    Time Drive, a UWB based M.2 design that uses a Decawave UWB transceiver with an Analog Devices AD9546 DPLL to achieve wireless synchronization.
    [01-TableOfContents.SchDoc, 02-BlockDiagram.SchDoc, 03-M2Finger.SchDoc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]
2022-03-21 ptp: ocp: handle error from nvmem_device_find
    nvmem_device_find returns a valid pointer or IS_ERR().
    Handle this properly.
    [ptp_ocp.c]
2022-03-21 ptp: orolia: handle error return from nvmem_device_get
    [ptp_ocp.c]
2022-03-23 ptp: ocp: parameterize input/output sma selectors
    Group the sma input/output tables together and select the correct
    group from the bp information. This allows adding new groups with
    different sma mappings.
    [ptp_ocp.c]
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2022-03-23 ptp: ocp: add .init function for sma_op vector
    Create an .init function for the op vector, and set it to
    ptp_ocp_sma_init(), for different sma mapping setups.
    Add a default_fcn to the sma information, and use it when displaying
    information for pins which have fixed functions.
    [ptp_ocp.c]
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2022-03-23 Bring in upstream fix:
    2b341f7532d4 ("ptp: ocp: Make debugfs variables the correct bitwidth")
    [ptp_ocp.c]
2022-03-23 Bring in upstream fix:
    d5f497b88979 ("ptp: ocp: use snprintf() in ptp_ocp_verify()")
    [ptp_ocp.c]
2022-03-23 ptp: ocp: fix PPS source selector reporting
    The NTL timecard design has a PPS1 selector which selects the
    the PPS source automatically, according to Section 1.9 of the
    documentation.
    If there is a SMA PPS input detected:
    - send signal to MAC and PPS slave selector.
    If there is a MAC PPS input detected:
    - send GNSS1 to the MAC
    - send MAC to the PPS slave
    If there is a GNSS1 input detected:
    - send GNSS1 to the MAC
    - send GNSS1 to the PPS slave.MAC
    [ptp_ocp.c]
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2022-03-28 ptp: ocp: 32-bit fixups for pci start address
    Use 'resource_size_t' instead of 'unsigned long' when computing the
    pci start address, for the benefit of 32-bit platforms.
    [ptp_ocp.c]
2022-03-28 ocp: orolia: Correct name of PPS output
    Orolia card has the PPS output from GNSS (ublox) or MAC (mro50).
    Correct the labeling.
    [ptp_ocp.c]
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2022-05-16 ocp: devlink: fix flashing without header
    Preserve fallback flashing without firmware header until we have
    tool to create the header
    [ptp_ocp.c]
2022-05-20 Fix i2c_mac device
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2022-05-30 fw: add tool to create firmware image header
    Driver has special check to avoid flashing wrong image, but there
    was no tooling to create proper header for firmware image. This
    simple tool can add required information.
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2022-07-06 ptp: ocp: change card serial number offset
    The latest hardware version of ART-CARD have serial number stored
    slightly before in EEPROM. Update driver to read it from correct
    offset.
    [ptp_ocp.c]
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2022-07-12 Fix temperature table offset
    [ptp_ocp.c]
2022-07-29 Time Drive V2 WIP
    Work in progress on Time Drive V2.
    Current open issues on follower:
    1. Phase adjustment needs to be verified, using the Q dividers on AD9546 requires proper calculation of offset degrees to adjust.
    2. Verify when phase adjustment is made if there are discontinuities on the 1PPS.
    3. Can I use the NCO absolute phase adjust if I change some of the DPLL parameters? This config here has that change, but need to test.
    [01-Onboard_GPS.SchDoc, 02-RaspberryPi_Header.SchDoc, 03-GPS_DaughterCards.SchDoc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]
2022-08-10 ptp_ocp: fix formatting
    Some formatting issues were found in driver code, simply fix them.
    No changes in logic.
    [ptp_ocp.c]
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2022-11-21 Latest prototype Time Card
    1. Adds support for atomic clocks with single-ended PPS input / output
    2. Adds support for 3.3V / 5V / 12V options for atomic clock footprint
    3. Adds ATX connector for external power
    4. Moves JTAG connector so it can be installed along with dual GPS
    5. Added adafruit standard i2c header
    6. Flipped the MAC footprint so SA53 label is correct
    7. Updated BOM so all connectors are assembled and standoffs/screws come with the board
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2022-12-05 updated RCB-F9T schematic and layout to address buffer bug
    [Antenna_Supervisor.SchDoc, GPS_MODULE_ZED-F9T-00B.PrjPcb, ZED-F9T.SchDoc]
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2023-01-13 Added some missing update of files for the latest update with the SMA Input Status (already in version 0x005)
    [SmaSelector_Regset.xlsx]
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2023-01-22 ptp_ocp: fix null pointer access in summary page
    Fixes the debug summary page crash in case less than 4 generators are enabled.
    [ptp_ocp.c]
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2023-01-27 Updated Time Card v8 to fix LED driver and add diode silkscreens
2023-01-27 SA45 Daughter Card Commit
    Uploading SA45 compatible daughter card. With this, an SA45 CSAC or oscillator with that footprint can be installed into the same Time Card baseboard. Targetting Time Card v8 , with sockets and screw holes, but can be soldered into older revision Time Cards as well.
    [SA45_DaughterCard-RevX1_bom.xlsx]
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2023-03-27 Uploading first rev of PPSDO module design
    PPSDO is based around AD9546 DPLL as timing ASIC, with a SiT5711 or SiT5721 as the long term stability source. As of 3/27/2023, I'm building some prototypes, but have not received, hence the Experimental_NotTested.
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2023-05-09 TimeCardV9 Experimental Upload
    Uploading Revision 9 of Time Card as Not tested. Change list as follows:
    1. Shrunk the design to fit PCIe full height half length
    2. Added DIP switch for MAC / LOFF to switch between UART and I2C
    3. Added I2C multiplexer to break up the i2c tree for stability
    4. Added second 4 pin header for i2c daughter card.
    5. Moved many components to fit in smaller form factor
    6. Added M2 options for GNSS as an option instead of RCB following pinout discussed
    7. Changed 12V power path to use less components
    8. Changed power supplies to support Cyntec or Delta power modules. Cyntec is primary BOM option now, but footprint and components are available for both.
    9. Changed FPG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
2023-05-11 OCXO V3 BOM change
    1. Changing OCXO V3 BOM default to use single ended from baseboard, instead of differential.
    2. Adding a no oscillator version for a generic board for manual soldering in lab
    [Abracon_AOCJYR_bom.xlsx, NoOscillator_bom.xlsx, Pick Place for OCXO_DaughterCard.csv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]
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2023-05-16 OCXO BOMs
    Updating OCXO daughter card BOMs to list alternative BOM options for the long pins to the baseboard, and to fix No Oscillator BOM with no oscillator
    [Abracon_AOCJYR_bom.xlsx, NoOscillator_bom.xlsx, Rakon_RFPO45_bom.xlsx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]
2023-05-17 Updated TOD Slave to 0.2.1 -Added TSIPv1 messages support -Minor cleanup/fixes in documentation
    [CoreListRegset.xlsx, DefaultConfigFile.txt, TodSlave_Regset.xlsx]
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2023-07-01 NEO M2 V2
    1. Added LED for TP1
    2. Added length matching for USB
    3. Fixed some BOM options
    [BOM_M2_NEO-M9N_MODULE.xlsx, Pick Place for M2_NEO-M9N_MODULE(845-XXXXX_PCBA_projectname).csv]
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2023-07-03 Time Card V9 Release
    Tested and verified Time Card V9. Made some changes to the board from previous experimental release to fix some issues found.
    [Pick Place for TimeCard-DC-V8_EXP.csv, Pick Place for TimeCard-DC-V9_EXP.csv, TimeCardV9_BOM.xlsx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]
2023-07-04 Fix Time Card V9 BOM
    [TimeCardV9_BOM.xlsx]
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2023-08-07 updated USBSerial to Serial and corrected logic in device ID identification.
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2023-08-31 Fix 85 ohm for PCIe for WR NIC
2023-09-05 fix shellcheck issues with time card driver script
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2023-10-06 Fixed wrong UTC Offset in TodSlave when Beidou was selected. Fixed wrong constant default value, which was causing potential interrupt flood.
2023-10-06 Fixed wrong UTC Offset in TodSlave when Beidou was selected. Fixed wrong constant default value, which was causing potential interrupt flood.
    Updated all pre-compiled binaries
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2023-12-11 TimeCard V27 Updated all NTL Closed source IP Cores to latest version including updated documentation. Added new UCM version which supports the new features in case you have an UART/USB connection to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
    -Clock with Fractional Support
    -Small bugfix with Beidou as time source in the TOD Slave
    -other different small improvements and adaptations
    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
2023-12-19 Added missing IRQ enable for MSI-X with LitePCIe All are enabled by default on the PCIe side
    [ptp_ocp.c]
2023-12-19 Updated to latest LitePCIe version Removed DMA channel for LitePCIe Fixed nanosecond calculation
    [litepcie_core.xdc]
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2024-01-10 ptp_ocp: fix builds on non-x86
    [ptp_ocp.c]
2024-01-10 ptp_ocp: adjust Xilinx SPI driver configuration
    Since Linux 6.3 Xilinx SPI driver allows forced irq mode.
    This is needed for TimeCard to be able to update FW via devlink and
    avoids the need for additional patch.
    [ptp_ocp.c]
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2024-02-09 Updated TimeStick HW
    Updated:
    - back silk text for names
    - added two oscillators
    - added decorative pcie gold fingers to top and bottom
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2024-05-21 Fixed wrong TOD Protocol Name printout
    [ptp_ocp.c]
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2024-08-02 ptp: ocp: adjust tty information exposure
    Starting v6.8 the serial port subsystem changed the hierarchy of devices
    and symlinks are not working anymore. Previous discussion made it clear
    that the idea of symlinks for tty devices was wrong by design. Implement
    additional attributes to expose the information.
    [ptp_ocp.c]
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
